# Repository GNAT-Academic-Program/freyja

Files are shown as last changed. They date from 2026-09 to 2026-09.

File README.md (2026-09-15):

# Odin

An FPGA dev board built on one idea: **remove the accidental complexity, so
what's left is the actual project.**

## Why dumb projects look complicated

Watch a student build a handheld game on a normal FPGA board. Where does the
effort go?

- Writing a memory controller, because the framebuffer doesn't fit in BRAM.
- Fighting the programming workflow, because loading a bitstream is a ritual
  involving a vendor GUI.
- Designing a power supply, because the LCD backlight needs 12V and the board
  offers 3.3V and 5V.
- Level-shifting, because half the parts are 5V.
- Reading a 400-page manual to find which pins share a bank.
- Guessing, when it doesn't work, because the board cannot tell them anything.

Roughly 80% of the effort, and **none of it is the game.** The project isn't
complicated. The scaffolding is. And because the scaffolding is where the time
goes, the finished thing looks far more impressive than the idea deserves —
which is its own kind of failure, because the student learned plumbing instead
of architecture.

## What's actually missing, and what Odin does

| Missing on normal boards | What it causes | Odin |
|---|---|---|
| **A middle rung of memory.** BRAM (KB) → cliff → DDR3 (nightmare) | Every project that outgrows BRAM becomes a memory-controller project | 4× PSRAM, 8 MB, four independent ports, predictable latency |
| **Scriptable programming.** JTAG blaster + vendor GUI | Can't run 40 variants overnight, so nobody experiments | RP-class supervisor owns config; one USB-C, no helper bitstream |
| **Self-observation.** No rail telemetry, no software power control | Superstition-driven debugging | Supervisor drives every enable, reads back every rail |
| **A real expansion standard.** Pmod is 8 pins/3.3V; FMC is a $200 connector and a 400-page spec | Every extension is bespoke, nothing composes | Keyed 16-pin modules, 16/32/64, documented in one page |
| **Rails on the connector.** 3.3V and 5V, take it or leave it | Half of every extension BOM is regulators | Four rails per module: VCCIO, +5V, fixed +3V3, selectable AUX |
| **A level-shifting story.** All-shifted (slow) or none (no 5V parts) | You find out which by burning a part | One buffered slot, eight direct. One table says which and why |
| **Docs a human reads.** 400-page reference manual | Nobody reads it; everyone guesses | One page per subsystem. Over two pages is a bug |

Each row of that table is a decision in this repo, and each one exists to
delete a category of work that was never the point.

## The legibility principle

50 MB/s per link, 2 MB per chip. That's modest. It is also **knowable** — you
can work out on paper, before writing a line of HDL, whether your design fits.

DDR3 offers "up to 12.8 GB/s," qualified by access pattern, bank conflicts,
refresh, and calibration. You cannot reason about it in advance. You build it,
measure it, and find out.

**A legible constraint teaches. An opaque abundance does not.** A student who
computes "640×480 at 60 Hz is 37 MB/s, one PSRAM link is 50, it fits" has
learned something transferable. A student who gets 12.8 GB/s from an IP core
has learned to instantiate an IP core.

This is why the numbers on this board are small and published rather than
large and asterisked.

## The honest ceiling

Odin is not fast. Some things do not fit, and pretending otherwise would
undermine the point:

- **1080p60** RGB565 needs ~249 MB/s. Four chips ganged give ~200. Doesn't fit.
- **720p60** is ~110 MB/s. Fits ganged, with headroom.
- **VGA 60 Hz** is 37 MB/s. Fits on a single link, leaving three ports free.
- Anything wanting sustained gigabytes per second wants DDR3 and a different
  board.

If you need the ceiling raised, this is the wrong board. If you need the floor
raised so you can get to the interesting part, this is the right one.

## The test for any future decision

> Does this remove work that was never the point, or does it add work that
> looks like the point?

Series resistors on shared config lines: removes work (a firmware bug can't
brick the board). Four independent PSRAM buses instead of one shared: removes
work (no arbiter to design). A 400-page pinout PDF: adds work.

Apply it to anything proposed for this board.

## Reference

- [`ref/user-manual.md`](ref/user-manual.md) — start here: powering, extensions, examples and recovery.
- [`ref/extension-ux.md`](ref/extension-ux.md) — the extension connector spec. One page. Read this first.
- [`ref/psram.md`](ref/psram.md) — memory: four independent ports, and why four.
- [`ref/supervisor-flash.md`](ref/supervisor-flash.md) — the supervisor's boot flash, and why you cannot brick it.
- [`ref/power-input.md`](ref/power-input.md) — one USB-C, PD at 9V, and why there is no battery on the board.
- [`ref/power-budget.md`](ref/power-budget.md) — generated: every rail's load, limit and spare, with the basis for each number.
- [`ref/qualified-parts.md`](ref/qualified-parts.md) — generated: the exact part in every non-generic position, and its ratings.
- [`ref/highspeed.md`](ref/highspeed.md) — the two fast serial ports and their reference clock.
- [`ref/gameboy-extension.md`](ref/gameboy-extension.md) — worked example: LCD, speaker, gamepad.
- [`ref/salvage-from-odin0.md`](ref/salvage-from-odin0.md) — what survives from last year's board.
- [`ref/ide-agent-prompt.md`](ref/ide-agent-prompt.md) — the review brief for the implementation agent.
- [`findings.md`](findings.md) — open issues against the current schematic.

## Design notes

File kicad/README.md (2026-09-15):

# Odin KiCad project

**Everything here is generated.** Do not hand-edit the `.kicad_sch` files,
`odin.kicad_sym` or `odin.pretty/` — edit the generators and re-run.

Six pages, one per functional block, from `odin.kicad_sch` (the root):

| Page | Contents |
|---|---|
| `fpga.kicad_sch` | FPGA, decoupling, configuration straps |
| `power.kicad_sch` | input, regulators, monitoring and five protected extension buses |
| `memory.kicad_sch` | PSRAM x4 and configuration flash |
| `supervisor.kicad_sch` | RP2350B, USB-C, flash, links to the FPGA |
| `slots.kicad_sch` | Nine extension slots, rail selection, fusing, shifting |
| `highspeed.kicad_sch` | SFP cages, reference clock, power gate |

Parts are grouped: each regulator sits in a dashed box with its own inductor,
feedback divider and capacitors; each slot with its jumper and its fuses.
Rails and grounds use real power symbols, so only actual signals carry a
label. Rearranging by hand means giving up regeneration — a fair trade once
the design settles, just know that is the moment you make it.

## Regenerate

```bash
python3 tools/gen_kicad.py      # normalize imported XC7A100T symbol + validate FGG676 footprint + custom parts
python3 tools/ballmap.py --write
python3 tools/budget.py --write # rail qualification -> ref/power-budget.md
python3 tools/qualified.py --write   # part table -> ref/qualified-parts.md
python3 tools/audit_easyeda.py # imported symbol/pad/LCSC consistency
python3 tools/gen_project.py    # schematic from tools/design.py
python3 tools/gen_pcb.py        # 6-layer board: outline, stackup, design rules
kicad-cli sch export netlist --format kicadsexpr -o kicad/odin.net kicad/odin.kicad_sch
python3 tools/load_pcb.py       # load every footprint and net into that board
```

`load_pcb.py` reads `kicad/odin.net`, so export the netlist before running it
or you will load the previous revision's parts.

`tools/budget.py --write` currently passes and regenerates the power budget.
The input-voltage issue in findings item 20 is fixed. The command exits
non-zero if a load, input-window or inductor qualification check fails.

**`gen_pcb.py` destroys any routing.** Run it only before you start laying out.
`load_pcb.py` re-imports footprints and nets and is safe to re-run, but it
replaces the footprints, so it also discards placement.

`tools/alloc.py` is the single source for ball allocation; `ref/ballmap.md` and
the schematic both come from it and cannot drift.

## Verify

```bash
kicad-cli sch erc --severity-all -o erc.rpt odin.kicad_sch
kicad-cli pcb drc --severity-all -o drc.rpt odin.kicad_pcb
kicad-cli sch export netlist --format kicadsexpr -o odin.net odin.kicad_sch
```

```bash
kicad-cli pcb drc --schematic-parity --severity-all -o drc.rpt odin.kicad_pcb
```

## Expected ERC

Run from the repository root after regenerating the library and schematic:

```bash
python3 tools/check_erc.py
```

Expected result: **zero errors and exactly two intentional warnings**:

| Rule | Item | Reason |
|---|---|---|
| `global_label_dangling` | `FPGA_DXP` | External temperature-diode terminal is intentionally exposed only as a label. |
| `global_label_dangling` | `FPGA_DXN` | External temperature-diode terminal is intentionally exposed only as a label. |

The U20 JTAG tri-state paths currently produce **no ERC warning**: the
existing series link on TDO separates the FPGA output and bus-switch pin.
There is no U20 blanket exclusion. Any new U20 warning, or any other finding
outside the exact list above, is a regression and makes `check_erc.py` fail.
A change to the expected labels also requires updating this table and the
checker together.

`tools/gen_kicad.py` normalizes imported connector/LED pin types to passive,
models J51 SWCLK/SWDIO (pins 1/3) as bidirectional debugger connections, and
assigns the PCF8574's actual supply, input, bidirectional and open-drain pin
types. J51 ground and mechanical pins remain passive. No project-level
ERC rule is disabled and no ERC exclusion is added.

Latest KiCad 9.0.8 validation: **498 footprints**, with all design values,
footprint IDs and connections synchronized to the PCB. DRC remains separate:
693 violations, 499 unrouted connections and two parity warnings for the
standard SFP symbol's `CAGE` pin missing from its 20-pad electrical connector.
The separate cages are SH1/SH2. See [the validation report](../ref/kicad-validation.md).
Passing the ERC allowlist does not establish fabrication readiness.

## Your workflow from here

1. Open `odin.kicad_pcb`. Its **498 footprints** are synchronized with the
   schematic. The SFP assemblies follow the mechanical placement contract;
   much of the remaining circuitry is still staged outside the board.
2. Complete placement using `tools/placement.py` / `tools/place.py` and verify
   the result in KiCad. The latest placement and validation status is in
   [ref/kicad-validation.md](../ref/kicad-validation.md). Resolve DRC findings
   as well as placement overlaps; the current reports include electrical errors.
3. Route.
4. Fabrication outputs:
   ```bash
   jlcpcb-export -p "$PWD/odin.kicad_pcb" --autoTranslate --autoFill --excludeDNP --noBackup
   ```

## Two checks that ERC and parity cannot do

`ki_fp_filters` catches a footprint that contradicts its symbol. It does not
catch a part that is the wrong part, or one that cannot survive the voltage on
its net. Two generators close that gap and both are enforced from
`tools/design.py`, so the netlist will not build if either fails:

- **`tools/qualified.py`** — MPN, manufacturer package code, footprint,
  ratings that matter here, and how the pin map was confirmed, for every
  non-generic part. A new IC cannot enter the design without an entry.
- **`tools/budget.py`** — per-rail worst-case load, regulator input window,
  inductor ripple, peak current and saturation margin. It fails if any
  inductor saturates below what its rail needs, or if a regulator's source can
  fall below its minimum input.

## LCSC part numbers — read this

Exact LCSC IDs are carried in the generated schematic/netlist for qualified
ICs, connectors and selected passives. Other passive values still need BOM
matching against the required package, tolerance and voltage rating. Use
[the import checklist](../ref/jlcpcb-import-checklist.md) and the generated
[qualified-parts table](../ref/qualified-parts.md); do not substitute a nearby
suffix without checking its package and ratings.

## Board

100 x 100 mm, 6 layer, ENIG, nominal 1.6 mm. Stackup is F.Cu (signal) /
In1.Cu (GND plane) / In2.Cu (signal) / In3.Cu (power planes) /
In4.Cu (GND plane) / B.Cu (signal). The third routing layer supports the
FGG676 inner-ball escape. Keep both ground planes continuous for the GTP
pairs and PSRAM groups.

Dielectric spacings follow [JLC06161H-1080B](https://jlcpcb.com/impedance),
with 0.0764 mm outer prepregs and 0.1 mm cores next to the inner signal and
power layers. The central prepreg/core/prepreg spacer is represented as a
three-sublayer, 1.1208 mm dielectric. Material Dk values and the 100 Ω
geometry come from JLC's calculator tables; see [PCB impedance](../ref/pcb-impedance.md)
for the inputs and saved solver responses. MGT outer tracks use 0.099 mm width /
0.200 mm gap with 0.1 mm maximum intra-pair skew. PSRAM has a 0.1 mm minimum
width; default clearance is 0.15 mm.

Regenerate stackup and rules without replacing placement or routing:
`python3 tools/gen_pcb.py --rules-only`. Net classes live in `odin.kicad_pro`;
DRC constraints live in the generated `odin.kicad_dru`.

A–H are eight logical zones carried by four
continuous 2x16 signal bodies and four parallel 1x16 power bodies; L is one
separate 2x8 connector.
Placement and routing are intentionally not started.

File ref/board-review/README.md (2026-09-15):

# Board review snapshot

Exported 2026-09-15 with KiCad 9.0.8 from the current working-tree board.
This commit records review artifacts; the source hashes in
[board-state.json](board-state.json) identify the exact uncommitted source
state used for export.

- **498 footprints.** Placement is incomplete: 494 footprint origins are
  outside the outline's 100 × 100 mm bounding box (X/Y 30–130 mm).
- **6 copper layers**, in both `odin.kicad_pcb` setup/stackup and
  `tools/gen_pcb.py`: F.Cu / In1.Cu / In2.Cu / In3.Cu / In4.Cu / B.Cu.
  KiCad's loaded copper-layer count also equals 6.
- DRC with **all severities, including exclusions**, plus schematic parity:
  **693 violations, 499 unconnected items, 2 parity issues**. Command exit
  status is 0; this does not mean the board passes fabrication DRC.

## Exports

- [Full DRC report](odin-drc.rpt)
- [DRC command and complete console output](drc-console.txt)
- [Current board SVG: F.Cu + Edge.Cuts + F.CrtYd](odin-placed.svg)
- [SVG command and console output](svg-console.txt)
- [Counts, layer comparison and source SHA-256 hashes](board-state.json)

The SVG includes all staged components outside the outline, rather than
cropping them from the review. No component was moved for this export.

SVG export trailing whitespace was removed; geometry is unchanged.

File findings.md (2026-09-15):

# Odin — findings

Two eras are recorded here. **Items 1–4 are historical** — they describe the
EasyEDA/Altium input set and are closed: the design now lives in `kicad/`,
generated from `tools/`, and those inputs are reference material only. **Items
5 onward are live**, against the current KiCad design.

Regenerate everything with the commands in `kicad/README.md`.

---

# Part I — historical (EasyEDA era, closed)

*Kept for the reasoning, not as open work. The netlist/BOM/pcbdoc revision
mismatch that these describe is moot now that the design is generated.*

## 1. BLOCKER — the netlist, BOM and pcbdoc are the *previous* revision

**Entities:** `Netlist_Odin_0_2026-09-02.net`,
`BOM_Odin_V1.0.0_Odin_0_2026-09-02.xlsx`, `Odin_V1.0.0/Odin_0.pcbdoc`
versus `Odin_V1.0.0/Odin/*.schdoc`.

**What is wrong.** The netlist and BOM agree with each other exactly (0
designators netlist-only, 0 BOM-only) and both agree with the pcbdoc. All
three describe a **single-FPGA ECP5 board programmed over an FT232H**. The
schdoc export describes a **different, later board**: Artix-7 + ECP5 + RP2040
with a new power tree. Only 9 of 40 schdoc part types appear in the netlist
(`odin.srcdiff`).

Present in the schdocs, absent from netlist/BOM/pcbdoc:

| Part | Schdoc symbols | Role |
|---|---|---|
| `XC7A50T-2CSG325I` | 8 | the Artix-7 that Goals 1–2 are about |
| `RP2040_C2040` | 1 | the supervisor that Goal 1 is about |
| `W25Q32JVZPIQ` | 1 | RP2040 boot flash |
| `TPS563257DRLR` | 6 | new buck rails |
| `TPS55340RTER` | 1 | boost |
| `TPS25940ARVCR` | 1 | eFuse |
| `APS1604M-3SQR-SN` | 4 | PSRAM |
| `SN74LXCH8T245PWR` | 4 | level shifters |
| `ADS7950SBRGET` | 1 | ADC |
| `2.54-2*8P_`, `PM2.54-1X8PM-H85`, `ZX-PZ2.54-2-4PZZ`, `PH2.54-01-03PZD` | 6/4/4/4 | new extension headers |

Present in netlist/BOM/pcbdoc, absent from the schdocs: `FT232HQ-REEL`,
`IS61WV25616BLL-10BLI`, `FM25V02A-GTR`, `TLV62569DRLR` ×3, `TPS54202DDCR` ×4,
`TYPE-C-31-E-07`, `TYPE-C-31-M-12`, `PS-1049SVD-4PN`.

**Consequence for the prompt's ground rules.** The prompt makes the Protel
netlist the identity source and forbids citing schdoc refdes. That rule cannot
be satisfied: the netlist contains no Artix-7 and no RP2040, so there is no
real designator to cite for any part in Goal 1. Symbol matching bears this
out — 25 of 230 schdoc symbols map to a netlist part (`odin.desigmap`), and
the matches are confined to the 9 shared part types.

**Proposed change (EasyEDA).** Re-export both the Protel netlist and the BOM
from the schematic that contains the Artix-7 and RP2040 — the one exported to
`Odin_V1.0.0/Odin/`. In EasyEDA Pro the netlist is exported per board, and
`Odin_0` is the old board; the new schematic appears to have no board/PCB yet,
which is why its netlist was never produced. If the new schematic needs a PCB
created before a netlist can be exported, that is the prerequisite step.

---

## 2. BLOCKER — the ECP5 is still instantiated in the new schematic

**Entities:** `LFE5U-25F-6BG256C`, 9 symbol parts on `fpga.schdoc`.

**What is wrong.** You have confirmed the ECP5 is a mistake and the board is
meant to be dual Artix-7. It is not a stray symbol: in the *old* netlist the
same part is `U1` with **170 connected balls**, driven through an
`SN74CB3T3245PWR` level shifter on a `TOL_*` bus. Whatever of that carried
into the new schematic is real wiring, not a placement error, so removing it
is a schematic-scale edit rather than a symbol delete.

**Proposed change (EasyEDA).** Delete the `LFE5U-25F-6BG256C` symbol parts
from `fpga.schdoc` and replace with a second `XC7A50T-2CSG325I`. The second
Artix-7 needs its own config chain — flash, `PROG_B`/`INIT_B`/`DONE`, `M[2:0]`
strap, JTAG — which feeds directly into item 3.

**Blocked on item 1**: I cannot enumerate which nets the ECP5 currently holds
in the *new* schematic, only in the old one.

---

## 3. BLOCKER — RP2040 GPIO count cannot carry Goal 1; assume RP2350B

Per your decision, the review will be run against an **RP2350B (48 GPIO)** and
the swap reported as a blocker. The sizing that forces it, for a dual Artix-7
board with the supervisor scope in Goal 1:

| Function | GPIO |
|---|---|
| Config flash SPI (CS, CLK, MOSI, MISO), shared across both FPGAs | 4 |
| Second flash CS (one CS per FPGA, bus shared) | 1 |
| FPGA A config: `PROG_B`, `INIT_B`, `DONE`, `CCLK`, `DIN` | 5 |
| FPGA B config: same | 5 |
| `M[2:0]` ×2 — driven, not hard-strapped, to switch master-SPI vs slave-serial | 6 |
| FPGA JTAG (TCK/TMS/TDI/TDO), both parts daisy-chained on one port | 4 |
| Fabric sideband JTAG for NEORV32 debug | 4 |
| Sideband UART TX/RX | 2 |
| Spare GPIO bus | 4–8 |
| Regulator enables (8 rails: 6× buck, boost, eFuse) | 8 |
| Power-good readback | 8 |
| Extension board-ID | 2–4 |
| **Total** | **53–59** |

Against 30 on an RP2040 this overflows by roughly 2×; against 48 on an
RP2350B it still overflows unless something gives. The cheapest reductions
that keep the "direct wiring" philosophy:

- **Hard-strap `M[2:0]`** to master-SPI and reach slave-serial by holding
  `PROG_B` and driving `CCLK`/`DIN` only — saves 6, and `M[2:0]` is a
  build-time choice, not a runtime one.
- **Share one JTAG port** across both Artix-7s via the standard daisy chain —
  already assumed above, saves 4.
- **Power-good as a single wired-OR fault line** plus per-rail readback over
  the ADC already on the board (`ADS7950SBRGET`, 12-bit 16-ch) — saves 7,
  and rail voltage readback is strictly better information than a PG bit.

With those three, the count lands near **40**, which fits a RP2350B with
headroom for the spare bus. This is a proposal, not a verified finding —
confirming it needs item 1.

---

## 4. Extension connector keying — the 16-pin unit reads as 14 + 2

You asked me to work out the pattern. From the old netlist, where the
connectors are fully wired, one group is:

- `J4` `2.54-2*7P母` — 2×7 female, **14 pins**
- `H5` `3-644456-2` — 2×1, **2 pins**
- `P3` `2.54-1*1P针` — 1×1 male post, **1 pin**

14 + 2 = **16 pins = 8 columns × 2 rows**, with the 1×1 post as the
polarizing key. There are 8 of each (`J4–J11`, `H5–H12`, `P3–P10`), so the old
board carries **8 × 16 = 128 positions**, i.e. two 64-pin extension sites of
four 16-pin patterns each — which is the 16/32/64 prefix rule you described,
and the split into a 7-column block plus a 1-column block is what makes the
mating polarity unambiguous.

Two cautions. First, this is the **old** board; the new schdocs carry a
different connector mix (`2.54-2*8P_` ×6, `PM2.54-1X8PM-H85` ×4,
`ZX-PZ2.54-2-4PZZ` ×4, `PH2.54-01-03PZD` ×4 alongside the 8× `2.54-2*7P_` and
8× `3-644456-2`), so the new pattern is not yet 14+2. Second, your arithmetic
"8+7+1" counts *columns* and reaches 16 columns (a 2×8 block + a 2×7 block + a
key), which matches the new schdoc's part mix rather than the old board's. If
16 **columns** (32 pins) is the intended unit, then a 64-**column** extension
is 128 pins, and the new mix is the right one. Which of the two — 16 pins or
16 columns — is the unit needs to be your call; item 1 has to land first
either way, since `ref/extension-pinout.md` needs real designators and FPGA
bank data.

---

## Steps not yet run

| Step | Status |
|---|---|
| 0 setup | done — baseline commits, `ref/adabmp` cloned, `extract.py` read |
| 1 netlist-first IR | tooling done; output is of the wrong revision (item 1) |
| 2 FPGA datasheet facts | not started — blocked on the Artix-7 count (item 2) |
| 3 power review | not started — the new power tree is in no netlist |
| 4 config/boot review | not started — no RP2040 in any netlist |
| 5 extension connector | not started — see item 4 |
| 6 Gameboy gap analysis | not started — depends on step 5 |
| 7 BOM check | partial — the BOM is self-consistent with the old netlist; every placed part has an LCSC number; see below |

**Step 7, valid only for the old revision.** Zero JLCPCB stock:
`TC211A106M016Y` (C128289, 10 parts) and `CA45-A6R3K226T` (C122912, 4 parts).
Near-zero: `RT1206FRE07120KL` (C136861, stock 9), `2NM27000C33YC` (C668764,
stock 3), `1SMA5918A` (C19077487, stock 71), `FT232HQ-REEL` (C82158, stock 28)
— the FT232H is being removed anyway. 51 of 56 BOM lines are Extended Part;
only `0603WAF8202T5E`, `0603WAF5101T5E`, `0603WAF200JT5E` are Basic. Most of
the Extended lines are ordinary 0402/0603 passives with Basic equivalents;
that consolidation pass is worth doing once the BOM is re-exported, not now.

---

---

# Part II — live, against the current KiCad design

## 5. FIXED — differential oscillator pinout confirmed

**Entities:** `X2`, `DSC1123CI2-125.0000` (`C617173`), footprint
`EasyEDA:OSC-SMD_6P-L3.2-W2.5-BL`.

The Microchip datasheet and imported part agree: 1 EN, 2 NC, 3 GND, 4 OUT+,
5 OUT-, 6 VDD. This differs from the old assumed mapping; the schematic now
uses the imported exact symbol and footprint.

## 6. FIXED — MGTRREF was connected to the wrong rail

**Entities:** `R35` (formerly `R30`), 100R 1% 0603, from `U1.A15`
(`MGTRREF_216`, FGG676) to `+1V2_MGT` (MGTAVTT).

The old circuit used 100R to GND with no explicit tolerance. The ground
connection was wrong. [UG482 v1.9, Figure 5-1 and pp. 217–219](https://0x04.net/~mwk/xidocs/ug/ug482_7Series_GTP_Transceivers.pdf#page=218)
specifies 100 ohm, 1% to MGTAVTT for Artix-7 GTP calibration, not 499/500 ohm
to GND. The design source, schematic, netlist and PCB now specify `100 1%`
and connect the resistor to the 1.2 V MGT supply. This closes the schematic
error; high-speed link performance still requires hardware validation.

## 7. FIXED — board outline now matches the mechanical contract

`kicad/odin.kicad_pcb` is now 100 x 100 mm, matching the required board size.
A–H use four continuous 2x16 signal bodies plus four parallel 1x16 power
bodies (two logical zones per body), plus two complete 5V-bus signal and power
connector pairs. Placement
and routing remain deliberately absent. The exact stack-through connector MPN
is still a mechanical purchasing choice; the schematic fixes 2.54 mm pitch.

## 8. FIXED — nonexistent extension board-ID promise removed

**Entities:** `ref/extension-ux.md`, the nine slot connectors, `PD_CFG1..3`.

An earlier `ref/extension-ux.md` stated that each module had board-ID pins so
the supervisor could tell what was plugged in. **It had none.** The four
`BOARDID_*` nets that existed went to the supervisor and a pull-down each and
reached no connector; they have since been repurposed for the USB-PD sink,
which genuinely needed them.

The options considered were:

1. **Give up one I/O per module** for a strapped ID pin.
2. **Drop the claim.** Extensions are identified by the human. Honest, and
   costs nothing but the feature.
3. **Widen the module** solely to add identification.

Option 2 was chosen. The claim and dead nets are gone. The newer third power
row is used for clear, well-grounded power distribution, not to silently
reintroduce an identification protocol. The supervisor still power-gates the
extension rails and reports SFP module identity.

## 9. FIXED — the supervisor could not enable its own power rail

`EN_3V3` was driven by supervisor GPIO21 and gated `U12`, which produced the
+3V3 that powers the supervisor. A deadlock: the board could never start.
`EN_5V` compounded it, since +3V3 was derived from +5V.

Fixed: +3V3 is now always on, from a wide-input `AP63300` (`U12`) straight off
`VSYS`. Its datasheet permits automatic startup with EN floating, so no GPIO
is involved. GPIO21 was freed and reused for the VBUS pass switch below.

## 10. FIXED — a Schottky from VBUS to the 5V rail was an overvoltage hazard

`D2` fed USB `VBUS` into the +5V rail so the board could run from a plain 5 V
source. The moment the PD sink negotiated 9 V, that diode would have put
~8.6 V onto a rail feeding four `TLV62569` regulators rated 5.5 V maximum —
destroying them on the first PD handshake.

Fixed: replaced with a supervisor-commanded high-side switch (`Q2` P-MOS,
`Q3` gate driver), **default open**. Firmware measures `VSYS` and only closes
it when the input really is 5 V.

## 11. CLOSED — level translator pinout confirmed

**Entities:** `U9`, `U10`, symbol `odin:SN74LXC8T245PW`.

The original `SN74AVC8T245PW` was wrong: the AVC family is specified for
1.2–3.6 V supplies and 5 V on `VCCB` exceeded its absolute maximum. It has been
replaced with `SN74LXC8T245PW` (1.1–5.5 V both rails).

KiCad ships no symbol for it, so the generated one is AVC8T245's symbol
renamed. That mapping has since been checked against TI's TSSOP-24 pinout for
`SN74LXC8T245PW` — 1 `VCCA`, 2 `DIR`, 3–10 `A1..A8`, 11–13 `GND`, 14–21
`B8..B1`, 22 `OE`, 23–24 `VCCB` — and matches. **Closed.**

## 12. FIXED — two complete 5V buses replace the 8+2 orphan

`SN74LXC8T245` is direction-controlled: one `DIR` pin steers eight signals
together. An earlier Slot L was an eight-bit bus plus an awkward two-bit tail,
costing 12 FPGA I/O for ten connector signals. A two-bit Nexperia converter
was briefly qualified for that tail, but optimizing the orphan did not fix the
interface. Odin now provides two identical complete eight-bit 5V buses, each
with one direction control. The second bus uses fixed bank 13.

`ref/extension-ux.md` now says this plainly. If per-pin bidirectional 5 V is
actually wanted, the part is a `TXB0108`-class auto-direction translator,
which trades away drive strength and forbids external pull-ups. There is no
option that gives strong drive, per-pin direction and 5 V at once.

## 13. partly fixed — qualify the placeholder components before layout

Inductor saturation current and capacitor voltage rating are not purchasing
details — a 22 µF 6.3 V part on the 12 V AUX rail fails immediately, and an
undersized inductor saturates under load. These need real part numbers
**before layout**, not before ordering, because package size affects
placement.

**Done since:**

- **A qualified-parts table exists and is enforced.** `tools/qualified.py`
  records MPN, manufacturer package code, footprint, the ratings that matter
  on this board, and how the pin map was confirmed, for every non-generic
  part. `tools/design.py` refuses to build if a part is missing from it or is
  fitted with a different footprint, so a new IC cannot enter the netlist
  anonymously. Rendered to `ref/qualified-parts.md`.
- **Every inductor is selected and checked.** `tools/budget.py` computes the
  ripple, peak current and required saturation current per rail and names the
  part: `SRN6045TA-100M` (10 µH, Isat 4.6 A) on `U11` and the boost,
  `SRN6045TA-4R7M` (4.7 µH, Isat 6.8 A) on `U12`, `SRN4018-2R2M`
  (2.2 µH, Isat 3.0 A) on the four `TLV62569`s,
  `SRN4018-1R0Y` on the MGT filter, and the mandated Abracon part on the
  supervisor. The tool fails if any of them saturates below its rail's
  requirement.
- **MOSFETs are real parts.** `Q1` and `Q2` are `DMG2305UX`; `Q3` is a
  `BSS138`. Reading the DMG2305UX datasheet is what turned up item 21.
- **Capacitors on rails above 3.3 V carry their rating in the value field**,
  set automatically from the net rather than typed: `25V` on `VSYS`, `VBUS`
  and `+12V`. Everything unmarked is 16 V minimum, X5R or better.

**Still open:**

- The SFP electrical connectors are selected; their separate metal cages are
  still not encoded because the `C5164658` mechanical import failed.
- The nine 300 mA +3.3 V polyfuses still need an exact MPN. The 200 mA and
  500 mA positions are selected.
- **Capacitor DC-bias derating is not accounted for.** A 22 µF 25 V X5R 0805
  at 12 V retains well under half its nominal value. The bulk capacitance is
  ample enough that this is unlikely to bite, but "22 µF" on the `VSYS` rail
  means perhaps 8 µF in circuit and nothing in the design says so yet.
- The ~340 ordinary passives can take LCSC numbers later via the JLCPCB
  plugin.

## 14. open — the 16/32/64 mechanical claim is unproven

Adjacent 16/32/64 module compatibility is a *mechanical* property: it depends
on slot pitch, board-edge geometry and the position of the keying posts, none
of which exist until placement. The electrical numbering supports it. Verify
it on the board, and until then treat the claim in `ref/extension-ux.md` as an
intent rather than a fact.

## 15. FIXED — the JTAG owner is now selected in hardware

`J2` sits directly in parallel with the FPGA's JTAG nets. The supervisor is
separated only by its 33 R series resistors, so an external programmer and a
misbehaving supervisor GPIO can both drive the same line. The comment claiming
a jumper isolates the supervisor was wrong and has been corrected.

Two ways to make it true:

1. **Firmware contract** (currently assumed): the supervisor tri-states
   GPIO0–3 whenever an external programmer may be attached, and does so as its
   *reset default*, not only when asked. Free, but it depends on firmware
   being correct — which is a poor guard for a debug path you reach for
   precisely when things are broken.
2. **A bus switch** (`SN74CB3T3245`, the part Odin_0 used) between the
   supervisor and the JTAG net, with its enable strapped or jumpered. Real
   isolation. Costs one part and one control line, and there is no spare
   supervisor GPIO — it would have to be a physical jumper.

Recommendation: option 2 with a jumper, because "hold the board in a known
state so I can debug it" should not itself depend on working firmware.

**Fixed with option 2.** `U20` is an `SN74CB3Q3384APW` 10-bit FET bus switch;
the supervisor's four JTAG lines pass through bank 1 (`1A1..1A4` to
`1B1..1B4`) on their way to the FPGA and to `J2`. `~{1OE}` is held low by a
10 k pull-down, so the switch is closed and the supervisor owns JTAG in the
shipped state — that is the primary programming path and it has to work out of
the box. Fitting **`EXT JTAG` (`J52`)** pulls `~{1OE}` to +3V3
and takes the supervisor electrically out of the chain, whatever its firmware
is doing. The controlling net is named `EXTERNAL_JTAG_SELECTED`, so its high
state says exactly what happened.
Bank 2 is unused with `~{2OE}` tied high.

This adds one intentional ERC warning: the FPGA's `TDO` output meets a
tri-state switch pin, which is what a FET bus switch pin always looks like to
ERC.

## 16. FIXED — RP2350 support parts now match the reference design

`U7`'s internal switcher uses a generic `3.3uH SRN4018` inductor and generic
15 pF crystal loading capacitors. Raspberry Pi's hardware-design guide is
explicit that RP2350's on-chip regulator depends on the prescribed inductor
selection, orientation and placement, and on specific capacitor choices.

This is a **netlist-level** task, not a layout note: copy the exact component
values and manufacturer part numbers from the RP2350B minimal-board reference
into `tools/design.py`, then follow the placement guidance during layout.
Getting this wrong produces a supervisor that mostly works, which is the worst
failure mode available.

**Fixed, from RP-008280 sections 2.1, 2.2.1, 3 and 4:**

| Reference | What it is | Now in the netlist |
|---|---|---|
| `L1` | `AOTA-B201610S3R3-101-T`, the 3.3 µH part Abracon made for Raspberry Pi with a polarity dot | `L1`, on a generated `odin:L_Abracon_AOTA-B201610S_2.0x1.6mm` land taken from the datasheet's Recommended Land Pattern (1.00 × 1.60 mm pads, 1.00 mm gap) |
| `C6`, `C7`, `C9` | 4.7 µF 0402 at `VREG_VIN`, at the output, and on `VREG_AVDD` | three 4.7 µF 0402 |
| `R3` | 33 Ω, RC-filtering the analogue supply | 33 Ω 0402 into net `SUP_VREG_AVDD` |
| `Y1` | `ABM8-272-T3`, 12 MHz, CL 10 pF, ESR 50 Ω max | named in the value field |
| `R2` | **1 kΩ in series with `XOUT`**, so the crystal is not over-driven | added; it was missing entirely |
| `C3`, `C4` | 15 pF at the crystal terminals | were already right, and now sit on the crystal side of `R2` |
| `R1` | 10 kΩ pull-up on `QSPI_SS`, shipped Do-Not-Fit | added, DNP |
| decoupling | one 100 nF per supply pin | 11 on +3V3 (8 IOVDD, QSPI_IOVDD, USB_OTP_VDD, ADC_AVDD) and 3 on +1V1 (3 DVDD) |

The 1 kΩ `XOUT` resistor is the important one: without it the crystal is
over-driven, which is a slow reliability failure rather than an obvious one.

**Still a layout obligation.** Raspberry Pi are explicit that the regulator's
performance depends on the inductor's *orientation* as well as its part
number, and on their exact placement. The footprint carries a polarity dot on
silk and a solid pin-1 marker on `F.Fab` so the requirement survives into the
assembly drawing, but honouring it is placement work, guided by RP-008280
Figure 4.

## 17. FIXED — eleven components had footprints for the wrong package

Symbol and footprint disagreed on the physical package for `U2`–`U6`, `U8`,
`U13`–`U16`, `U17`, `U18`, `U19` and `D6`. Neither ERC nor schematic parity can
see this class of error; it surfaces at assembly.

Corrected: PSRAM to SOP-8 150 mil, `W25Q256JVEIQ` to WSON-8 8x6, `W25Q32JVZP`
to WSON-8 6x5, `TLV62569DRL` to SOT-563, `CH224K` to SSOP-10-1EP, `PCF8574T`
to SOIC-16W, `TPS61085PW` to TSSOP-8 4.4x3, `ESDA6V1BC6` to SOT-23-6.

**Prevented from recurring:** `Design.add()` now checks every footprint against
the symbol's `ki_fp_filters` and refuses to build on a mismatch. The one
deliberate exception is the polyfuse, where KiCad ships no `*polyfuse*`
footprint and a 1206 chip PTC is the physically correct package; that override
is explicit in the source and carries its reason.

## 18. FIXED — per-slot fuse ratings implied nine times the available current

Nine slots x 500 mA suggested 4.5 A per rail. The real sources are far
smaller. Fuse ratings have been rebalanced (AUX 200 mA, +3V3 300 mA, +5V
500 mA) and `ref/extension-ux.md` states the shared budget per rail
explicitly, with the note that fuses are fault protection and not an
allowance.

The `~700 mA` first quoted for AUX was `5 V x 2 A x η / 12 V` — an ideal
upper bound from a nominal switch rating, not an available current. It has
been replaced by TI's own design procedure (SLVS859B equations 1–4) at the
worst-case input, run by `tools/budget.py`:

- the boost, with a 10 µH inductor at 650 kHz and the **2.0 A minimum**
  switch limit, can deliver **622 mA**;
- but AUX at full output draws 1766 mA from a +5 V rail with 1615 mA spare,
  so the binding limit is **570 mA**, and the constraint is the 5 V rail, not
  the boost;
- and that is still arithmetic at an assumed 90% efficiency with no thermal
  derating, so it is published as a **provisional design target**.

The inductor changed as part of this: 4.7 µH at 650 kHz sat outside TI's
recommended 6–13 µH range and gave 69% ripple. 10 µH gives 26% ripple *and*
more output current.

Every other shared-rail figure was equally unsubstantiated. `+3V3` was
described as having "~1.5 A spare"; the worst-case load table puts it at
**500 mA**, because `U12` also carries the supervisor, four PSRAMs, the config
flash, FPGA bank 14, the oscillator, two SFP modules (610 mA on their own) and
both VCCIO domains when they are jumpered to 3.3 V. See
`ref/power-budget.md`.

## 19. constraint — firmware must never request more than 9 V over USB-PD

`D7` is an `SMBJ13A`, a 13 V standoff TVS on `VBUS`. The `CH224K`
configuration pins are supervisor-driven, so this limit lives in firmware and
must be an assertion there, not a comment. Raising the ceiling means
re-selecting `D7` first.

Two corrections to how this was first written. The mechanism is **avalanche,
not forward conduction**: the part is unidirectional with its cathode on
`VBUS`, so a 20 V contract drives it into sustained reverse breakdown, which a
600 W *transient* device does not survive as a DC condition. Forward
conduction is what happens if it is fitted backwards, which is a different
failure — and the reason the schematic no longer uses KiCad's bidirectional
`Device:D_TVS` symbol. And the margin is narrower than "13 V" suggests but not
zero: `VBR` is 14.4 V minimum, so a 15 V contract sits in the region above the
rated standoff where leakage climbs steeply rather than in hard avalanche.

## 20. FIXED — the always-on +3V3 rail now starts on a weak 5 V port

**Entities:** `U12` (`AP63300WU-7`), `D3`, `U26`, net `VSYS`.

The original `TPS54202` needed 4.5 V at its input, while the weak-host path
could provide only about 4.24 V after protection and OR-ing. It was therefore
wrong for the one rail that must always start.

`U12` is now an `AP63300WU-7`, rated from 3.8–32 V and 3 A. The worst-case
path is now:

| | |
|---|---|
| `VBUS` on a weak host port, guaranteed minimum | 4.75 V |
| less `D3` forward drop | −0.45 V |
| less conservative `U26` on-resistance drop | −0.03 V |
| **`VSYS`** | **4.27 V** |
| `AP63300` minimum input voltage | **3.8 V** |

That leaves 0.47 V of startup margin. Its 3.3 V feedback network, 4.7 µH
inductor, input capacitor, three output capacitors, bootstrap capacitor and
feed-forward capacitor copy the manufacturer's reference circuit.
`tools/budget.py` checks its full load and inductor peak current and passes.

## 21. FIXED — Q2 gate overvoltage under a 9 V firmware fault

**Entities:** Q2 (DMG2305UX), Q3, R49, EN_VBUS5.

R49, between VBUS5_PULL and VBUS5_GATE, is now **47k**, replacing 10k.
Together with the existing 100k gate-source pull-up, it sets
`VGS = -VBUS * 100/(100+47)`: -3.40 V at 5 V and -6.12 V at 9 V.
Even 9.45 V with 1% resistor tolerances gives only 6.47 V magnitude,
below the [DMG2305UX's ±8 V gate limit](https://www.diodes.com/datasheet/download/DMG2305UX.pdf).

The weaker gate drive at 5 V increases on-resistance compared with -4.5 V
characterization. With the existing 100nF gate-source capacitor, the gate
RC time constant becomes approximately **3.20ms**; it is not a specified
linear output ramp or current limiter. Firmware must still forbid turning
Q2 on at 9 V, because doing so overvolts the +5V rail and its loads.

## 22. FIXED — screw-terminal input lacked a transient clamp

**Entities:** J50, new D8, VIN_EXT, D4, VSYS.

Added **SMBJ15A-13-F / C135046** on VIN_EXT, before D4, with cathode on
VIN_EXT and anode on GND. The standard SMB footprint uses pad 1 cathode,
pad 2 anode. Put it at J50 with a short, wide surge-current return to J50 GND.

[Diodes rates this unidirectional TVS](https://www.diodes.com/part/view/SMBJ15A)
at 15 V standoff, 16.7–19.2 V breakdown, 24.4 V maximum clamp at its rated
pulse current, and 600 W pulse power. It suppresses transients; it is not a
15 V regulator or a sustained-overvoltage disconnect. A bench supply left
at 24 V can still overload the TVS. The permitted input remains **9–14 V**;
continuous fault protection would require current limiting/fusing or cutoff.
PCB parasitic overshoot and surge energy still require validation.

## 23. FIXED — the `VSYS` monitor divider overdrove the supervisor's ADC

**Entities:** `MON_VSYS`, `MON_5V`, `GPIO40/ADC0`, `GPIO41/ADC1`.

The divider was 100 k / 33 k, which is 33/133 of the input. At 9 V that reads
2.23 V and is fine. At the 20 V `ref/power-input.md` then permitted on `J50`
it reads **4.96 V** — onto an RP2350 GPIO whose maximum is `ADC_AVDD`, 3.3 V.
A rail monitor that destroys the microcontroller in the fault it exists to
report is the wrong way round.

Fixed by sizing every monitor divider from an **absolute maximum**, not a
nominal:

| Monitor | Divider | Nominal reading | At absolute maximum |
|---|---|---|---|
| `MON_VSYS` | 100 k / 16 k | 1.24 V at 9 V | 2.76 V at 20 V |
| `MON_5V` | 100 k / 47 k | 1.60 V at 5 V | 2.88 V at 9 V |

`MON_5V` was 100 k / 100 k, safe at 5 V and 4.5 V in the same firmware fault
item 21 describes; it is now sized for that fault too.

`tools/design.py` computes both from `adc_divider()`, which rounds the bottom
resistor **down** through E24 — rounding to nearest can put the result back
over the ceiling — and raises if the absolute maximum would exceed 3.0 V.
E24 rather than E96 because firmware calibrates a monitor ratio, so precision
buys nothing and stock availability buys something.

Each of the six monitor nodes also gained a 100 nF capacitor. Two reasons: the
ADC's sample-and-hold needs charge that a 14 kΩ Thevenin divider cannot
supply, and firmware compares these readings against thresholds, so switching
ripple should not be in them.

## 24. FIXED — USB attach inrush exceeded the specification by 5x

**Entities:** `U26`, `D3`, `VBUS`, `VSYS`.

USB limits a device's `VBUS` bypass capacitance to 10 µF, or 50 µC of inrush
charge; USB-PD raises that to `cSnkBulkPd` = 100 µF only *after* a contract
exists, and at cable insertion there is no contract. The board presented
10 µF on `VBUS` plus 44 µF of `VSYS` bulk through a forward-biased `D3` —
about 54 µF and 270 µC, five times the allowance. Symptoms would have been
source droop, connector arcing, and starting reliably on some chargers and not
others.

Fixed with `U26`, a `TPS259470A` eFuse. Its 2.2 nF `dVdt` capacitor sets an
approximately 0.91 V/ms output rise, so 44 µF charges at about 40 mA. It is
autonomous rather than firmware-controlled: this path produces +3V3, which
firmware needs in order to exist. UVLO is about 3.75 V, OVLO about 9.98 V and
the typical current limit about 2.03 A. The 10 µF left directly on `VBUS` is
the attach allowance, spent deliberately.

`Q2` has a series gate resistor and 100 nF gate-source capacitor because
closing it connects `VBUS` to 66 µF of +5V bulk. R49 is now 47k (item 21),
giving a 3.20ms gate RC time constant with the 100k pull-up. This provides
slew control, not a specified inrush-current limit.

Unlike the passive RC, the eFuse also controls PD voltage-transition current
and disconnects on an overvoltage request. `D7` remains the independent TVS;
firmware must still enforce the 9 V PD ceiling in item 19.

## 25. FIXED — extension power faults could reach the base-board rails

**Entities:** `U21`–`U25`, `EXT_EN`, `EXT_FAULT`, all slot power PTCs.

Every connector rail previously branched directly from an internal rail. A
short, back-powered shield or large startup capacitor could therefore pull
down or energize the FPGA, supervisor and memories through the shared source.

There are now five protected connector buses. Four `TPS22950CDDCR` switches
protect +5 V, +3V3 and the two selectable VCCIO domains. A
`TPS259470LRPWR` protects +12 V with true reverse blocking, 13.2 V nominal
OVLO, a 500 mA typical limit, controlled rise and latch-off. All switches have
a hardware-default-off `EXT_EN`; their fault outputs wire-OR to `EXT_FAULT`.
The old per-slot PTCs remain downstream.

`TPS22950C` has an off-state output-discharge path. With an extension applying
5 V, its nominal 160 Ω path draws about 31 mA and dissipates about 0.16 W;
reverse current into the internal source remains blocked. Its output absolute
maximum is 6 V, so this closes the stated 5 V-on-low-rail mistake, not an
arbitrary 12 V miswire. That boundary is now explicit in the user documents.

## 26. FIXED — larger FPGA has a 4 A 1.0 V supply

**Entities:** `U1`, `U15`, the +1V0 inductor, the future FPGA image.

`U1` is now `XC7A100T-2FGG676I` (`C1521803`) in the imported 676-ball,
27 x 27 mm package. Its 676 symbol pin numbers match all 676 footprint pads,
every supply ball is connected. Both GTP supply groups remain powered:
G10 serves quad 213 and G11 serves quad 216 (UG482 Table 5-2).

The unused-quad wiring is now corrected in `tools/gen_sch.py:net_for()`.
Quad 213 has all eight RX pins grounded and its own 100R 1% resistor (`R89`)
from `MGTRREF_213` to MGTAVTT; its TX and reference clocks float. Quad 216's
unused lanes 2/3 also have their RX pins grounded and TX pins floating.
These follow [UG482 Tables 5-5 and 5-6](https://0x04.net/~mwk/xidocs/ug/ug482_7Series_GTP_Transceivers.pdf#page=223).

U15 is now a 4 A `SY8047QDC` (`C3018651`) with its datasheet reference circuit
and a 1 uH `FTC201610S1R0MBCA` (`C5832342`). At the conservative 1.5x FPGA
transient target, calculated peak inductor current is 2.80 A and the project's
required saturation rating is 3.64 A; the fitted inductor is rated 4.60 A.
The power audit passes. AMD XPE remains useful before fabrication, but it is
no longer needed to justify an undersized regulator.

## 27. FIXED — press-fit SFP cages replaced with solder-tail cages

**Entities:** SH1/SH2, J60/J61, `tools/placement.py`.

TE 2007198-1 was a press-fit part unsuitable for the requested JLC solder
assembly. SH1/SH2 now use **Amphenol U77A11133001 / C5355132**, which JLC lists
as Extended with wave soldering for Economic and Standard PCBA. The
standalone cage's host-board pattern matches the TE connector datum, so
**1888247-1 is retained** and no integrated connector/cage replacement is
needed. A new drawing-based `odin` footprint replaces the old cage import.

The connector depth is **35.40 mm from PCB edge** (34.50 to cage datum F,
then 0.90 to the locating-peg centreline), or 42.40 mm from the cage mouth.
The mouth overhang is 7.00 mm. Placement now uses an explicit edge-datum
origin and correct relative cage/connector rotations. TE's two connector
locating holes are also corrected from the import's 1.70 mm plated holes
to the specified 1.55 mm NPTH.

Amphenol lists this cage at **2.5 Gb/s**; the old TE cage's 16 Gb/s rating
is not retained. Higher-rate operation remains unqualified. See
[the source drawings, comparison and assembly notes](ref/sfp-cage.md).

## 28. FIXED — DONE LED loaded the open-drain configuration signal

**Entities:** CFG_DONE, R7, D1, new R98 and Q4, SUP_DONE.

D1 previously drew current directly from DONE through 330 ohms. Its brightness
and the DONE high level therefore depended on the weak pull-up or an actively
driven DONE output. The circuit no longer uses DONE as an LED supply.

R98 adds 4.7k from CFG_DONE to +3V3 (bank 0 VCCO). Q4, BSS138LT1G / C82045,
has gate on CFG_DONE, source on GND and drain on D1's cathode. The LED current
path is +3V3 → R7 (330 ohms) → D1 → Q4 → GND. With the specified green LED's
2.0–2.6 V forward drop, expected current is approximately 2–4 mA. DONE sees
the MOSFET gate and the existing supervisor input path, not that LED current.
The added pull-up draws about 0.70 mA when DONE is held low.

No `DriveDone=Yes` requirement is imposed on reference bitstreams. The LED
illuminates when DONE is released high and extinguishes when DONE is low;
SUP_DONE retains its existing connection. This follows the default open-drain
behavior described in [AMD UG470](https://docs.amd.com/v/u/en-US/ug470_7Series_Config).
Q4's low-voltage switching rating is checked against the
[onsemi BSS138LT1/D datasheet](https://www.onsemi.com/pdf/datasheet/bss138lt1-d.pdf).
The LED reports the DONE level, not application health, and is not a reliable
indicator during supply ramp-up.

## 29. FIXED — PUDC_B low strap was too weak

R6 is now **1k** (0402, C11702), from PUDC_B to GND, replacing 4.7k.
This follows the ≤1k strap recommendation in
[AMD UG470, Configuration Pins](https://docs.amd.com/v/u/en-US/ug470_7Series_Config)
and retains the intended internal I/O pull-ups during configuration.
Generator, schematic, netlist and PCB are synchronized; R6's connections
and physical placement are unchanged.

## 30. FIXED — two SFP EEPROMs collided on the shared I2C bus

**Entities:** J60/J61, U27, C231, R99–R103, SFP_SCL/SFP_SDA.

Both modules formerly connected their fixed-address 0x50 EEPROMs directly
to the same bus. Added **PCA9543APW,118 / C2652904** at 0x70, with one
channel per cage and separate downstream pull-ups. Both modules can remain
powered while firmware enumerates them separately. This chooses the mux
option; Q1 and U17 P7 retain shared power control. Documentation now states
that power removal affects both ports.

Select 0x01 or 0x02, finish selection with STOP, then read 0x50; never
select 0x03. Deselect with 0x00 before shared power-off. RESET is tied to
SUP_RUN, providing a hardware recovery path if a module holds I2C low;
a software controller reset alone may leave the mux selected. These rules,
startup handling and stuck-bus limits are in [sfp-i2c.md](ref/sfp-i2c.md),
with the NXP datasheet and procurement links. Firmware remains to be written.

## 31. FIXED — PSRAM series termination was documented but absent

Added **R104–R127**, 24 populated 33 ohm 0402 resistors (C25105), one on
each port's SCK, CE_B and IO0–IO3. FPGA-side nets and ball allocation remain
unchanged. Each resistor connects its original FPGA net to a distinct `_MEM`
net at the PSRAM; connectivity checks verify there is no direct bypass.

The generator, schematic, netlist and PCB are synchronized. `tools/place.py`
places the resistor bank at U1's right-hand escape edge instead of beside
the memory chips. Exact positions still require escape routing. 33 ohms is
a bring-up value; FPGA-end damping does not establish source termination
for PSRAM-driven reads or guarantee 100 MHz timing. The tuning and placement
requirements are in [ref/psram.md](ref/psram.md).

## 32. FIXED — +12V_EXT lacked local output capacitance

Added **C232, 10uF 25V**, 0805 X5R, Samsung CL21A106KAYNNNE / C15850,
from U25 OUT (+12V_EXT) to GND, before the selectors and branch PTCs.
The generator now explicitly rates capacitors on +12V_EXT at 25V.
Existing designators and connections are preserved. C232 belongs to U25's
placement group and must sit close to its OUT pin and ground return.

At the existing approximately 20ms output ramp, the nominal added charging
current is about 6mA; extension capacitance remains additional. The capacitor
provides local output charge storage, not a substitute for extension-side
decoupling. The selected part's voltage and package are confirmed by
[LCSC C15850](https://www.lcsc.com/product-detail/C15850.html).

## 33. FIXED — no supervisor/user indicators and unused core power-good

U17 P0/P1/P2 now sink three green LEDs (D9/D10/D11), labeled CTRL HB,
USER 1 and USER 2, with individual 1k resistors R128–R130 from +3V3.
They default off, need no extra supervisor GPIOs, and use the same qualified
LED as DONE. P3 now reads CORE_1V0_GOOD with its existing 100k pull-up.
P7 retains shared SFP power control; P4–P6 remain unused.

The [firmware contract](ref/status-leds.md) requires a shadow output byte,
P3–P6 always written high, and masked updates so heartbeat/user LEDs cannot
change SFP power or drive PG low. PG polling and LED control share the SFP
upstream bus, so a stuck bus also stops heartbeat updates. This implements
the hardware; supervisor firmware and physical placement/routing remain.

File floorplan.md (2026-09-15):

# Odin floorplan and placement contract

**Generated intent doc for `tools/placement.py` / `tools/place.py`. The code
is authoritative; this page says why.**

## Zones

```text
        SFP0  SFP1        J50   USB-C          top:    cages nose out,
  E  +--------------------------------+  A            input corner right
  F  |  cages intrude to y=41.98       |  B     left:   slots E-H (bank 34,
     |        [ XC7A100T ]            |               package columns 1-8)
  G  |        centre (50,62)          |  C     right:  slots A-D (bank 15,
  H  |  supervisor row      5V buses  |  D            columns 14-26)
     +--------------------------------+        bottom: service row, U7,
       JTAG SWD BOOT   J7/L    J8/M                   5V buses L and M
```

## The lattice (the actual contract)

Signal rows, power row and key post of every extension edge sit on ONE
2.54 mm grid, because a shield PCB bridges all three:

- signal 2x16 centreline 4.70 mm from its edge, rows at 3.43 / 5.97
- power 1x16 centreline 13.59 mm (inner signal row + 3 pitches)
- key post 18.67 mm (inner signal row + 5 pitches)
- body centres at 26.50 and 73.50 along each edge; zone centres +/-10.16
  within each body

`tools/place.py --check` verifies from real pad coordinates that the left
and right sockets expose identical y-lattices (bottom pair: x-lattices) and
that the three rows stay on the grid. It refuses to write a board that
breaks this. It also prints the column-facing convention; copy that line
into `ref/extension-ux.md` once and it is a fact, closing findings item 14
for the electrical part. Stack height remains a mechanical purchase choice.

## SFP mechanical datums

SH1/SH2 use the solder-tail Amphenol U77A11133001 with TE 1888247-1
connectors. The cage footprint origin is the PCB-edge datum at y=0;
its mouth is at y=-7.00 and shell rear at y=41.98. J60/J61 locating-peg
centrelines are at **y=35.40**, derived from cage datum F at 34.50 plus
TE's 0.90 connector offset. Cage rotation is 270°, connector rotation 180°.
See [the drawing comparison](ref/sfp-cage.md).

The shell extends above the SVG's original view; the renderer includes the
full mouth overhang. Anchor positions remain starting values for eye-tuning.
The cage's front region excludes top-side components and signal traces;
several existing group anchors under the cages still need relocation before
applying the full floorplan. This change updates the four SFP placements only.

## Reasoning already burned in

- Bank 34 balls (E-H) are on package columns 1-8, banks 15/13/14 on 14-26,
  so E-H own the left edge and A-D the right; the 5V buses (banks 14/13) and
  the supervisor sideband exit the bottom. No slot escape crosses the die.
- GTP balls are on rows A-F (top of the die); the cages face them across a
  approximately 6.2 mm channel. Refclk oscillator sits at the channel's right end.
- The BGA sits below centre because the cages intrude 41.98 mm from the top.
- USB-C and J50 keep the top-right corner: VBUS parts, PD sink and the
  regulator row anchor there, one entry point for all power.

## PSRAM termination placement

`tools/place.py` places R104–R127 in a column just outside the FPGA's right
edge (15.4 mm from U1 centre, 1 mm pitch), ordered by their associated ball
row/column. Their pad 1 faces the FPGA. This rule keeps them out of the
PSRAM-chip group packing; refine their positions as escape routing develops.
See [the PSRAM layout note](ref/psram.md) for net names and tuning limits.

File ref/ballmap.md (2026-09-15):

# XC7A100T-FGG676 ball map

Generated by `tools/ballmap.py` from `tools/alloc.py`, which is the one
place ball allocation is decided. The schematic is generated from the same
function, so this file and the circuit cannot disagree. Package facts come
from the imported `XC7A100T-2FGG676I` symbol, LCSC `C1521803`.

```
python3 tools/ballmap.py > ref/ballmap.md
```

## I/O-bank architecture

This package has **six HR I/O banks** — 13, 14, 15, 16, 34 and 35 — 300 user I/O total.
`VCCO` is shared by every pin in a bank. Odin uses bank 14 at fixed 3.3V,
bank 13 for 5V BUS 1, banks 15 and 34 as selectable extension domains, and reserves
banks 16 and 35 for later base-board peripherals.

| Bank | HR I/O | Diff pairs | MRCC | SRCC |
|---|---|---|---|---|
| 13 | 50 | 24 | 4 | 4 |
| 14 | 50 | 24 | 4 | 4 |
| 15 | 50 | 24 | 4 | 4 |
| 16 | 50 | 24 | 4 | 4 |
| 34 | 50 | 24 | 4 | 4 |
| 35 | 50 | 24 | 4 | 4 |

**Bank 14 is not free.** It carries the master-SPI config flash pins and the
`PUDC_B` strap, so its `VCCO` is pinned at 3.3V by the flash. That makes it
the home for everything else fixed at 3.3V — PSRAM, the supervisor sideband,
and 5V BUS 0. Bank 13 carries 5V BUS 1. Banks 15 and 34 are the two settable extension
domains, four slots each. The other two HR banks are powered at 3.3V but
carry no signals in this revision.

## Allocation

| Bank | VCCO | Contents |
|---|---|---|
| 14 | **fixed 3.3V** | config flash, PSRAM x4, supervisor sideband, 5V BUS 0 |
| 13 | fixed 3.3V | 5V BUS 1 |
| 15 | **settable** 3.3 / 2.5 / 1.8 | slots A B C D |
| 34 | **settable** 3.3 / 2.5 / 1.8 | slots E F G H |
| 16, 35 | fixed 3.3V | reserved for future base-board peripherals |

## Config flash and strap

| Ball | Net | Package name |
|---|---|---|
| R14 | `FLASH_D0_MOSI` | IO_L1P_T0_D00_MOSI_14 |
| R15 | `FLASH_D1_MISO` | IO_L1N_T0_D01_DIN_14 |
| P14 | `FLASH_D2_WP` | IO_L2P_T0_D02_14 |
| N14 | `FLASH_D3_HOLD` | IO_L2N_T0_D03_14 |
| P18 | `FLASH_CS_B` | IO_L6P_T0_FCS_B_14 |
| P15 | `PUDC_B` | IO_L3P_T0_DQS_PUDC_B_14 |

`CCLK`, `PROGRAM_B`, `INIT_B`, `DONE`, `M[2:0]` and JTAG are bank 0
dedicated pins — see the bank 0 table below.

## PSRAM — four independent QSPI buses

| Chip | SCK | CE# | IO0 | IO1 | IO2 | IO3 |
|---|---|---|---|---|---|---|
| PSRAM0 | N16 | N17 | R16 | R17 | K25 | K26 |
| PSRAM1 | M20 | L20 | L24 | L25 | M24 | M25 |
| PSRAM2 | L22 | L23 | M21 | M22 | N21 | N22 |
| PSRAM3 | P20 | P21 | N23 | N24 | P19 | N19 |

Each chip's six lines come from three adjacent differential pairs, so the
group stays physically tight and length matching stays local.

## Supervisor sideband

| Ball | Net |
|---|---|
| P23 | `DBG_TCK` |
| P24 | `DBG_TMS` |
| R20 | `DBG_TDI` |
| R21 | `DBG_TDO` |
| R25 | `SB_UART_RX` |
| P25 | `SB_UART_TX` |

## Extension slots

Direct slots A-H expose twelve ordinary numbered I/O as six adjacent
differential-capable pairs. Pairing remains
an optional capability rather than part of the basic connector UX.
5V BUS 0 and 5V BUS 1 each expose one complete translated 8-bit bus.

| Slot | Bank | FPGA balls in connector order |
|---|---|---|
| **L** | 14 | N26, M26, T24, T25, R26, P26, T22, R22 |
| **M** | 13 | U25, U26, V26, W26, AB26, AC26, W25, Y26 |
| **A** | 15 | K15, J16, J14, J15, K16, K17, M14, L14, M15, L15, M16, M17 |
| **B** | 15 | J19, H19, L17, L18, K20, J20, J18, H18, G20, G21, K21, J21 |
| **C** | 15 | H21, H22, J23, H23, G22, F22, J24, H24, F23, E23, K22, K23 |
| **D** | 15 | G24, F24, E25, D25, E26, D26, H26, G26, G25, F25, J25, J26 |
| **E** | 34 | K3, J3, M7, L7, M4, L4, L5, K5, N7, N6, M6, M5 |
| **F** | 34 | K1, J1, L3, K2, N1, M1, H2, H1, M2, L2, N3, N2 |
| **G** | 34 | R3, P3, P4, N4, R1, P1, T4, T3, T2, R2, U2, U1 |
| **H** | 34 | P6, P5, T5, R5, U6, U5, R8, P8, R7, R6, T8, T7 |

The two 5V buses are buffered; A-H are direct. M19, U24 are their direction controls. Together the buses cost **20** FPGA I/O for 16 connector signals.

| Bus control | FPGA ball | Bank | Default |
|---|---|---|---|
| `BUS5V0_OE_N` | P16 | 14 | 10k to +3V3; high disables the bus |
| `BUS5V1_OE_N` | Y25 | 13 | 10k to +3V3; high disables the bus |

Hold OE_N high while setting DIR and data; drive OE_N low only when ready.
Raise OE_N again before changing direction.

## Bank 0 — dedicated configuration pins

| Ball | Name |
|---|---|
| AB15 | `CFGBVS_0` |
| AB7 | `M0_0` |
| AE16 | `PROGRAM_B_0` |
| G14 | `VCCBATT_0` |
| H10 | `TDI_0` |
| H11 | `TMS_0` |
| H12 | `TCK_0` |
| H13 | `CCLK_0` |
| J10 | `TDO_0` |
| M11 | `GNDADC_0` |
| M12 | `VCCADC_0` |
| N11 | `VREFN_0` |
| N12 | `VP_0` |
| P11 | `VN_0` |
| P12 | `VREFP_0` |
| R11 | `DXN_0` |
| R12 | `DXP_0` |
| V11 | `INIT_B_0` |
| W10 | `DONE_0` |
| W11 | `VCCO_0` |
| W9 | `M2_0` |
| Y14 | `VCCO_0` |
| Y9 | `M1_0` |

## Bank 216 — two connected GTP transceivers

Lanes 0 and 1 go to the two SFP ports. Lanes 2 and 3 have RX grounded
and TX floating; unused reference-clock inputs float (UG482 Table 5-6).
See `ref/highspeed.md`.

| Ball | Name |
|---|---|
| A11 | `MGTPRXN0_216` |
| A13 | `MGTPRXN2_216` |
| A15 | `MGTRREF_216` |
| A7 | `MGTPTXN0_216` |
| A9 | `MGTPTXN2_216` |
| B11 | `MGTPRXP0_216` |
| B13 | `MGTPRXP2_216` |
| B7 | `MGTPTXP0_216` |
| B9 | `MGTPTXP2_216` |
| C10 | `MGTPTXN3_216` |
| C12 | `MGTPRXN3_216` |
| C14 | `MGTPRXN1_216` |
| C8 | `MGTPTXN1_216` |
| D10 | `MGTPTXP3_216` |
| D12 | `MGTPRXP3_216` |
| D14 | `MGTPRXP1_216` |
| D8 | `MGTPTXP1_216` |
| E11 | `MGTREFCLK0N_216` |
| E13 | `MGTREFCLK1N_216` |
| F11 | `MGTREFCLK0P_216` |
| F13 | `MGTREFCLK1P_216` |

## Bank 213 — unused GTP transceivers

The G10 supplies remain powered. All eight RX pins connect to GND;
MGTRREF_213 connects through its own 100 ohm, 1% resistor to +1V2_MGT.
TX and reference-clock pins float, per UG482 Table 5-5.

## Budget

- slots: **96**
- PSRAM: **24**
- supervisor sideband: **6**
- config flash + strap: **6**
- 5V bus data: **16**
- 5V bus direction: **2**
- 5V bus enable: **2**
- **assigned HR I/O: 152 of 300**
- **free: 148** for base-board peripherals

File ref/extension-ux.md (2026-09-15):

# Odin extension connector — the whole spec

If you are building an extension, this page is all you need.

## The module

One **module** = one 16-position signal connector (2×8, 0.1") plus its
separate 8-pin power row on **each of two opposite edges**. An extension is a
shield that bridges the 100 x 100 mm base board:

```text
16:       [ A ]================[ E ]
32:   [ A ][ B ]============[ E ][ F ]
64: [ A ][ B ][ C ][ D ]==[ E ][ F ][ G ][ H ]
```

The name is the connector width on each side:

- a **16** bridges one signal block on each edge: **24 I/O**;
- a **32** bridges two signal blocks on each edge: **48 I/O**;
- a **64** bridges four signal blocks on each edge: **96 I/O**.

The schematic divides each edge into four 16-pin electrical sections: A-D on
one edge and E-H on the other. That does **not** require four separate plastic
headers. The generated schematic and board use the original arrangement of **two
continuous 32-pin stack-through signal headers on each edge**, with a parallel
continuous 32-pin single-row power header. The 16-position boundaries are
labels that let a small shield occupy part of those headers.

That gives the extension support at both ends and most of the board area above
Odin. Each shield carries female sockets underneath and matching male pins on
top, so another shield can stack over it.

Matching pairs are A/E, B/F, C/G and D/H. Placement must put every pair
directly opposite, at identical pitch and orientation. This mechanical fit is
not proven until the base board, a reference shield and the stacking height
are laid out together.

```text
             1     2     3     4     5     6     7     8
signal row 1 IO0   IO2   IO4   IO6   IO8   IO10  GND   GND
signal row 2 IO1   IO3   IO5   IO7   IO9   IO11  GND   GND
power row    GND   PIN V GND   3V3   GND   5V    GND   SLOT PWR
```

The two signal rows contain 12 ordinary numbered I/O and four grounds. The
third row contains all power and four more grounds. Power is never hidden
between signal pins.

**The guide is a separate post,** not the header itself: a 1x1 pin beside each
slot with a matching hole in the extension. A bare 2x8 header cannot stop reversed
insertion on its own, and pretending otherwise would be the expensive kind of
wrong. This is the same trick Odin_0 used.

Treat the pins as ordinary `IO0..IO11`. The FPGA allocation preserves six
adjacent differential-capable pairs per slot. Pairing is an optional electrical
capability, not the connector's identity. The exact pair map is in
`ref/ballmap.md` for extensions that genuinely need it.

## The four rails, and why you are never blocked

| Pin | Rail | Fixed or set | What it is for |
|---|---|---|---|
| Power 2 | **PIN V** | **set per group: 3.3 / 2.5 / 1.8V** | Powers your voltage-matching logic and sets the FPGA pin voltage. |
| Power 6 | **+5V** | fixed | Crappy 5V parts, LCD backlights, servos. |
| Power 4 | **+3V3** | fixed | Always there even when PIN V is 1.8V. Power your sensor here. |
| Power 8 | **SLOT PWR** | set beside this slot: **+12V / +5V / +3V3** | Motors, relays, op-amps or backlights. |

**+3V3 is fixed on purpose.** If PIN VOLTAGE is set to 1.8V you still have a
normal 3.3V supply for the part you are powering. Signalling level and supply
rail are separate problems and this is the pin that keeps them separate.

## PIN VOLTAGE changes the pins — this is the important bit

An FPGA pin has no fixed voltage. Pins live in **banks**, and a bank's `VCCO`
supply *is* the logic level of every pin in it. Odin calls the connector pin
`PIN V`; the schematic's technical net name is `VCCIO`. One jumper changes
both the FPGA pins and the power delivered on `PIN V`.

So: jumper the module to 2.5V and you get a 2.5V rail on B7… and IO0–IO9
become 2.5V pins, LVDS-capable. Jumper it to 3.3V and they are 3.3V pins.
**The rail on the connector and the logic level of the pins can never
disagree.** You do not have to know this to use the board. That is the point.

## The slots, and the two voltage domains

Ten extension ports: eight direct sections and two complete 5V buses. The
`XC7A100T-FGG676` has six HR I/O banks. This board deliberately
uses two as the extension voltage domains: bank 15 for A-D and bank 34 for E-H.
Bank 14 stays fixed at 3.3V for flash, memory, control signals and 5V BUS 0.
5V BUS 1 uses fixed-3.3 V bank 13. Banks 16 and 35 remain reserved. Therefore this
revision has **two settable extension domains**:

| Slots | FPGA group | PIN VOLTAGE | Path |
|---|---|---|---|
| **5V BUS 0** | 14 | fixed 3.3V | **buffered**, 5V compatible |
| **5V BUS 1** | 13 | fixed 3.3V | **buffered**, 5V compatible |
| **A B C D** | 15 | **settable** 3.3 / 2.5 / 1.8V | direct |
| **E F G H** | 34 | **settable** 3.3 / 2.5 / 1.8V | direct |

| You plug in a | You get | PIN VOLTAGE |
|---|---|---|
| **16** (1 module) | 12 IO per edge, 24 total | shares each domain with 3 neighbours |
| **32** (2 modules) | 24 IO per edge, 48 total | shares each domain with 2 neighbours |
| **64** (4 modules) | 48 IO per edge, 96 total | **owns both domains outright** |

**Only a 64 gets a private voltage.** If your extension needs 2.5V or 1.8V
signalling, build it as a 64 and take a whole bank, or agree the voltage with
whatever else is sharing your domain. Two extensions at different voltages
means one in the A–D domain and one in E–H.

## The two 5V buses

5V BUS 0 and 5V BUS 1 are identical complete eight-bit buses. Each uses one
`SN74LXC8T245`, accepts 3.3 V on the FPGA side and 5 V on the connector side,
and has one direction control for all eight signals. Each also has a separate
FPGA-controlled `OE_N`, pulled up to +3V3 by 10k so the bus is disabled during
configuration. Set direction and data with OE_N high, then drive OE_N low to
enable; disable again before changing direction.

They are not eight unrelated bidirectional GPIOs: all eight bits on one bus
turn around together. Use them for parallel displays, legacy byte-wide parts
and other 5 V buses. Use A-H when pins need independent direction.

| | 5V BUS 0/1 | Slots A–H |
|---|---|---|
| 5V tolerant | **yes** | no (3.3V max) |
| Speed | moderate | full FPGA speed |
| LVDS | no | **yes, 5 pairs** |
| Direction | shared per complete 8-bit bus | per pin, it is a raw FPGA ball |
| VCCIO | fixed 3.3V | settable per domain |

**Junk 5V parts?** Use either 5V BUS. BUS 0 shares fixed bank 14; BUS 1 uses
fixed bank 13. Neither consumes a selectable extension voltage domain.
**Anything fast, or needing per-pin direction?** Any of A–H.

## Differential-capable pins

The connector is an ordinary numbered-I/O interface. Underneath that simple
view, six selected adjacent pin pairs per slot are routed to FPGA pair-capable
balls. Use the pairing only when it helps; consult the ball map instead of
assuming every column is a pair. A 0.1" header is not a precision
high-speed connector, so keep aggressive links short and set PIN V to 2.5V
for true LVDS output from an Artix-7 HR bank.

## How much current you actually get

**The per-slot fuses are fault protection, not an allowance.** Nine slots x
500 mA does not mean the board can source 4.5 A. Each rail has one source, and
all ten extension ports share it:

| Rail | Source | **Shared total, all slots** | Per-slot fuse |
|---|---|---|---|
| VCCIO | protected separately for A-D and E-H | **500 mA typical per domain**, subject to source headroom | 500 mA |
| +5V | `TPS54202`, or USB directly, then protected switch | **1.0 A typical** | 500 mA |
| +3V3 | `AP63300`, then protected switch | **limited to 500 mA typical at the connector bus** | 300 mA |
| **AUX 12V** | `TPS61085`, then latch-off eFuse | **500 mA typical** | 200 mA |

Those numbers are computed, not estimated round figures: every one of them
comes out of [`ref/power-budget.md`](power-budget.md), which
`tools/budget.py` generates from a worst-case load table and the regulators'
datasheet limits. Three things about them are worth knowing before you design
against them.

**+3V3 is the tight one, not AUX.** It carries the supervisor, the PSRAMs, the
config flash, FPGA bank 14, the oscillator, both SFP modules, and both VCCIO
domains if you jumper them to 3.3 V. That leaves 500 mA for all extension ports. Two
SFP modules alone are 610 mA of it — power them down and you get that back.

**AUX and +5V share a pot.** The 12 V rail is boosted *from* +5 V, and at 12 V
out each milliamp of AUX costs 2.8 mA of +5 V. The boost itself could manage
620 mA; the +5 V rail can only feed 570 mA of it, and every milliamp a slot
takes from its +5 V pin comes off that. One backlight is fine. Nine motors are
not.

## What a bad extension can do

Connector power does not come directly from Odin's internal rails. Five
shared protection channels sit before the existing slot fuses: +5V, +3V3,
VCCIO for A-D, VCCIO for E-H, and AUX 12V. They start off, limit startup and
short-circuit current, block power flowing backward into Odin, and report one
shared `EXT_FAULT` signal. A fault can turn off every slot using that shared
bus. It does not turn off the FPGA, memories, supervisor or internal rails.

This protects Odin's **power pins**. It does not make A-H signal pins tolerate
5 V. Only 5V BUS 0 and 5V BUS 1 have translated 5 V-compatible signals.

**On a plain 5 V source the +5V ceiling is the USB port, not the regulator.**
1.6 A assumes `U11` is running, which needs 9 V. Plugged into a weak laptop
port you have 0.9 A total for the whole board. If your extension needs real
current, feed it from `J50` and do not take it from the connector.

**AUX is marked provisional deliberately.** 570 mA is arithmetic on datasheet
limits at 90% assumed efficiency; it ignores thermals and board droop. Treat
it as a design target until a board has been measured.

And remember the whole board is limited by what the USB source gives you —
see `ref/power-input.md`.

## Rules

- **The 1.0V FPGA core never reaches a connector.** Do not look for it.
- Every rail is individually fused. Shorting your extension does not take the
  board down.
- **Not implemented yet:** board-ID pins. All 16 positions are spoken for, so
  there is nowhere to put them without giving up an I/O. See `findings.md`
  item 8. The supervisor still fuses and power-gates every rail; it just
  cannot yet tell *what* you plugged in.
- IO are numbered globally `IO_1..IO_112`: eight on each 5V bus, then twelve
  on each direct slot A-H, so every port's identity is readable from the net name.
- Exact FPGA ball for every pin: `ref/ballmap.md`.
- Where every current figure above comes from: `ref/power-budget.md`.

## Confirmed against the package file

Bank count, pair count and every ball assignment come from the imported
`XC7A100T-2FGG676I` symbol and are processed by `tools/ballmap.py`. Six HR
banks provide 300 user I/O. The generated `ref/ballmap.md` is authoritative.

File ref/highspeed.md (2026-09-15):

# The two fast ports

The `XC7A100T-FGG676` has two four-lane GTP quads. This revision wires two
lanes in quad 216. The FPGA supports up to ~6.6 Gb/s per lane, but the
selected Amphenol cage is listed at 2.5 Gb/s; higher-rate operation is
unqualified. Unused RX lanes are grounded and unused TX lanes float. Ordinary pins
are roughly a hundred times slower. These are the only thing on Odin an
extension board can never add later, because a signal that fast dies in a
0.1" pin header — it needs a real connector and controlled-impedance copper on
the base board.

## Don't spend them on video

Tempting, but wrong. The Artix-7 drives HDMI at 1080p60 from **ordinary I/O**
using TMDS — no fast lane required. Video belongs on an extension board or on
spare base-board I/O. Spend the fast lanes on what ordinary pins genuinely
cannot do: multi-gigabit serial.

## Built: SFP cages

An SFP cage is a socket you plug a **module** into — which is the same idea as
Odin's extension slots, one level up. One socket, many personalities:

| Module | What you get | Rough cost |
|---|---|---|
| Copper 1000BASE-T | An RJ45 ethernet port | ~$15 |
| Fibre (many kinds) | 550 m to 80 km, pick the module | $8–40 |
| Direct-attach copper | A fixed cable, board to board or to a switch | ~$10 |
| Loopback plug | Test your link with no other hardware | ~$5 |

You wanted two ethernet ports. This gives you two ethernet ports **and** fibre
**and** board-to-board, and the base board never has to choose which.

**There are two ports, full stop.** Lanes 0 and 1 reach them. Lanes 2 and 3 do
not create empty connectors, fake choices or assembly noise.

## What makes it UX-smart

Every SFP module carries an identification chip you read over a two-wire bus.
U27 selects one module’s two-wire bus at a time, so firmware can identify
both modules despite their shared EEPROM address, 0x50. This enables the
planned self-describing interface —
exactly like the board-ID pins on the extension slots:

- **Planned identity reporting.** Supervisor firmware can report: `SFP0: FS
  1000BASE-T copper, s/n …` / `SFP1: empty`. No guessing, no label squinting.
- **It knows when something is inserted or removed.** Each cage has presence,
  transmit-fault and rate-select pins. All go to the supervisor.
- **The supervisor controls power to both ports together.** A module fault
  requiring power removal shuts down both links. U27 isolates management
  traffic; it does not provide independent power shutdown.
- **Three board status LEDs** on U17: supervisor heartbeat and two user
  indicators, with [software control](status-leds.md). They are not dedicated
  per-cage FPGA LEDs.

Management uses the shared upstream I²C bus plus per-port control/status
pins. See [the selection and recovery contract](sfp-i2c.md).

## The honest limits

- **The selected cage is listed at 2.5 Gb/s.** The FPGA lane ceiling is
  ~6.6 Gb/s, but it does not qualify the complete port at that speed. Match
  the module line rate and FPGA design; higher-rate operation needs separate
  qualification. See [cage qualification](sfp-cage.md).
- **The socket is not the hard part.** You still need a gigabit ethernet core
  in the fabric. Open ones exist, and Xilinx ships one, but standing up a
  working link is a project measured in weeks, not an afternoon. The board's
  job is to make sure that project is *possible* — which it is not at all if
  these lanes go nowhere.
- **Board area.** A cage is roughly 14 mm wide and 47 mm deep. The two ports
  take about 28 mm of one edge.

## What is actually in the schematic

| Ref | Part | Note |
|---|---|---|
| `J60`, `J61` | TE 1888247-1 electrical connector | lanes 0 and 1 |
| `SH1`, `SH2` | Amphenol U77A11133001 solder-tail cage | C5355132, JLC wave solder |
| `X2` | 125 MHz differential oscillator | the reference clock the lanes need |
| `Q1` | P-channel high-side switch | gate pulled high, so cages are **off until the supervisor turns them on** |
| `U17` | SFP power controller | shared default-off power control, address 0x24 |
| `U27` | PCA9543APW,118 I²C switch | address 0x70; separate EEPROM channels |
| `R35` | `MGTRREF` precision resistor | 100R 1%, 0603, to `+1V2_MGT` (MGTAVTT); findings item 6 fixed |

Coupling capacitors sit in series on all eight high-speed lines. Status lines run to the supervisor. Each two-wire identification bus has
its own pull-ups and reaches the supervisor through a separate U27 channel.
Both G10 (quad 213) and G11 (quad 216) remain powered. `R89` provides quad
213 with its own 100R 1% 0603 resistor from `MGTRREF_213` to `+1V2_MGT`.
All eight RX pins in quad 213 and the four RX pins of unused lanes 2/3 in
quad 216 connect to GND. Unused TX and reference-clock pins float, per
[UG482 Tables 5-5 and 5-6](https://0x04.net/~mwk/xidocs/ug/ug482_7Series_GTP_Transceivers.pdf#page=223).

The oscillator is selected and pin-checked. `MGTRREF` uses 100 ohm, 1% to
MGTAVTT per [UG482 v1.9, Figure 5-1](https://0x04.net/~mwk/xidocs/ug/ug482_7Series_GTP_Transceivers.pdf#page=218).

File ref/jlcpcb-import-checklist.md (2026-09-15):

# JLCPCB / EasyEDA import checklist

The imported library is in `easyeda/` beside `kicad/`. The checked parts below
are now linked from the textual design by exact footprint and LCSC number.
`python3 tools/audit_easyeda.py` verifies those links, symbol pin numbers and
footprint pad numbers every time the design changes.

An imported symbol and footprint are evidence, not proof. Before use, Odin
must compare pin numbers, exposed pads, package dimensions and orientation
against the manufacturer datasheet.

## Imported parts

| Qty | Manufacturer part number | Used for | Known LCSC number |
|---:|---|---|---|
| 1 | `XC7A100T-2FGG676I` | programmable logic | `C1521803` — imported |
| 4 | `APS1604M-3SQR-SN` | work memory | `C18214056` |
| 1 | `W25Q256JVEIQ` | FPGA startup memory | `C97522` |
| 1 | `RP2350B` | board controller | C42415655 |
| 1 | `ABM8-272-T3` | controller 12 MHz crystal | C20625731 |
| 1 | `W25Q32JVZPIQ` | controller memory | `C571260` — imported and linked |
| 1 | `HC-TYPE-C-16P-01A` | USB-C connector | C2894897 |
| 1 | `ESDA6V1BC6` | USB data/CC protection | C495220 |
| 1 | `SMBJ13A` from a named manufacturer | USB power surge protection | C133675 |
| 1 | `CH224K` | USB power request | C970725 |
| 1 | `B3U-1000P` | controller boot button | C231329 |
| 1 | `SN74CB3Q3384APWR` | JTAG owner switch | C469874 |
| 2 | `SN74LXC8T245PWR` | Two complete 8-bit 5 V buses | C4363995 |
| 2 | `DMG2305UX` | switched power | C5261054 |
| 2 | `BSS138LT1G` (onsemi) | Q3 power-switch drive; Q4 DONE LED buffer | C82045 |
| 1 | `TPS259470ARPWR` | USB input protection | C3662799 |
| 3 | `SS34` from a named manufacturer | power diodes | C8678 |
| 1 | `TPS54202DDCR` | 5 V supply | `C191884` |
| 1 | `AP63300WU-7` | always-on 3.3 V supply | C2158012 |
| 3 | `TLV62569DRLR` | 2.5/1.8/1.2 V supplies | `C163217` |
| 1 | `SY8047QDC` | 4 A FPGA 1.0 V supply | `C3018651` — imported and linked |
| 1 | `TPS61085PWR` | 12 V slot-power supply | C13505 |
| 4 | `TPS22950CDDCR` | low-voltage slot-power protection | C7587833 |
| 1 | `TPS259470LRPWR` | 12 V slot-power protection | C3662793 |
| 1 | `AOTA-B201610S3R3-101-T` | controller 1.1 V inductor | C42411119 |
| 1 | `VLS252010HBX-1R0M-1` | FPGA transceiver filter | `C88211` — imported and linked |
| 3 | `SRN4018-2R2M` | 2.5/1.8/1.2 V supply inductors | `C913207` — imported and linked |
| 1 | `FTC201610S1R0MBCA` | FPGA 1.0 V supply inductor | `C5832342` — imported and linked |
| 10 | `SMD1206B020TF/24` | 12 V slot PTC, 200 mA | `C269111` — imported and linked |
| 20 | `SMD1206B050TF` | 5 V and pin-voltage PTC, 500 mA | `C269115` — imported and linked |
| 10 | `BSMD1206-030-16V` | 3.3 V slot PTC, 300 mA | `C22378340` — imported and linked |
| 1 | `DSC1123CI2-125.0000` | 125 MHz LVDS clock | `C617173` — imported, pin map confirmed and linked |
| 2 | `1888247-1` | SFP/SFP+ 20-contact connector | `C305914` — imported and linked |
| 2 | `U77A11133001` | SFP cage, 3.2 mm solder tails | `C5355132` — JLC Extended, wave solder; drawing-based `odin` footprint |
| 2 | `SRN6045TA-100M` | 5 V and 12 V supply inductors | C2046332 |
| 1 | `SRN6045TA-4R7M` | 3.3 V supply inductor | C2044594 |
| 1 | `2.54-2*5P` | keyed FPGA JTAG header | `C5665` — imported and linked |
| 1 | `BM03B-SRSS-TB(LF)(SN)` | keyed controller SWD header | `C160389` — imported and linked |
| 1 | `KF301-5.0-2P` | 9–14 V external power terminal | `C474881` — imported and linked |
| 4 | `F.0603.00025/P2-0603G1TS2-06T-002` | green DONE, heartbeat and two user LEDs | `C7496818` — imported and linked |
| 13 | `F254D-02-PT-B` | removable 2.54 mm selector shunts | `C501335` — imported; loose accessory |
| 1 | `PCA9543APW,118` | two-channel SFP I²C switch | `C2652904` — generated symbol, standard TSSOP-14 footprint; JLC Economic/Standard PCBA |
| 1 | `PCF8574T_3,518` | SFP control I/O expander | `C7605` — imported and linked |

Import the exact orderable suffix shown. A nearby family member in the same
search result is not interchangeable.

## Import audit result

The fitted design currently uses **129 instances** backed by the EasyEDA
library. Their connected schematic pin numbers exist in both the imported
symbol and imported footprint, and their LCSC identities agree.

The imported TPS259470 footprint was rejected: its pad geometry violates the
board's 0.20 mm copper clearance in 18 places. `U25` and `U26` keep KiCad's
official TI `RPU0010A` footprint; their exact LCSC numbers remain in the
schematic and BOM. An imported file is not automatically better than the
manufacturer-package footprint.

The slot fuses, SFP cages and complete extension connector system are selected,
linked and audited. Only ordinary passive BOM matching remains below.

## SFP cage assembly

SH1/SH2 use [Amphenol U77A11133001, C5355132](https://jlcpcb.com/partdetail/AmphenolICC-U77A11133001/C5355132).
JLC lists Extended, Wave Soldering, and Economic and Standard PCBA support
(checked 2026-09-15). Assemble the SMT TE 1888247-1 connector before the cage;
select the through-hole wave-solder operation in the assembly order. Stock and
assembly pricing must be refreshed when ordering.

The cage symbol and footprint are generated from Amphenol's drawing, **not an
EasyEDA import**. Twenty plated shield holes connect to GND. The retained
connector import has its two locating holes corrected to 1.55 mm NPTH per TE
1888247 sheet 3. Mechanical datums, assembly clearance and the manufacturer's
**2.5 Gb/s listing** are documented in [sfp-cage.md](sfp-cage.md). The old
16 Gb/s cage qualification does not transfer to this part.

## Extension hardware — imported and linked

| Item | Selected part |
|---|---|
| four 2x16 signal sockets | `C3975161` — imported and linked |
| four 1x16 power sockets | `C7499334` — imported and linked |
| two 5V-bus 2x8 signal sockets | `C3975153` — imported and linked |
| two 1x8 power sockets | `C27438` — imported and linked |
| ten guide/key posts | `C42431799` — imported and linked |
| twelve 2x3 selectors | `C65114` — imported and linked; `C501335` shunts are loose accessories |
| one 1x2 external-JTAG selector | `C492401` — imported and linked; uses a `C501335` shunt |

## PSRAM series resistors

R104–R127 are 24 populated 33 ohm 0402 resistors, **C25105**, one per
SCK/CE_B/IO0–IO3 signal across the four PSRAM ports. They use standard KiCad
resistor footprints. Keep them in the assembly BOM; these are tuning parts,
not optional unpopulated links.

## +12V_EXT output capacitor

C232 is **10uF 25V**, Samsung CL21A106KAYNNNE / **C15850**, X5R, 0805.
It connects U25 OUT (+12V_EXT) to GND before the selectors and PTC branches.
Place it beside U25; the 25V rating is explicit in the generated BOM value.

## Input protection additions

- D8: **SMBJ15A-13-F**, Diodes Incorporated, **C135046**, unidirectional
  TVS in standard KiCad `Diode_SMD:D_SMB`; cathode pad 1 to VIN_EXT.
- R49: **47k**, 0603, Q2 gate pulldown path; retain the 100k source pull-up.
  Use 1% resistors for the documented divider tolerance calculation.

## Ordinary resistors and capacitors

These do not need imported custom symbols or footprints. They do need exact
LCSC stock numbers in the BOM.

Prefer Basic or Promotional Extended parts, but only after matching:

- package: 0402, 0603 or 0805 exactly as designed;
- resistance/capacitance and tolerance;
- capacitor dielectric: X5R or X7R;
- voltage rating: 16 V minimum unless the schematic explicitly says 25 V;
- effective capacitance after DC-bias derating, especially 10 uF and 22 uF;
- power rating for resistors in dividers and current-setting networks.

The ordinary parts are **not release-ready yet**. The values and package sizes
exist, but LCSC numbers and capacitor DC-bias checks are still missing. Do not
bulk-assign the cheapest search result.

## What to send back after importing

For every imported part, retain:

1. manufacturer part number;
2. LCSC number;
3. EasyEDA symbol;
4. EasyEDA footprint;
5. datasheet link;
6. whether JLCPCB currently marks it Basic, Promotional Extended or Extended.

Then Odin can replace library references systematically and run symbol-pin,
footprint, ERC, power-budget and schematic-parity checks again.

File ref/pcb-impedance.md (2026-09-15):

# PCB routing rules and impedance

`python3 tools/gen_pcb.py --rules-only` regenerates the stackup, project net
classes and `kicad/odin.kicad_dru` while preserving placement and routing.
Without that flag the generator creates an empty board.

## Selected fabrication stackup

**JLC06161H-1080B**, 6 layers, nominal 1.6 mm, 1 oz outer / 0.5 oz inner,
ENIG: Sig / GND / Sig / PWR / GND / Sig.
Sources: [JLC stackup table](https://jlcpcb.com/impedance) and
[JLC impedance calculator](https://jlcpcb.com/pcb-impedance-calculator),
retrieved 2026-09-15. The calculator template ID is
`44d74b19da284af7ae31a739dbf6b16b`.

| Dielectric between copper layers | Thickness, mm | Material | Dk |
| --- | ---: | --- | ---: |
| F.Cu / In1.Cu | 0.0764 | NP-155F 1080 RC67% | 3.91 |
| In1.Cu / In2.Cu | 0.1000 | NP-155F core | 4.36 |
| In2.Cu / In3.Cu, first sublayer | 0.2104 | NP-155F 7628 RC49% | 4.40 |
| In2.Cu / In3.Cu, middle sublayer | 0.7000 | NP-155F core | 4.53 |
| In2.Cu / In3.Cu, last sublayer | 0.2104 | NP-155F 7628 RC49% | 4.40 |
| In3.Cu / In4.Cu | 0.1000 | NP-155F core | 4.36 |
| In4.Cu / B.Cu | 0.0764 | NP-155F 1080 RC67% | 3.91 |

The material-specific calculator table supplies the core Dk values above;
the general stackup page's generic core Dk is 4.6. The central spacer has
three explicit dielectric sublayers in KiCad. Nominal copper thicknesses are
0.035 mm outer and 0.0152 mm inner.

## 100 Ω differential calculation

Use coated edge-coupled microstrip on **F.Cu referenced to In1.Cu**, or
**B.Cu referenced to In4.Cu**. Keep those reference planes continuous.
The calculator model is `DiffEdgeCoupledCoatedMicrostrip1B`.
Its current copper and solder-mask parameter tables were used, including
the 0.5 oz base-copper row for finished 1 oz outer copper:

| Solver input | Value |
| --- | ---: |
| H1 | 0.0764 mm |
| Er1 | 3.91 |
| Finished trace thickness T1 | 1.6 mil (0.04064 mm) |
| Etch taper W1 − W2 | 0.5 mil (0.0127 mm) |
| Mask C1 / C2 / C3 | 1.0 / 0.6 / 1.0 mil |
| Mask CEr | 3.8 |
| Pair gap S1 | 0.200 mm |
| Target | 100 Ω |

Inverse calculation returns W1 = 3.8828125 mil = **0.0986234375 mm**,
W2 = 3.3828125 mil, with calculated impedance 100.0068 Ω. Set KiCad's
trace width to **0.099 mm**, gap **0.200 mm**. A forward calculation with
the rounded width returns **99.8515 Ω**. The width exceeds JLC's 3.5 mil
(0.0889 mm) minimum. The nominal stackup copper thickness and solver's
finished trace thickness are distinct manufacturer inputs.

These are solver predictions, not measured board impedance. Order controlled
100 Ω impedance with this stackup and have JLC confirm the production geometry.
The public page's generic mask table differs from the current calculator's
mask table; this calculation uses the latter. The table rows, exact solver
requests and responses are saved in
[jlc06161h-1080b-impedance.json](jlc06161h-1080b-impedance.json).

## Generated classes and DRC constraints

| Class | Nets | Rules |
| --- | --- | --- |
| Default | Other nets | 0.15 mm clearance |
| MGT_100R | `MGTP*`, `MGTREFCLK*`, `SFP?_TD_*`, `SFP?_RD_*`, `REFCLK_OSC_*` | Outer-only tracks; 0.099 mm width; 0.200 mm coupled gap; max 0.1 mm intra-pair skew |
| PSRAM | `PSRAM*`, including chip-side `_MEM` nets | 0.1 mm minimum and preferred width; 0.15 mm clearance |

The MGT class covers both sides of AC-coupling capacitors. Skew is checked
within each continuous P/N net pair, not between unrelated lanes or across
capacitors. KiCad 9 recognizes the existing `MGTPTXP0` / `MGTPTXN0` naming
(the suffix matcher skips trailing digits). All ten actual pairs were checked
with KiCad's `BOARD.DpCoupledNet()`.

Other copper stays at least 0.31 mm from MGT copper (approximately four
outer dielectric heights) to limit coplanar loading of the non-coplanar
model. Reference planes on adjacent layers are unaffected. Inner MGT tracks
are prohibited because this geometry is not calculated for those layers.
Plane transitions still require nearby ground stitching vias. Default vias
are 0.45 mm pad / 0.20 mm drill; board minimum track width is 0.0889 mm.

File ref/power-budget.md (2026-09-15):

# Odin power budget

**Generated by `tools/budget.py`. Do not hand-edit.** Every number below is
either a datasheet figure, or arithmetic on datasheet figures, or an estimate
that says so. Nothing here is a round number chosen because it looked right.

The load table is worst case *simultaneous*: both VCCIO domains jumpered to
3.3 V, two SFP modules fitted and powered, all four PSRAMs active, the FPGA
core busy. That is a case you can build, so it is the case the rails have to
survive.

## Regulators, loads and what is left over

| Ref | Part | Rail | Source | Vin seen | Capability | Board load | Spare |
|---|---|---|---|---|---|---|---|
| `U11` | `TPS54202DDC` | +5V | VSYS | 8.52–14.00 V | 2000 mA | 529 mA | 1471 mA |
| `U12` | `AP63300WU-7` | +3V3 | VSYS | 4.27–14.00 V | 3000 mA | 1367 mA | 1633 mA |
| `U13` | `TLV62569DRL` | +2V5 | +5V | 4.70–5.50 V | 2000 mA | 0 mA | 2000 mA |
| `U14` | `TLV62569DRL` | +1V8 | +5V | 4.70–5.50 V | 2000 mA | 180 mA | 1820 mA |
| `U15` | `SY8047QDC` | +1V0 | +5V | 4.70–5.50 V | 4000 mA | 1650 mA | 2350 mA |
| `U16` | `TLV62569DRL` | +1V2_MGT | +5V | 4.70–5.50 V | 2000 mA | 150 mA | 1850 mA |
| `U19` | `TPS61085PW` | +12V | +5V | 4.70–5.50 V | 622 mA | 0 mA | 622 mA |
| `U7` | `RP2350B VREG` | +1V1 | +3V3 | 3.30–3.30 V | 200 mA | 60 mA | 140 mA |

`Vin seen` is the range that rail's *source* covers across every documented
input, including the 0.48 V OR-ing drop from `VBUS` to `VSYS`
(SS34 forward drop plus the input eFuse). `Capability` is the
datasheet output rating, except for `+12V`, where it is computed below.
`Spare` is what remains for the extension slots after the board's own worst
case.

Two caveats on the +5 V row. It is `U11`'s 2 A rating, which only applies once
a 9 V contract or `J50` is present; **on a plain 5 V source the rail is `VBUS`
through `Q2`, so its ceiling is whatever the USB source gives** — 0.9 A on a
weak host port, against a board that already wants more than that. And the AUX
boost draws from this same rail, as the next section works out.

## The AUX 12 V rail, computed rather than asserted

`U19` is a `TPS61085` boost from +5 V. Its capability is not "5 V x 2 A / 12 V";
it is TI's design procedure (SLVS859B equations 1-4) at the worst-case input:

| | |
|---|---|
| Input, worst case | 4.70 V |
| Duty cycle | 64.8% |
| Inductor | 10 µH at 650 kHz |
| Inductor ripple | 468 mA p-p |
| Switch current limit | 2.0 A **minimum** |
| **Iout(max)** | **622 mA** |
| Peak switch current | 2.00 A |
| Draw on +5 V at full load | 1766 mA |

Two things follow. First, the honest boost figure is around
622 mA, not 700 mA — and even that assumes 90% efficiency
and ignores thermals, so treat it as a **provisional design target** until a
board is measured. Second, AUX at full output would pull
1766 mA out of the +5 V rail, which only has
1471 mA spare, so the boost is not the binding constraint
— the 5 V rail is. **AUX is therefore 518 mA**, and
every milliamp of it costs 2.84 mA of +5 V, so AUX and the
slots' own +5 V pins are drawing from the same pot.

## Active extension-bus limits

These switches sit before the per-slot PTCs. The resistor calculations use
the equations in TI SLVSFJ2B and SLVSFC9C.

| Protected bus | Part | Programming | Typical trip/limit | Datasheet range |
|---|---|---|---:|---:|
| `+5V_EXT` | TPS22950CDDCR | `RILIM=1.15 kohm`; `1.18 x 1.15^-1.072` | 1.000 A | 0.75-1.25 A; below 1.615 A source headroom |
| `+3V3_EXT` | TPS22950CDDCR | `RILIM=2.21 kohm`; `1.18 x 2.21^-1.072` | 0.500 A | 0.38-0.62 A |
| `VCCIO_1_EXT` | TPS22950CDDCR | same 2.21 kohm | 0.500 A | 0.38-0.62 A |
| `VCCIO_2_EXT` | TPS22950CDDCR | same 2.21 kohm | 0.500 A | 0.38-0.62 A |
| `+12V_EXT` | TPS259470LRPWR | `RILM=6.65 kohm`; `3334/6650` | 0.501 A | 0.425-0.575 A |

The +12 V switch, not the provisional 569 mA rail calculation, is now the
connector-facing ceiling. Its OVLO divider is 121 kohm / 12.1 kohm:
`1.2 x (121+12.1)/12.1 = 13.2 V` nominal. A 3.3 nF `dVdt` capacitor gives
about 20 ms rise time at 12 V. C232 adds 10 uF / 25 V directly on
+12V_EXT after U25, ahead of the selectors and PTCs. At this nominal
slew rate its added charging current is about 6 mA (`10uF * 12V / 20ms`),
excluding extension capacitance. Place it close to OUT and its ground return.

Worst-case selectable-rail checks use **620 mA**, the maximum limit of each
VCCIO switch, for both domains at once:

| Source selected by both domains | Base + two FPGA banks + two switch maxima | Regulator rating |
|---|---:|---:|
| +3V3 | 2.607 A | 3.000 A |
| +2V5 | 1.440 A | 2.000 A |
| +1V8 | 1.620 A | 2.000 A |

Note that TI's equation 2 is written with `ILIM(min)` but the accompanying
symbol list says "minimum switch current limit = 3.2 A", which is the
datasheet's *maximum*. The 2.0 A minimum from the electrical table is used
here, because that is the value guaranteed for every part.

## Inductors: what each rail requires

| Ref | Rail | L | Ripple | Peak | Isat required | Part fitted |
|---|---|---|---|---|---|---|
| `U11` | +5V | 10 µH | 643 mA p-p | 2.32 A | **3.02 A** | `SRN6045TA-100M`, Isat 4.60 A, 6.0 x 6.0 x 4.5 mm |
| `U12` | +3V3 | 4.7 µH | 1073 mA p-p | 3.54 A | **4.60 A** | `SRN6045TA-4R7M`, Isat 6.80 A, 6.0 x 6.0 x 4.5 mm |
| `U13` | +2V5 | 2.2 µH | 413 mA p-p | 2.21 A | **2.87 A** | `SRN4018-2R2M`, Isat 3.00 A, 4.0 x 4.0 x 1.8 mm |
| `U14` | +1V8 | 2.2 µH | 367 mA p-p | 2.18 A | **2.84 A** | `SRN4018-2R2M`, Isat 3.00 A, 4.0 x 4.0 x 1.8 mm |
| `U15` | +1V0 | 1 µH | 655 mA p-p | 2.80 A | **3.64 A** | `FTC201610S1R0MBCA`, Isat 4.60 A, 2.0 x 1.6 mm |
| `U16` | +1V2_MGT | 2.2 µH | 284 mA p-p | 0.37 A | **0.48 A** | `SRN4018-2R2M`, Isat 3.00 A, 4.0 x 4.0 x 1.8 mm |
| `U19` | +12V | 10 µH | 468 mA p-p | 2.00 A | **2.60 A** | `SRN6045TA-100M`, Isat 4.60 A, 6.0 x 6.0 x 4.5 mm |
| `U7` | +1V1 | 3.3 µH | 0 mA p-p | 0.06 A | **0.08 A** | `AOTA-B201610S3R3-101-T`, Isat 2.40 A, 2.0 x 1.6 x 1.0 mm |

`Isat required` is the peak inductor current with 30% margin, which is what
the TLV62569 datasheet asks for; `Peak` is taken at the rail's *rating* for
rails that reach a connector, and at 1.5x the actual load for +1V0, +1V2_MGT
and +1V1, which do not. Two part numbers cover seven positions, and
`tools/budget.py` fails if any of them saturates below what its rail needs.

## Load table, with the basis for every line

| Rail | Consumer | Current | Basis | Where it comes from |
|---|---|---|---|---|
| +1V0 | XC7A100T VCCINT, busy design | 1500 mA | estimate | pre-bitstream planning allowance; replace with an AMD XPE result |
| +1V0 | VCCBRAM | 50 mA | estimate | share of the 0.25 W AUX/BRAM line |
| +1V0 | +1V0_MGT (MGTAVCC, filtered off +1V0) | 100 mA | estimate | 2 lanes, share of the 0.4 W transceiver line |
| +1V8 | XC7A100T VCCAUX | 180 mA | estimate | pre-bitstream planning allowance; replace with an AMD XPE result |
| +1V2_MGT | MGTAVTT, 2 lanes | 150 mA | estimate | share of the 0.4 W transceiver line |
| +3V3 | RP2350B supervisor + boot flash | 70 mA | estimate | ref/power-input.md: 0.2 W |
| +3V3 | FPGA bank 14 VCCO and its I/O | 100 mA | estimate | one third of the 1.0 W VCCO/IO line |
| +3V3 | PSRAM x4, all active | 200 mA | estimate | ref/power-input.md: 0.66 W across four chips |
| +3V3 | config flash W25Q256, program | 30 mA | datasheet | W25Q256JV: 25 mA page-program peak |
| +3V3 | SFP modules x2 (SFP_VCC, gated by Q1) | 610 mA | estimate | ref/power-input.md: 2.0 W for two modules |
| +3V3 | Heartbeat and user LEDs x3, all on | 5 mA | estimate | D9-D11 via 1k each; 5 mA budget allowance |
| +3V3 | 125MHz LVDS oscillator | 40 mA | estimate | typical 6-pin LVDS oscillator |
| +3V3 | U9/U10 VCCA, U20, pull-ups, LED | 30 mA | estimate | quiescent logic |
| +3V3 | FPGA bank 15 VCCO, worst case jumpered to 3.3V | 100 mA | estimate | bank load only; connector export is checked from switch maximum below |
| +3V3 | FPGA bank 34 VCCO, worst case jumpered to 3.3V | 100 mA | estimate | bank load only; connector export is checked from switch maximum below |
| +3V3 | FPGA unused banks 13/16/35 VCCO | 60 mA | estimate | powered at 3.3V so every VCCO ball has a defined supply |
| +1V1 | RP2350B core (DVDD) | 60 mA | estimate | RP2350 at 150 MHz; the on-chip regulator is rated 200 mA |
| +5V | U9/U10 VCCB | 20 mA | estimate | quiescent translator supply |

Rails also load their parents: each buck's input current is added to the rail
it runs from, at 90% efficiency. That is why the +5 V and +3V3 figures in the
first table exceed the sum of their own lines.

## What a slot actually gets

| Rail | Shared total, all ten extension ports | Per-port fuse |
|---|---|---|
| +5V | **1000 mA typical (750-1250 mA)** | 500 mA |
| +3V3 | **500 mA typical (380-620 mA)** | 300 mA |
| +12V (AUX) | **500 mA typical (425-575 mA)** | 200 mA |

The fuses are fault protection. Nine of them do not add up to an allowance,
and the protected totals above are the connector-facing limits.

VCCIO is not in that table because it has no source of its own: the jumper
points a whole domain at +3V3, +2V5 or +1V8, and the domain's slots then share
whatever that rail has spare after the FPGA bank takes its share.

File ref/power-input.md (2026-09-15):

# Powering Odin

**One USB-C connector. That is the whole story.** Plug it into a computer, a
charger, or a USB-C power bank. There is no barrel jack you must find and no
battery to charge.

## The budget, so the numbers are not a guess

| | Peak |
|---|---|
| FPGA core (`VCCINT`, pre-bitstream allowance) | 1.5 W |
| `VCCAUX` + `VCCBRAM` | 0.37 W |
| `VCCO` and I/O | 1.2 W |
| PSRAM x4, active | 0.66 W |
| Supervisor + flash | 0.2 W |
| Transceiver rails, 2 lanes | 0.4 W |
| Two SFP modules | 2.0 W |
| **Base board** | **≈ 6.3 W** |
| LCD logic (Gameboy extension) | 0.5 W |
| Class-D audio amp, peak | 2.5 W |
| LCD backlight | 1.35 W |
| **With one extension** | **≈ 10.7 W** |

Add two-stage regulator losses and it is **about 13–14 W at the connector**.

That matters, because it rules something out. **Plain 5 V USB is not enough.**
A laptop port often gives 5 V at 0.9 A — 4.5 W. Even a good 5 V/3 A source is
15 W, which is the budget with nothing to spare.

## How reliable is 9 V, really?

Reliable **from a charger**, and often absent **from a computer** — which is
the awkward part, because a dev board spends its life plugged into a computer.

The USB-PD Power Rules make this precise. A source's fixed voltages are
determined by its rating:

| Source rating | Must offer |
|---|---|
| up to 15 W | 5 V |
| 15–27 W | 5 V, **9 V** |
| 27–45 W | 5 V, 9 V, 15 V |
| 45–60 W | 5 V, 9 V, 15 V, 20 V |

So **9 V is mandatory on any PD source above 15 W** — every phone charger,
laptop brick and decent power bank has it. Note what is *not* in that table:
**12 V is not a PD Power Rules voltage at all.** It is an optional extra some
sources add, which is why this board does not depend on it.

The catch is the other end. Plenty of laptop and desktop USB-C ports do no PD
negotiation whatsoever and simply offer 5 V at 0.9 A or 3 A. That is the port
you are plugged into while you write HDL.

## Therefore: 5 V is the design assumption, PD is headroom

The board is built so that **everything works at 5 V**. Power Delivery changes
how much current you can draw, not what functions. Specifically, the 12 V AUX
rail is **boosted from the 5 V rail** rather than taken from the input, so an
extension's backlight or motor works whether you are on a laptop port or a
45 W charger.

What PD actually buys you: at 9 V a 3 A source delivers 27 W against a 13 W
budget, and the current through the connector drops from ~2.6 A to ~1.4 A.
Headroom and less loss — not features.

## The negotiation, in the schematic

A `CH224K` sink chip owns the connector's CC lines and asks for 9 V. If the
source cannot supply it, the board stays on 5 V and keeps working.

**Firmware must never request more than 9 V.** `D7` is an `SMBJ13A`: a
**unidirectional** 600 W TVS on `VBUS`, cathode to `VBUS`, anode to ground.
Its reverse standoff is 13 V and its breakdown is 14.4 V minimum. A 15 V
contract sits above the standoff, where leakage climbs steeply; a 20 V
contract puts it into sustained avalanche, which a 600 W transient part will
not survive as a DC condition. (It does not *forward*-conduct — that only
happens if the part is fitted backwards, which is why the schematic uses a
polarised symbol rather than the bidirectional `SMBJ13CA` one.)

9 V is the design limit, the protection is chosen for it, and the limit
belongs in the firmware as an assertion, not a comment.

The supervisor drives the sink's three configuration pins, so **the requested
voltage is firmware, not a soldered strap** (within that 9 V ceiling). It can ask for something else if
your extension needs it, and it reads the sink's power-good pin to find out
whether the request actually succeeded.

## Inrush: why there is an eFuse between the connector and everything else

USB caps how much capacitance a device may hang on `VBUS` at the moment the
cable goes in: 10 µF, or 50 µC of inrush charge. USB-PD raises that to 100 µF
only *after* a contract exists — and at plug-in there is no contract. Behind
the OR-ing diode this board has 44 µF of `VSYS` bulk, which is five times the
allowance and would show up as a drooping source, a sparking connector, and a
board that starts on one charger and not another.

So `VBUS` reaches that bulk through **`U26`, a `TPS259470A` eFuse**, not a
bare diode. Its `dVdt` capacitor sets a controlled rise of about 0.91 V/ms,
so charging the 44 µF `VSYS` bulk draws about 40 mA. It works without
firmware — this path produces +3V3, so it cannot wait for firmware that +3V3
has to boot first. It also rejects inputs below about 3.75 V or above about
9.98 V, limits current to about 2.03 A, blocks reverse current when off, and
reports a fault on `EXT_FAULT`. The 10 µF directly on `VBUS` is the USB
attach allowance, spent on purpose.

`Q2`, the 5 V pass switch, has a 100nF gate-source capacitor because closing
it connects VBUS to 66µF of +5V bulk. R49 is 47k against a 100k gate-source
pull-up: its gate RC time constant is approximately 3.20ms. The divider
limits VGS to -6.12V at a 9V firmware fault, within the ±8V gate rating.
Firmware must still keep Q2 off at 9V to protect the +5V loads.
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

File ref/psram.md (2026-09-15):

# PSRAM — 4 chips, 4 independent ports

`APS1604M-3SQR-SN` ×4 (LCSC C18214056), QSPI, 3.3V. The point of this part is
what BRAM and DDR3 both fail at: **enough capacity to be useful, with
single-cycle-predictable random access down to one byte.** No burst-shaped
thinking, no calibration, no memory controller IP you cannot read.

## The one wiring decision

Four QSPI chips can be wired three ways. Only one of them is right.
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

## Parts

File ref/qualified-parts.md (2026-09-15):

# Qualified parts

**Generated by `tools/qualified.py`. Do not hand-edit.**

A footprint that matches its symbol's `ki_fp_filters` is not a qualified part.
The filter can be missing, or broad enough to admit the wrong package, and it
knows nothing about whether the part survives the voltage on the net it is
soldered to. This page is the stronger claim, and `tools/design.py` will not
build if a part here is fitted with a different footprint, or if a non-generic
part is missing from it altogether.

`NOT SELECTED` and `ASSUMED` mean exactly that. Those rows are the open work.

Ordinary passives are not listed individually. Resistors and capacitors are
0402 or 0603; what matters about them is voltage rating and dielectric, which
is [`ref/power-budget.md`](power-budget.md) and `findings.md` item 13.
Inductors *are* qualified, per rail, in
[`ref/power-budget.md`](power-budget.md) -- the requirement is computed there,
so the part is named there.

| Designator(s) | MPN | Package | Footprint | Ratings that matter here | Pin map | Source |
|---|---|---|---|---|---|---|
| `U1` | **XC7A100T-2FGG676I** | FGG676, 27x27 mm BGA, 1.0 mm pitch | `EasyEDA:FBGA-676_L27.0-W27.0-R26-C26-P1.00-BL` | VCCINT 1.0 V, VCCAUX 1.8 V, VCCO 1.8/2.5/3.3 V per HR bank | all 676 balls from imported EasyEDA/LCSC C1521803 symbol; functional allocation generated by tools/alloc.py | LCSC C1521803 and AMD Artix-7 documentation |
| `D1`, `D9`, `D10`, `D11` | **F.0603.00025/P2-0603G1TS2-06T-002** | 0603 (1608 metric) | `EasyEDA:LED0603-RD_GREEN` | green, 2.6-2.9 V, 230 mcd, 30 mA max | imported C7496818: pad 1 cathode, pad 2 anode | LCSC C7496818 |
| `U2`, `U3`, `U4`, `U5` | **APS1604M-3SQR-SN** | SOP-8 150 mil (3.9x4.9 mm) | `EasyEDA:SOIC-8_L4.9-W3.9-P1.27-LS6.0-BL` | 2.7-3.6 V, 16 Mbit QSPI PSRAM, tCEM 8 us | KiCad Memory_RAM symbol | APMemory datasheet; LCSC C18214056 |
| `U6` | **W25Q256JVEIQ** | WSON-8, 8x6 mm, 1.27 mm pitch | `EasyEDA:WSON-8_L8.0-W6.10-P1.27-BL-EP` | 2.7-3.6 V, 256 Mbit, 25 mA program peak | generated from the standard 8-pin QSPI NOR pinout, tools/gen_kicad.py FLASH_PINS | Winbond W25Q256JV datasheet; LCSC C97522 |
| `U7` | **RP2350B** | QFN-80, 10x10 mm, 0.4 mm pitch, 3.4x3.4 mm pad | `EasyEDA:QFN-80_L10.0-W10.0-P0.40-TL-EP3.4` | IOVDD 3.3 V, DVDD 1.1 V from the on-chip switcher (200 mA), ADC input 0..ADC_AVDD | KiCad MCU_RaspberryPi symbol, pins resolved by name | RP2350 datasheet; RP-008280 hardware design guide |
| `Y1` | **ABM8-272-T3** | 3.2x2.5 mm, 4 pad | `EasyEDA:CRYSTAL-SMD_4P-L3.2-W2.5-BL` | 12 MHz, +/-30 ppm, CL 10 pF, ESR 50 ohm max | 2-pad crystal with grounded shield; G ties both shield pads | RP-008280 s4.1 names this exact part and the 1k damping resistor |
| `U8` | **W25Q32JVZPIQ** | WSON-8, 6x5 mm, 1.27 mm pitch | `EasyEDA:WSON-8_L6.0-W5.0-P1.27-BL-EP` | 2.7-3.6 V, 32 Mbit | KiCad symbol checked against imported C571260 pads; standard QSPI NOR | Winbond W25Q32JV datasheet; LCSC C571260 |
| `J1` | **HC-TYPE-C-16P-01A** | USB-C receptacle, 16 position, mid-mount | `Connector_USB:USB_C_Receptacle_HCTL_HC-TYPE-C-16P-01A` | 5 A contacts, 20 V. Board never negotiates above 9 V | KiCad Connector symbol for this exact part number | HCTL datasheet as shipped with the KiCad footprint |
| `D6` | **ESDA6V1BC6** | SOT-23-6 | `EasyEDA:SOT-23-6_L2.9-W1.6-P0.95-LS2.8-BR` | 4-line bidirectional ESD array, 6.1 V standoff. On D+, D-, CC1, CC2 -- data and CC only, never VBUS | KiCad Power_Protection symbol | ST ESDA6V1BC6 datasheet |
| `D7` | **SMBJ13A-TR** | SMB / DO-214AA | `EasyEDA:SMB_L4.6-W3.6-LS5.3-RD` | UNIDIRECTIONAL. 13 V standoff, VBR 14.4 V min at 1 mA, VC 21.5 V at 28 A IPP, 600 W. Cathode to VBUS, anode to GND | 2-pin polarised; KiCad ships no unidirectional TVS symbol, so the polarised avalanche symbol stands in | Littelfuse/Diodes SMBJ series datasheet |
| `U18` | **CH224K** | SSOP-10 with exposed pad (3.9x4.9 mm) | `EasyEDA:ESSOP-10_L4.9-W3.9-P1.0-LS6.0-TL-EP` | PD/QC sink controller, 3.3-22 V VBUS. CFG1..3 driven by the supervisor; firmware must never request above 9 V (D7) | KiCad Interface_USB symbol | WCH CH224 datasheet |
| `SW1` | **B3U-1000P** | SMD tactile, 3.5x2.9 mm | `EasyEDA:KEY-SMD_B3U-1000PM` | 32 V, 50 mA | 2-pin SPST | Omron B3U datasheet |
| `J51` | **BM03B-SRSS-TB(LF)(SN)** | JST-SH 3-pin vertical SMT, 1.0 mm | `EasyEDA:CONN-SMD-3P-P1.00_BM03B-SRSS-TB-LF-SN` | 1 A, 50 V; keyed controller SWD connection | 1 SWCLK, 2 GND, 3 SWDIO; pads 4/5 mechanical | LCSC C160389 |
| `U20` | **SN74CB3Q3384APWR** | TSSOP-24 (PW) | `EasyEDA:TSSOP-24_L7.8-W4.4-P0.65-LS6.4-BL` | 2.3-3.6 V VCC, 5 ohm typical channel on-resistance, 10 bits in two banks of 5. Only bank 1 is used; bank 2 OE is tied high | KiCad 74xx symbol, pins resolved by name | TI SCDS131 |
| `J52` | **PZ254V-11-02P** | 1x2 male selector header, 2.54 mm, THT | `EasyEDA:HDR-TH_2P-P2.54-V-M` | selector only | 1 3V3, 2 external-JTAG select | XFCN drawing; LCSC C492401 |
| `J2` | **2.54-2*5P** | keyed 2x5 IDC box header, 2.54 mm, through-hole | `EasyEDA:IDC-TH_10P-P2.54_C5665` | 1 A, keyed JTAG connection | imported C5665, pins 1-10 | LCSC C5665 |
| `U9`, `U10` | **SN74LXC8T245PWR** | TSSOP-24 (PW) | `EasyEDA:TSSOP-24_L7.8-W4.4-P0.65-LS6.4-BL_1` | 1.1-5.5 V on both VCCA and VCCB; VCCA=3V3, VCCB=5V here | CONFIRMED against TI TSSOP-24 pinout: 1 VCCA, 2 DIR, 3-10 A1..A8, 11-13 GND, 14-21 B8..B1, 22 OE, 23-24 VCCB. findings item 11 | TI SCES864; symbol is AVC8T245 renamed, tools/gen_kicad.py |
| `J3`, `J4`, `J5`, `J6` | **PM254-2-16-S-8.5** | 2x16 female socket, 2.54 mm, SMT, 8.5 mm | `EasyEDA:HDR-SMD_32P-P2.54-V-F-R2-C16-LS7.1` | 3 A per contact | physical row 1..16, return row 32..17 | HCTL drawing; LCSC C3975161 |
| `J53`, `J54`, `J55`, `J56` | **ZX-PM2.54-1-16PY** | 1x16 female socket, 2.54 mm, THT, 8.5 mm | `EasyEDA:HDR-TH_16P-P2.54-V-F-1` | 3 A per contact | pins 1..16 in physical order | Megastar drawing; LCSC C7499334 |
| `J7`, `J8` | **PM254-2-08-S-8.5** | 2x8 female socket, 2.54 mm, SMT, 8.5 mm | `EasyEDA:HDR-SMD_16P-P2.54-V-F-R2-C8-LS7.1` | 3 A per contact | odd/even pin pairs by physical column | HCTL drawing; LCSC C3975153 |
| `J57`, `J58` | **2.54-1*8P** | 1x8 female socket, 2.54 mm, THT | `EasyEDA:HDR-TH_8P-P2.54-V-F` | 3 A per contact | pins 1..8 in physical order | BOOMELE drawing; LCSC C27438 |
| `MK76`, `MK77`, `MK65`, `MK66`, `MK67`, `MK68`, `MK69`, `MK70`, `MK71`, `MK72` | **PH2.54-1X1P-H25** | 1x1 male guide post, 2.54 mm, THT | `EasyEDA:HDR-TH_1P-P2.54-V-M` | 3 A; 6 mm mating post | single grounded guide pin | JXTCONN drawing; LCSC C42431799 |
| `J10`, `J21`, `J11`, `J12`, `J13`, `J14`, `J15`, `J16`, `J17`, `J18`, `J19`, `J20` | **2.54-2*3P** | 2x3 male selector header, 2.54 mm, THT | `EasyEDA:HDR-TH_6P-P2.54-V-M-R2-C3-S2.54-1` | selector only | odd/even pin pairs by physical column | BOOMELE drawing; LCSC C65114 |
| `X2` | **DSC1123CI2-125.0000** | 6-pad VDFN, 3.2x2.5 mm | `EasyEDA:OSC-SMD_6P-L3.2-W2.5-BL` | 125 MHz LVDS, 2.25-3.63 V, +/-25 ppm, 32 mA maximum | Microchip DSC1103/23 table 2-2: 1 EN, 2 NC, 3 GND, 4 OUT+, 5 OUT-, 6 VDD; imported C617173 agrees | Microchip DSC1103/23 datasheet; LCSC C617173 |
| `Q1` | **DMG2305UX-7** | SOT-23 | `EasyEDA:SOT-23-3_L2.9-W1.3-P1.90-LS2.4-BR` | -20 V VDSS, +/-8 V VGSS, -4.2 A, RDS(on) 52 mohm max at VGS -4.5 V. Source at +3V3, so VGS never exceeds -3.3 V | G-S-D SOT-23, pins 1-2-3 | Diodes Inc DMG2305UX datasheet |
| `J60`, `J61` | **1888247-1** | SFP/SFP+ SMT connector, 20 position | `EasyEDA:CONN-SMD_20P-P0.80-S8.20_1888247-1` | 3.3 V, 1 W per module assumed | KiCad Interface_Optical symbol | TE 1888247 drawing; LCSC C305914 |
| `SH1`, `SH2` | **U77A11133001** | SFP 1x1 cage, 3.2 mm solder tails | `odin:Amphenol_U77A11133001` | Manufacturer lists 2.5 Gb/s; all shield tails GND; JLC wave solder | Drawing-based symbol/footprint; 20 solder tails; see ref/sfp-cage.md | Amphenol P-U77-A111X-XX0X rev H; JLC/LCSC C5355132 |
| `U17` | **PCF8574T_3,518** | SOIC-16W (7.5x10.3 mm) | `EasyEDA:SOIC-16_L10.3-W7.5-P1.27-LS10.3-BL` | 2.5-6 V, quasi-bidirectional I/O; P0-P2 sink LEDs at about 1 mA each; P3 reads core PG; P7 controls SFP power | Imported EasyEDA symbol/footprint; LCSC C7605 | NXP PCF8574 datasheet; LCSC C7605 |
| `Q2` | **DMG2305UX-7** | SOT-23 | `EasyEDA:SOT-23-3_L2.9-W1.3-P1.90-LS2.4-BR` | -20 V VDSS, +/-8 V VGSS, -4.2 A, PD 1.4 W. 100k/47k gate divider: VGS -3.40 V at 5 V, -6.12 V at 9 V. Firmware must still forbid passing 9 V onto +5V. See findings 21 | G-S-D SOT-23, pins 1-2-3 | Diodes Inc DMG2305UX datasheet |
| `Q3`, `Q4` | **BSS138LT1G** | SOT-23 | `EasyEDA:SOT-23-3_L2.9-W1.6-P1.90-LS2.8-BR` | 50 V, 200 mA; RDS(on) max 10 ohm at VGS 2.75 V (-40..85 C). Q3 pulls a gate through 47k; Q4 sinks approximately 2-4 mA for DONE LED | G-S-D SOT-23, pins 1-2-3 | onsemi BSS138LT1/D, https://www.onsemi.com/pdf/datasheet/bss138lt1-d.pdf |
| `J50` | **KF301-5.0-2P** | 2-position 5.0 mm screw terminal, through-hole | `EasyEDA:CONN-TH_P5.00_KF301-5.0-2P` | 17 A, 250 V component rating; Odin input limited to 9-14 V | 1 VIN_EXT (+), 2 GND (-) | LCSC C474881 |
| `U26` | **TPS259470ARPWR** | VQFN-HR-10, 2x2 mm, 0.5 mm pitch (TI RPW) | `Package_DFN_QFN:Texas_RPU0010A_VQFN-HR-10_2x2mm_P0.5mm` | 2.7-23 V input, true reverse blocking, auto-retry. Input path: 100k/47k UVLO = 3.75 V, 73.2k/10k OVLO = 9.98 V, 1.65k ILM = 2.03 A typical, 2.2 nF dVdt = 0.91 V/ms and about 40 mA into 44 uF | TI RPW top view: 1 EN/UVLO, 2 OVLO, 3 AUXOFF, 4 FLT, 5 IN, 6 OUT, 7 dVdt, 8 GND, 9 ILM, 10 ITIMER | TI TPS25947 datasheet SLVSFC9C |
| `D3`, `D4`, `D5` | **SS34** | SMA / DO-214AC | `EasyEDA:SMA_L4.3-W2.6-LS5.2-RD` | 40 V, 3 A, Vf about 0.45 V at 0.5 A. D3/D4 OR the inputs, D5 rectifies the boost at 650 kHz and 2 A peak | 2-pin polarised | generic SS34, multiple vendors |
| `U11` | **TPS54202DDCR** | SOT-23 (6) | `EasyEDA:SOT-23-6_L2.9-W1.6-P0.95-LS2.8-BL` | 4.5-28 V in, 2 A out, 500 kHz, 5 ms internal soft start. The 4.5 V minimum is the binding constraint -- see findings 20 | KiCad Regulator_Switching symbol | TI SLVSD26C; LCSC C191884 |
| `U12` | **AP63300WU-7** | TSOT26 (WU) | `EasyEDA:TSOT-23-6_L2.9-W1.6-P0.95-LS2.8-BR` | 3.8-32 V input, 3 A output, 500 kHz, 0.8 V reference. 3.3 V reference circuit: 93.1k/30.1k feedback, 56 pF feed-forward, 4.7 uH, 10 uF input, 3x22 uF output | Diodes TSOT26 top view: 1 FB, 2 EN, 3 VIN, 4 GND, 5 SW, 6 BST | Diodes Incorporated DS42002 Rev. 3-2, Table 1 |
| `U13`, `U14`, `U16` | **TLV62569DRLR** | SOT-563 | `EasyEDA:SOT-563_L1.6-W1.2-P0.50-LS1.6-BL` | 2.5-5.5 V in, 2 A out, 1.5 MHz; output cap 10-47 uF | KiCad Regulator_Switching symbol | TI SLVSDG1C; LCSC C163217 |
| `U15` | **SY8047QDC** | QFN-16-EP, 3x3 mm, 0.5 mm pitch | `EasyEDA:TQFN-16_L3.0-W3.0-P0.50-TL-EP1.6` | 2.5-5.5 V in, 4 A out, 1.25 MHz, 0.6 V feedback, 5 A minimum peak-current limit | Imported C3018651 symbol and footprint checked against the Silergy SY8047 Rev 0.9 top-view pinout | Silergy SY8047 Rev 0.9; LCSC C3018651 |
| `U19` | **TPS61085PWR** | TSSOP-8 (PW), 3.0x4.4 mm body, 6.4 mm lead span | `EasyEDA:TSSOP-8_L4.4-W3.0-P0.65-LS6.4-BL` | 2.3-6 V in, 18.5 V max out, switch limit 2.0 A min / 3.2 A max, 650 kHz with FREQ grounded | KiCad Regulator_Switching symbol | TI SLVS859B |
| `U21`, `U22`, `U23`, `U24` | **TPS22950CDDCR** | SOT-23-THIN-6 (TI DDC) | `EasyEDA:SOT-23-6_L2.9-W1.6-P0.95-LS2.8-BL_3` | 1.8-5.5 V in, 6 V absolute max on VIN/VOUT, 3.2 A switch; adjustable current limit, thermal shutdown, fixed controlled turn-on, reverse blocking enabled and disabled. U21: 1.15k = 1.000 A typical (0.75-1.25 A). U22-U24: 2.21k = 0.500 A typical (0.38-0.62 A) | TI DDC top view: 1 ON, 2 VIN, 3 GND, 4 ILIM, 5 VOUT, 6 FLT | TI TPS22950x datasheet SLVSFJ2B |
| `U25` | **TPS259470LRPWR** | VQFN-HR-10, 2x2 mm, 0.5 mm pitch (TI RPW) | `Package_DFN_QFN:Texas_RPU0010A_VQFN-HR-10_2x2mm_P0.5mm` | 2.7-23 V operating, 28 V absolute max, back-to-back FETs and true reverse blocking. 6.65k ILM = 500 mA typical (425..575 mA); 121k/12.1k OVLO = 13.2 V nominal; 3.3nF dVdt = about 20 ms rise; active current limiting and latch-off fault response | TI RPW top view: 1 EN/UVLO, 2 OVLO, 3 AUXOFF, 4 FLT, 5 IN, 6 OUT, 7 dVdt, 8 GND, 9 ILM, 10 ITIMER | TI TPS25947 datasheet SLVSFC9C |
| `U27` | **PCA9543APW,118** | TSSOP-14, SOT402-1 | `Package_SO:TSSOP-14_4.4x5mm_P0.65mm` | 2.3-5.5 V, 400 kHz; fitted at 3.3 V; address 0x70; POR disconnects both channels | NXP Table 3: 1 A0, 2 A1, 3 RESET, 4 INT0, 5 SD0, 6 SC0, 7 VSS, 8 INT1, 9 SD1, 10 SC1, 11 INT, 12 SCL, 13 SDA, 14 VDD | NXP PCA9543A_43B rev 8; LCSC C2652904 |
| `D8` | **SMBJ15A-13-F** | SMB / DO-214AA | `Diode_SMD:D_SMB` | Unidirectional, 15 V standoff, 16.7-19.2 V breakdown, 24.4 V maximum rated pulse clamp, 600 W. Transient suppression on VIN_EXT | 1 cathode to VIN_EXT; 2 anode to GND | Diodes SMBJ15A https://www.diodes.com/part/view/SMBJ15A; LCSC C135046 |

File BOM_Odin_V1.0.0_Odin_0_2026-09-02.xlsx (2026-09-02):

No. | Quantity | Comment | Designator | Footprint | Value | Manufacturer Part | Manufacturer | Supplier Part | Supplier | Category | Primary Category | Secondary Category | Pin Count | LCSC Price | LCSC Stock | JLCPCB Stock | JLCPCB Price | Layer | Mounting Style | Add into BOM | Convert to PCB | 3D Model Title | Device | Name | Unique ID | 3D Model Transform | Applications Function | Block Erase Time (tBE) | Circluar Pins/Square Pins | Clock Frequency (fc) | Color | Contact Material | Current Rating (Max) | Contact Plating | Data Retention - TDR (Year) | Datasheet | Description | Holes Structure | Input Low Voltage | Insulation Height | Interface | Interface Type | Intput High Voltage | JLCPCB Part Class | LCSC Part Name | Length of Mating Pin | link | Memory Size | Mounting Type | Number of Holes | Number of Outputs | Number of Pins | Number of Rows | Operating Temperatue | Operating Temperature | Operating Temperature Range | Origin Footprint | Output Frequency (Max) | Output High Voltage
1 | 10 | 10uF | C1,C3,C6,C8,C9,C13,C17,C59,C60,C61 | CAP-SMD_L3.2-W1.6-RD |  | TC211A106M016Y | Sunlord(顺络) | C128289 | LCSC |  |  |  | 2 |  |  | 0 | 0.0179 | T | SMT | yes |  | CASE-A_L3.2-W1.6-H1.6 | 10uF | 10uF | gge5cccce6593b3d43b,gge6d64befe918dde85,gge8ec28b75d59d422b,gge9eae123af1f9a171,gge38c6738ede282cb9,gge86ca39e8be6af7d7,gge601ba33b989a714e,ggeb9984f18d83ff8b5,gged811ad05cb8e4a23,ggee017db015057c9ed | 125.984,62.992,0,0,0,0,0,0,0 |  |  |  |  |  |  |  |  |  |  |  |  |  |  |  |  |  | Extended Part |  |  |  |  |  |  |  |  |  |  |  |  | CAP-SMD_L3.2-W1.6-RD
2 | 6 | 22uF | C4,C46,C47,C48,C49,C62 | C0805 |  | CGA0805X5R226M350MT | HRE(芯声) | C6119901 | LCSC |  |  |  | 2 |  |  | 341812 | 0.0334 | T | SMT | yes |  |  | 22uF | 22uF | gge3cd74c793075a7d2,gge3eb8da259e43a409,gge13bf5ceafe28c5ef,gge82e5fef67bdc5073,ggea3fbdc838ea8a353,ggedca7ce7e2e176c4a |  |  |  |  |  |  |  |  |  |  |  |  |  |  |  |  |  |  | Extended Part |  |  |  |  |  |  |  |  |  |  |  |  | C0805
3 | 4 | 10pF | C10,C12,C14,C58 | C0201 |  | GRM0335C1H100FA01D | muRata(村田) | C384956 | LCSC |  |  |  | 2 |  |  | 603013 | 0.001 | T | SMT | yes |  | C0201_L0.6-W0.3-H0.3 | 10pF | 10pF | gge20d4b5dd3f944e06,gge41bd3df809b0ce67,gge51e5f620340ac464,gged6a796f076fb8963 | 23.622,11.811,0,0,0,0,0,0.001,0 |  |  |  |  |  |  |  |  |  |  |  |  |  |  |  |  |  | Extended Part |  |  |  |  |  |  |  |  |  |  |  |  | C0201
4 | 1 | 10nF | C15 | C0603 |  | CL10B103KB8NNNC | SAMSUNG(三星) | C1589 | LCSC |  |  |  | 2 |  |  | 2273824 | 0.0016 | T | SMT | yes |  |  | 10nF | 10nF | gge836d933fdb2f03d8 |  |  |  |  |  |  |  |  |  |  |  |  |  |  |  |  |  |  | Extended Part |  |  |  |  |  |  |  |  |  |  |  |  | C0603
5 | 12 | 100nF | C18,C22,C32,C33,C37,C38,C39,C64,C74,C78,C79,C80 | C0603 |  | C0603X104K050T | IHHEC(禾伸堂) | C187860 | LCSC |  |  |  | 2 |  |  | 1205910 | 0.0026 | T | SMT | yes |  |  | 100nF | 100nF | gge35c0a32a0429af9b,gge700b0e05c244a096,gge6831bca90c774b50,gge8771cb6a298038de,ggeaf047adf4f1cadfb,ggee58a232291e2d3be,ggef1549c696e82380f,ggefc5e9850a8a93864,ggeff0c59d2769d659d,ggeff0c59d2769d659d_1,ggeff0c59d2769d659d_2,ggeff0c59d2769d659d_3 |  |  |  |  |  |  |  |  |  |  |  |  |  |  |  |  |  |  | Extended Part |  |  |  |  |  |  |  |  |  |  |  |  | C0603
6 | 4 | 22uF | C25,C26,C45,C63 | CASE-A_3216 |  | CA45-A6R3K226T | 湘怡中元/湘江 | C122912 | LCSC |  |  |  | 2 |  |  | 0 | 0.0123 | T | SMT | yes |  | CASE-A_L3.2-W1.6-H1.6 | 22uF | 22uF | gge9b093b79c63b9c4b,gge15b8249ab18abbbf,gge29f0fcfc16f7fa05,gge5194aa2add94dd43 | 125.984,62.992,0,0,0,0,-0.003,0,0 |  |  |  |  |  |  |  |  |  |  |  |  |  |  |  |  |  | Extended Part |  |  |  |  |  |  |  |  |  |  |  |  | CASE-A_3216
7 | 4 | 75pF | C27,C28,C34,C44 | C0805 |  | CC0805FRNPO9BN750 | YAGEO(国巨) | C541521 | LCSC |  |  |  | 2 |  |  | 5213 | 0.0067 | T | SMT | yes |  |  | 75pF | 75pF | gge3d5d64c2092e8ea4,gge25b67497cb558ebf,ggeb0f830825bd5c77a,ggefb5dcd90cf0db5b1 |  |  |  |  |  |  |  |  |  |  |  |  |  |  |  |  |  |  | Extended Part |  |  |  |  |  |  |  |  |  |  |  |  | C0805
8 | 4 | 10uF | C40,C41,C42,C43 | C1210 |  | CS3225X7R106K500NRL | SAMWHA(三和) | C2918502 | LCSC |  |  |  | 2 |  |  | 117499 | 0.034 | T | SMT | yes |  | C1210_L3.2-W2.5-H0.9 | 10uF | 10uF | gge4e17824d3df18d4d,ggea7ad95c7aa2d81c5,ggea574203845fb6d50,ggec85622f6ac93dfb9 | 125.984,99.2124,0,0,0,0,0,0,0 |  |  |  |  |  |  |  |  |  |  |  |  |  |  |  |  |  | Extended Part |  |  |  |  |  |  |  |  |  |  |  |  | C1210
9 | 1 | 100nF | C73 | C0603 |  | TCC0603X7R104K500CT | CCTC(三环) | C282519 | LCSC |  |  |  | 2 |  |  | 1987056 | 0.0016 | T | SMT | yes |  |  | 100nF | 100nF | gge015631cb4d90da18 |  |  |  |  |  |  |  |  |  |  |  |  |  |  |  |  |  |  | Extended Part |  |  |  |  |  |  |  |  |  |  |  |  | C0603
10 | 1 | 100nF | C75 | C0603 | 100nF | C0603X104K050T | IHHEC(禾伸堂) | C187860 | LCSC | Capacitors:Multilayer Ceramic Capacitors MLCC - SMD/SMT | Capacitors | Multilayer Ceramic Capacitors MLCC - SMD/SMT | 2 |  |  | 1205910 | 0.0026 | T | SMT | yes |  | C0603_L1.6-W0.8-H0.8 | C0603X104K050T | 100nF | gge4 | 62.992,31.496,0,0,0,0,0,0,0 |  |  |  |  |  |  |  |  |  | https://atta.szlcsc.com/upload/public/pdf/source/20180316/B1A881EE882D7AA2911761F448C7BFE2.pdf | Capacitance: Tolerance:±10% Tolerance:±10% Voltage Rated: Temperature Coefficient: |  |  |  |  |  |  | Extended Part | 100nF ±10% 50V
11 | 1 | 10uF | C76 | C1210 | 10uF | CS3225X7R106K500NRL | SAMWHA(三和) | C2918502 | LCSC | Capacitors:Multilayer Ceramic Capacitors MLCC - SMD/SMT | Capacitors | Multilayer Ceramic Capacitors MLCC - SMD/SMT | 2 |  |  | 117499 | 0.034 | T | SMT | yes |  | C1210_L3.2-W2.5-H2.5 | CS3225X7R106K500NRL | 10uF | gge5 | 125.984,98.425,0,0,0,0,0,0,0 |  |  |  |  |  |  |  |  |  | https://atta.szlcsc.com/upload/public/pdf/source/20230815/D6EC8E8D4948B4151F2C89DF2FF24A45.pdf | Capacitance: Voltage Rated: Temperature Coefficient: |  |  |  |  |  |  | Extended Part | 10uF 50V
12 | 1 | 1SMA5918A_C19077487 | D5 | SMA_L4.3-W2.6-LS5.0-RD |  | 1SMA5918A | 宏迦橙 | C19077487 | LCSC |  |  |  | 2 |  |  | 71 | 0.0171 | T | SMT | yes |  | SMA_L4.3-W2.6-LS5.0-RD | 1SMA5918A_C19077487 | 1SMA5918A_C19077487 | ggee4510b5a653adfc5 | 196.85,102.362,0,0,0,0,0,0,0 |  |  |  |  |  |  |  |  |  |  |  |  |  |  |  |  |  | Extended Part |  |  |  |  |  |  |  |  |  |  |  |  | SMA_L4.3-W2.6-LS5.0-RD
13 | 1 | 1SMA5924BT3G | D6 | SMA_L4.3-W2.6-LS5.2-RD |  | 1SMA5924BT3G | onsemi(安森美) | C50839 | LCSC |  |  |  | 2 |  |  | 894 | 0.0225 | T | SMT | yes |  | SMA_L4.3-W2.6-LS5.2-RD | 1SMA5924BT3G | 1SMA5924BT3G | gge1a3e8a6ff0858303 | 185.039,102.362,0,0,0,0,-0.001,0.001,0 |  |  |  |  |  |  |  |  |  |  |  |  |  |  |  |  |  | Extended Part |  |  |  |  |  |  |  |  |  |  |  |  | SMA_L4.3-W2.6-LS5.2-RD
14 | 1 | SS54_C22452 | D14 | SMA_L4.4-W2.8-LS5.4-R-RD |  | SS54 | MDD(辰达半导体) | C22452 | LCSC |  |  |  | 2 |  |  | 2502254 | 0.0066 | T | SMT | yes |  | SMA_L4.4-W2.8-LS5.4-R-RD | SS54_C22452 | SS54_C22452 | gge835c5ca1a06f1dca | 204.724,110.236,0,0,0,0,0.001,0,0 |  |  |  |  |  |  |  |  |  |  |  |  |  |  |  |  |  |  |  |  |  |  |  |  |  |  |  |  |  |  | SMA_L4.4-W2.8-LS5.4-R-RD
15 | 8 | 3-644456-2 | H5,H6,H7,H8,H9,H10,H11,H12 | HDR-TH_2P-P2.54-V-M-1 |  | 3-644456-2 | TE Connectivity(泰科电子) | C90288 | LCSC | Connectors:Pin Headers | Connectors | Pin Headers | 2 |  |  | 11532 | 0.0303 | T | DIP | yes |  | HDR-M-2.54_1x2 | 3-644456-2 | 3-644456-2 | gge15,gge16,gge17,gge18,gge23,gge25,gge28,gge29 | 200,100,0,0,0,0,0,0,-118.11 |  |  | Policy |  | White | Copper alloy | - | Tin |  | https://atta.szlcsc.com/upload/public/pdf/source/20180326/C90288_7C19199EB85874EC46E1694096B0EFF6.pdf | Pin Structure:1x2P Pitch:2.54mm Row Spacing:- Circluar Pins/Square Pins:Policy Mounting Type:Direct Insert Number of Rows:Single Row Number of Pins:2P Current Rating (Max):- Voltage Rating (Max):250V Length of Mating Pin:- Insulation Height:- Contact Mate |  |  | - |  |  |  | Extended Part | 间距:2.54mm 1x2P 直插 方针 | - |  |  | Direct Insert |  |  | 2P | Single Row |  |  | -55℃~+105℃
16 | 8 | 2.54-2*7P母 | J4,J5,J6,J7,J8,J9,J10,J11 | HDR-TH_14P-P2.54-V-F-R2-C7-S2.54-1 |  | 2.54-2*7P母 | BOOMELE(博穆精密) | C38844 | LCSC | Connectors:Female Headers | Connectors | Female Headers | 14 |  |  | 13314 | 0.0203 | T | DIP | yes |  | HDR-TH_14P-P2.54-V-F-R2-C7-S2.54-1 | 2.54-2*7P母 | 2.54-2*7P母 | gge19,gge20,gge21,gge22,gge24,gge26,gge27,gge30 | 699.9986,200,0,0,0,0,0,0,-118.11 |  |  |  |  |  | Brass |  | - |  |  | Holes Structure:2x7P Pitch:2.54mm Row Spacing:2.54mm Mounting Type:Straight Number of Rows:双排 Number of Holes:14P Insulation Height:- Contact Material:Brass Contact Plating:- | 2x7P |  | - |  |  |  | Extended Part | 间距:2.54mm 2x7P 直插 |  |  |  | Straight | 14P |  |  | 双排
17 | 3 | 2.2uH | L1,L3,L12 | L0806 |  | MLP2016H2R2MT0S1 | TDK | C695595 | LCSC |  |  |  | 2 |  |  | 1367 | 0.0128 | T | SMT | yes |  | L0806_L2.0-W1.6-H1.0 | 2.2uH | 2.2uH | gge5bde7e8dd4c09d89,ggebbca4cae19c2ea5a,ggec8de5a7556e1ffa9 | 78.74,62.992,0,0,0,0,0,0,0 |  |  |  |  |  |  |  |  |  |  |  |  |  |  |  |  |  | Extended Part |  |  |  |  |  |  |  |  |  |  |  |  | L0806
18 | 4 | 15uH | L5,L6,L7,L8 | IND-SMD_L7.0-W6.6_FXL0630 |  | FXL0630-150-M | cjiang(长江微电) | C177243 | LCSC |  |  |  | 2 |  |  | 188240 | 0.0149 | T | SMT | yes |  | IND-SMD_L7.0-W6.6-H2.8_FXL0630 | 15uH | 15uH | gge3bb86b3d2f15e3ba,gge4e81bca5ffa47ea8,gge39e4265f956a4096,gge79216b8939f04860 | 275.59,259.842,0,0,0,0,-0.001,0,0 |  |  |  |  |  |  |  |  |  |  |  |  |  |  |  |  |  | Extended Part |  |  |  |  |  |  |  |  |  |  |  |  | IND-SMD_L7.0-W6.6_FXL0630
19 | 4 | FC-DA1608HRK-620D | LED1,LED2,LED3,LED4 | LED0603-RD_RED |  | NCD0603R1 | 国星光电 | C84263 | LCSC |  |  |  | 2 |  |  | 946976 | 0.0016 | T | SMT | yes |  | LED0603-RD_RED | FC-DA1608HRK-620D | FC-DA1608HRK-620D | gge95c884c89ba71aa9,gge95c884c89ba71aa9_1,gge301823c31258fce0,ggea91378e7a9d3e748 | 63.7794,31.496,0,0,0,0,0,0,0 |  |  |  |  |  |  |  |  |  |  |  |  |  |  |  |  |  | Extended Part |  |  |  |  |  |  |  |  |  |  |  |  | LED0603-RD_RED
20 | 8 | 2.54-1*1P针 | P3,P4,P5,P6,P7,P8,P9,P10 | HDR-TH_1P-P2.54-V-M |  | 2.54-1*1P针 | BOOMELE(博穆精密) | C81276 | LCSC | Connectors:Pin Headers | Connectors | Pin Headers | 1 |  |  | 38554 | 0.002 | T | DIP | yes |  | HDR2.54-M-LI-1X1P | 2.54-1*1P针 | 2.54-1*1P针 | gge31,gge32,gge33,gge34,gge35,gge36,gge37,gge38 | 100,100,0,0,0,0,0,0,-118.11 |  |  | - |  | Black |  | - | - |  | https://atta.szlcsc.com/upload/public/pdf/source/20221018/3E9408392E35E6F57A28985E5F7BF5C9.pdf | Pin Structure:- Pitch:- Row Spacing:- Circluar Pins/Square Pins:- Mounting Type:Straight Number of Rows:Plugin Number of Pins:1P Current Rating (Max):- Voltage Rating (Max):- Length of Mating Pin:- Insulation Height:- Contact Material: Contact Plating:- C |  |  | - |  |  |  | Extended Part | 直插 | - |  |  | Straight |  |  | 1P | Plugin
21 | 7 | 100kΩ | R1,R14,R15,R20,R25,R46,R47 | R0402 |  | WR04X104JTL | Walsin(华新科) | C384388 | LCSC |  |  |  | 2 |  |  | 1018 | 0.0003 | T | SMT | yes |  |  | 100kΩ | 100kΩ | gge1ff557f9c35e53a5,gge88ab7b809dce9e21,gge2257e3a8fa146bd3,ggeb7906f4c03e1dbc1,ggec2a76682929c20c9,ggedc7981e221d671ca,ggede1ce6eefbc29926 |  |  |  |  |  |  |  |  |  |  |  |  |  |  |  |  |  |  | Extended Part |  |  |  |  |  |  |  |  |  |  |  |  | R0402
22 | 1 | 120kΩ | R2 | R1206 |  | RT1206FRE07120KL | YAGEO(国巨) | C136861 | LCSC |  |  |  | 2 |  |  | 9 | 0.0049 | T | SMT | yes |  |  | 120kΩ | 120kΩ | gge515dd37c8629d106 |  |  |  |  |  |  |  |  |  |  |  |  |  |  |  |  |  |  | Extended Part |  |  |  |  |  |  |  |  |  |  |  |  | R1206
23 | 1 | 1.5kΩ | R3 | R0603 |  | RC0603FR-071K5L | YAGEO(国巨) | C114668 | LCSC |  |  |  | 2 |  |  | 692788 | 0.0009 | T | SMT | yes |  |  | 1.5kΩ | 1.5kΩ | ggefb6b810537c5c9c3 |  |  |  |  |  |  |  |  |  |  |  |  |  |  |  |  |  |  | Extended Part |  |  |  |  |  |  |  |  |  |  |  |  | R0603
24 | 1 | 10kΩ | R4 | R0603 |  | RC0603FR-0710KL | YAGEO(国巨) | C98220 | LCSC |  |  |  | 2 |  |  | 15328786 | 0.0006 | T | SMT | yes |  |  | 10kΩ | 10kΩ | ggeb53b6ee1fb377c1e |  |  |  |  |  |  |  |  |  |  |  |  |  |  |  |  |  |  | Extended Part |  |  |  |  |  |  |  |  |  |  |  |  | R0603
25 | 1 | 360kΩ | R5 | R0603 |  | 0603WAF3603T5E | UNI-ROYAL(厚声) | C23146 | LCSC |  |  |  | 2 |  |  | 114634 | 0.0003 | T | SMT | yes |  |  | 360kΩ | 360kΩ | gge99c6f179c212867f |  |  |  |  |  |  |  |  |  |  |  |  |  |  |  |  |  |  |  |  |  |  |  |  |  |  |  |  |  |  |  | R0603
26 | 2 | 82kΩ | R6,R40 | R0603 |  | 0603WAF8202T5E | UNI-ROYAL(厚声) | C23254 | LCSC |  |  |  | 2 |  |  | 1021959 | 0.0008 | T | SMT | yes |  |  | 82kΩ | 82kΩ | gge6a15420c93bd3eb9,gge26777b238c21f7f0 |  |  |  |  |  |  |  |  |  |  |  |  |  |  |  |  |  |  | Basic Part |  |  |  |  |  |  |  |  |  |  |  |  | R0603
27 | 7 | 500kΩ | R7,R13,R22,R27,R42,R43,R48 | R0805 |  | AR05BTCW5003 | Viking(光颉) | C316218 | LCSC |  |  |  | 2 |  |  | 23719 | 0.0066 | T | SMT | yes |  | R0805_L2.0-W1.3-H0.6 | 500kΩ | 500kΩ | gge4a5c2cfac33b6ad2,gge6e6bec460a85be48,gge8d9dd0c13daad3f1,gge8f74e21236b64c7e,gge21289129f49d8413,ggeb4c328256ad6f98b,ggec166f8ee3885726b | 78.74,51.181,0,0,0,0,-0.001,0,0 |  |  |  |  |  |  |  |  |  |  |  |  |  |  |  |  |  | Extended Part |  |  |  |  |  |  |  |  |  |  |  |  | R0805
28 | 3 | 5.1kΩ | R8,R9,R98 | R0603 |  | 0603WAF5101T5E | UNI-ROYAL(厚声) | C23186 | LCSC |  |  |  | 2 |  |  | 16896108 | 0.0004 | T | SMT | yes |  |  | 5.1kΩ | 5.1kΩ | gge9c050defc149dc1c,gge8116a22fb7d2aff2,ggeaf777afec6fb5b36 |  |  |  |  |  |  |  |  |  |  |  |  |  |  |  |  |  |  | Basic Part |  |  |  |  |  |  |  |  |  |  |  |  | R0603
29 | 1 | 4.7kΩ | R10 | R0402 |  | RC0402FR-074K7L | YAGEO(国巨) | C105871 | LCSC |  |  |  | 2 |  |  | 7079982 | 0.0007 | T | SMT | yes |  |  | 4.7kΩ | 4.7kΩ | gge5394c7579a900b69 |  |  |  |  |  |  |  |  |  |  |  |  |  |  |  |  |  |  | Extended Part |  |  |  |  |  |  |  |  |  |  |  |  | R0402
30 | 2 | 20Ω | R11,R23 | R0603 |  | 0603WAF200JT5E | UNI-ROYAL(厚声) | C22950 | LCSC |  |  |  | 2 |  |  | 2355128 | 0.0005 | T | SMT | yes |  |  | 20Ω | 20Ω | gge2baa2dbb54f213a8,ggef29511cb4ca46f28 |  |  |  |  |  |  |  |  |  |  |  |  |  |  |  |  |  |  | Basic Part |  |  |  |  |  |  |  |  |  |  |  |  | R0603
31 | 4 | 4.7kΩ | R12,R21,R106,R107 | R0603 |  | RC0603FR-074K7L | YAGEO(国巨) | C99782 | LCSC |  |  |  | 2 |  |  | 7615240 | 0.0008 | T | SMT | yes |  |  | 4.7kΩ | 4.7kΩ | gge3b2bf336ee3b5971,gge3b2bf336ee3b5971_1,ggec88eb16c5c2bad1a,ggec88eb16c5c2bad1a_1 |  |  |  |  |  |  |  |  |  |  |  |  |  |  |  |  |  |  | Extended Part |  |  |  |  |  |  |  |  |  |  |  |  | R0603
32 | 1 | 150kΩ | R16 | R0603 |  | RT0603BRD07150KL | YAGEO(国巨) | C326734 | LCSC |  |  |  | 2 |  |  | 25286 | 0.0061 | T | SMT | yes |  |  | 150kΩ | 150kΩ | ggefba45a21568fe06b |  |  |  |  |  |  |  |  |  |  |  |  |  |  |  |  |  |  | Extended Part |  |  |  |  |  |  |  |  |  |  |  |  | R0603
33 | 1 | 300Ω | R34 | R0402 |  | ERA2AEB301X | PANASONIC(松下) | C445586 | LCSC |  |  |  | 2 |  |  | 2352 | 0.0128 | T | SMT | yes |  |  | 300Ω | 300Ω | gge13d8cc08ca8014d7 |  |  |  |  |  |  |  |  |  |  |  |  |  |  |  |  |  |  | Extended Part |  |  |  |  |  |  |  |  |  |  |  |  | R0402
34 | 1 | 100Ω | R99 | R0603 |  | RT0603BRD07100RL | YAGEO(国巨) | C122970 | LCSC |  |  |  | 2 |  |  | 489099 | 0.0049 | T | SMT | yes |  |  | 100Ω | 100Ω | gge549ce357746a2d7c_1 |  |  |  |  |  |  |  |  |  |  |  |  |  |  |  |  |  |  | Extended Part |  |  |  |  |  |  |  |  |  |  |  |  | R0603
35 | 2 | 4.7kΩ | R100,R101 | R0603 | 4.7kΩ | RC0603FR-074K7L | YAGEO(国巨) | C99782 | LCSC | Resistors:Chip Resistor - Surface Mount | Resistors | Chip Resistor - Surface Mount | 2 |  |  | 7615240 | 0.0008 | T | SMT | yes |  | R0603 | RC0603FR-074K7L | 4.7kΩ | gge2,gge3 | 31.8897,63.7794,0,90,0,0,0,0,0 |  |  |  |  |  |  |  |  |  | https://atta.szlcsc.com/upload/public/pdf/source/20180224/C181757_15194369480721363983.pdf | Type:Thick Film Resistors Resistance: Tolerance:±1% Tolerance:±1% Power(Watts): Overload Voltage (Max): Temperature Coefficient:±100ppm/℃ Temperature Coefficient:±100ppm/℃ Operating Temperature Range:-55℃~+155℃ Operating Temperature Range:-55℃~+155℃ |  |  |  |  |  |  | Extended Part | 厚膜电阻 4.7kΩ ±1% 100mW |  |  |  |  |  |  |  |  |  |  | -55℃~+155℃
36 | 1 | 12kΩ | R102 | R0402 | 12kΩ | RC0402FR-0712KL | YAGEO(国巨) | C114760 | LCSC | Resistors:Chip Resistor - Surface Mount | Resistors | Chip Resistor - Surface Mount | 2 |  |  | 1162179 | 0.0006 | T | SMT | yes |  | R0402_L1.0-W0.5-H0.4 | RC0402FR-0712KL | 12kΩ | gge7 | 39.37,19.685,0,0,0,0,0,0,0 |  |  |  |  |  |  |  |  |  | https://atta.szlcsc.com/upload/public/pdf/source/20180821/C275644_0D56F95EFF785E7D9A1FEF436B37DA78.pdf | Type:Thick Film Resistors Resistance: Tolerance:±1% Tolerance:±1% Power(Watts): Overload Voltage (Max): Temperature Coefficient:±100ppm/℃ Temperature Coefficient:±100ppm/℃ Operating Temperature Range:-55℃~+155℃ Operating Temperature Range:-55℃~+155℃ |  |  |  |  |  |  | Extended Part | 厚膜电阻 12kΩ ±1% 62.5mW |  |  |  |  |  |  |  |  |  |  | -55℃~+155℃
37 | 1 | 500Ω | R103 | R0805 | 500Ω | ARG05BTC5000 | Viking(光颉) | C2828711 | LCSC | Resistors:Chip Resistor - Surface Mount | Resistors | Chip Resistor - Surface Mount | 2 |  |  | 54023 | 0.0053 | T | SMT | yes |  | R0805_L2.0-W1.3-H0.6 | ARG05BTC5000 | 500Ω | gge8 | 78.74,51.181,0,0,0,0,0,-0.0005,0 |  |  |  |  |  |  |  |  |  | https://atta.szlcsc.com/upload/public/pdf/source/20211009/C2828883_CAE7D170B8B230FC4A048BDC7B3A81FC.pdf | Type:Thin Film Resistor Resistance: Tolerance:±0.1% Tolerance:±0.1% Power(Watts): Overload Voltage (Max): Temperature Coefficient:±25ppm/℃ Temperature Coefficient:±25ppm/℃ Operating Temperature Range:-55℃~+155℃ Operating Temperature Range:-55℃~+155℃ |  |  |  |  |  |  | Extended Part | 薄膜电阻 500Ω ±0.1% 125mW |  |  |  |  |  |  |  |  |  |  | -55℃~+155℃
38 | 2 | 13.3kΩ | R104,R105 | R0603 | 13.3kΩ | RT0603BRE0713K3L | YAGEO(国巨) | C861663 | LCSC | Resistors:Chip Resistor - Surface Mount | Resistors | Chip Resistor - Surface Mount | 2 |  |  | 12015 | 0.004 | T | SMT | yes |  | R0603 | RT0603BRE0713K3L | 13.3kΩ | gge9,gge10 | 31.8897,63.7794,0,90,0,0,0,0,0 |  |  |  |  |  |  |  |  |  | https://atta.szlcsc.com/upload/public/pdf/source/20200610/C326738_5639A9F1B6EB6E4AE2197577D3456E7F.pdf | Type:Thin Film Resistor Resistance: Tolerance:±0.1% Tolerance:±0.1% Power(Watts): Temperature Coefficient:±50ppm/℃ Temperature Coefficient:±50ppm/℃ Operating Temperature Range:-55℃~+155℃ Operating Temperature Range:-55℃~+155℃ |  |  |  |  |  |  | Extended Part | 薄膜电阻 13.3kΩ ±0.1% 100mW |  |  |  |  |  |  |  |  |  |  | -55℃~+155℃
39 | 2 | 100Ω | R108,R109 | R0603 | 100Ω | FRC0603J101 TS | FOJAN(富捷) | C2907089 | LCSC | Resistors:Chip Resistor - Surface Mount | Resistors | Chip Resistor - Surface Mount | 2 |  |  | 3965600 | 0.0004 | T | SMT | yes |  | R0603 | FRC0603J101 TS | 100Ω | gge13,gge14 | 31.8897,63.7794,0,90,0,0,0,0,0 |  |  |  |  |  |  |  |  |  | https://atta.szlcsc.com/upload/public/pdf/source/20211221/925EC7D7225764EE0046F22065062C87.pdf | Type:Thick Film Resistors Resistance: Tolerance:±5% Tolerance:±5% Power(Watts): Overload Voltage (Max): Temperature Coefficient:±100ppm/℃ Temperature Coefficient:±100ppm/℃ Operating Temperature Range:-55℃~+155℃ Operating Temperature Range:-55℃~+155℃ |  |  |  |  |  |  | Extended Part | 100Ω ±5% 100mW 厚膜电阻 |  |  |  |  |  |  |  |  |  |  | -55℃~+155℃
40 | 1 | 255kΩ | R110 | R0805 | 255kΩ | CR0805F255KP05Z | EVER OHMS(天二科技) | C245284 | LCSC | Resistors:Chip Resistor - Surface Mount | Resistors | Chip Resistor - Surface Mount | 2 |  |  | 527 | 0.0008 | T | SMT | yes |  | R0805_L2.0-W1.3-H0.6 | CR0805F255KP05Z | 255kΩ | gge12 | 78.74,51.181,0,0,0,0,0,-0.0005,0 |  |  |  |  |  |  |  |  |  | https://atta.szlcsc.com/upload/public/pdf/source/20190724/C171430_9E147A274D2811BD276FBB11C8CE6534.pdf | Type:Thick Film Resistors Resistance: Tolerance:±1% Tolerance:±1% Power(Watts): Overload Voltage (Max): Temperature Coefficient:±100ppm/℃ Temperature Coefficient:±100ppm/℃ Operating Temperature Range:-55℃~+155℃ Operating Temperature Range:-55℃~+155℃ |  |  |  |  |  |  | Extended Part | 厚膜电阻 255kΩ ±1% 125mW |  |  |  |  |  |  |  |  |  |  | -55℃~+155℃
41 | 1 | PS-1049SVD-4PN | SW1 | SW-SMD_4P-L10.0-W10.0-P6.00-LS12.2 |  | PS-1049SVD-4PN | G-Switch(品赞) | C5446862 | LCSC |  |  |  | 4 |  |  | 733 | 0.093 | T | SMT | yes |  |  | PS-1049SVD-4PN | PS-1049SVD-4PN | ggebfa176616e5aa3a6 |  |  |  |  |  |  |  |  |  |  |  |  |  |  |  |  |  |  | Extended Part |  |  |  |  |  |  |  |  |  |  |  |  | SW-SMD_4P-L10.0-W10.0-P6.00-LS12.2
42 | 1 | LFE5U-25F-6BG256C | U1 | CABGA-256_L14.0-W14.0-R16-C16-P0.80-TL |  | LFE5U-25F-6BG256C | LATTICE(莱迪思) | C1521614 | LCSC |  |  |  | 256 |  |  | 284 | 1.9317 | T | SMT | yes |  | CABGA-256_L14.0-W14.0-R16-C16-P0.80-TL | LFE5U-25F-6BG256C | LFE5U-25F-6BG256C | ggeebd2f7484a28e03c | 551.18,551.18,0,0,0,0,-0.001,0.001,0 |  |  |  |  |  |  |  |  |  |  |  |  |  |  |  |  |  |  |  |  |  |  |  |  |  |  |  |  |  |  | CABGA-256_L14.0-W14.0-R16-C16-P0.80-TL
43 | 3 | TLV62569DRLR | U2,U4,U5 | SOT-563_L1.6-W1.2-P0.50-LS1.6-BL |  | TLV62569DRLR | TI(德州仪器) | C163217 | LCSC |  |  |  | 6 |  |  | 2865 | 0.0395 | T | SMT | yes |  | SOT-563-6P_L1.6-W1.2-H0.6-LS1.6-P0.50 | TLV62569DRLR | TLV62569DRLR | gge6f0b62ab1576051b,gge8ff1a16a12ff2e98,gge30fc8736db45bab3 | 62.992,62.992,0,90,0,0,-0.004,0.006,0 |  |  |  |  |  |  |  |  |  |  |  |  |  |  |  |  |  | Extended Part |  |  |  |  |  |  |  |  |  |  |  |  | SOT-563_L1.6-W1.2-P0.50-LS1.6-BL
44 | 1 | IS61WV25616BLL-10BLI | U8 | TFBGA-48_L8.0-W6.0-R8-C6-P0.75-TL |  | IS61WV25616BLL-10BLI | ISSI(Integrated Silicon Solution) | C427369 | LCSC |  |  |  | 48 |  |  | 107 | 1.1797 | T | SMT | yes | Yes | TFBGA-48_L8.0-W6.0-H1.1-R8-C6-P0.75-TL | IS61WV25616BLL-10BLI | IS61WV25616BLL-10BLI | gge98c6345988cabc98 | 236.22,314.96,0,0,0,0,0,0.001,0 |  |  |  |  |  |  |  |  |  |  |  |  |  |  |  |  |  |  |  |  |  |  |  |  |  |  |  |  |  |  | TFBGA-48_L8.0-W6.0-R8-C6-P0.75-TL
45 | 4 | TPS54202DDCR | U13,U14,U15,U30 | SOT-23-6_L2.9-W1.6-P0.95-LS2.8-BL |  | TPS54202DDCR | TI(德州仪器) | C191884 | LCSC |  |  |  | 6 |  |  | 95421 | 0.0353 | T | SMT | yes |  | SOT-23-6_L2.9-W1.6-H1.5-LS2.8-P0.95 | TPS54202DDCR | TPS54202DDCR | gge80ddfc3d88bade87,ggeb02051a06d8e18c0,ggeb4202538ec2d6a66,ggec9b6d477dd14a3e5 | 110.236,113.364,0,90,0,0,0.001,0.001,0 |  |  |  |  |  |  |  |  |  |  |  |  |  |  |  |  |  | Extended Part |  |  |  |  |  |  |  |  |  |  |  |  | SOT-23-6_L2.9-W1.6-P0.95-LS2.8-BL
46 | 2 | 10.5kΩ | U16,U17 | R0603 |  | PTFR0603B10K5N9 | RESI(开步睿思) | C2692889 | LCSC |  |  |  | 2 |  |  | 5569 | 0.0266 | T | SMT | yes |  |  | 10.5kΩ | 10.5kΩ | gge28c2fbdf068b5dba,gge514b7f1273493386 |  |  |  |  |  |  |  |  |  |  |  |  |  |  |  |  |  |  | Extended Part |  |  |  |  |  |  |  |  |  |  |  |  | R0603
47 | 1 | 200kΩ | U18 | R0603 |  | RT0603BRD07200KL | YAGEO(国巨) | C728585 | LCSC |  |  |  | 2 |  |  | 293919 | 0.0084 | T | SMT | yes |  |  | 200kΩ | 200kΩ | ggefb5cee04e587f9f6 |  |  |  |  |  |  |  |  |  |  |  |  |  |  |  |  |  |  | Extended Part |  |  |  |  |  |  |  |  |  |  |  |  | R0603
48 | 1 | FM25V02A-GTR | U20 | SOIC-8_L5.0-W4.0-P1.27-LS6.0-BL |  | FM25V02A-GTR | CYPRESS(赛普拉斯) | C66029 | LCSC |  |  |  | 8 |  |  | 21819 | 0.4951 | T | SMT | yes |  | SOIC-8_L4.9-W3.9-H1.7-LS6.0-P1.27 | FM25V02A-GTR | FM25V02A-GTR | gge9307349f91ba8344 | 189.751,236.22,0,0,0,0,0,0,0 |  |  |  |  |  |  |  |  |  |  |  |  |  |  |  |  |  | Extended Part |  |  |  |  |  |  |  |  |  |  |  |  | SOIC-8_L5.0-W4.0-P1.27-LS6.0-BL
49 | 1 | 27MHz | U25 | CRYSTAL-SMD_4P-L2.5-W2.0-BL |  | 2NM27000C33YC | SJK(晶科鑫) | C668764 | LCSC |  |  |  | 4 |  |  | 3 | 0.1618 | T | SMT | yes |  | CRYSTAL-SMD_4P-L2.5-W2.0-BL | 27MHz | 27MHz | ggecde2f60252afb938 | 98.425,78.74,0,0,0,0,0.001,-0.001,0 |  |  |  |  |  |  |  |  |  |  |  |  |  |  |  |  |  |  |  |  |  |  |  |  |  |  |  |  |  |  | CRYSTAL-SMD_4P-L2.5-W2.0-BL
50 | 1 | SN74CB3T3245PWR | U35 | TSSOP-20_L6.5-W4.4-P0.65-LS6.4-BL |  | SN74CB3T3245PWR | TI(德州仪器) | C15298 | LCSC |  |  |  | 20 |  |  | 768 | 0.306 | T | SMT | yes |  | TSSOP-20_L6.5-W4.4-H1.0-LS6.4-P0.65 | SN74CB3T3245PWR | SN74CB3T3245PWR | gge2d7d7174f0c076fc | 251.969,255.906,0,90,0,0,0.001,0,0 |  |  |  |  |  |  |  |  |  |  |  |  |  |  |  |  |  | Extended Part |  |  |  |  |  |  |  |  |  |  |  |  | TSSOP-20_L6.5-W4.4-P0.65-LS6.4-BL
51 | 1 | MS5351M | U36 | MSOP-10_L3.0-W3.0-P0.50-LS5.0-BL |  | MS5351M | 杭州瑞盟 | C1509083 | LCSC | Clock/Timing:Clock Generators, PLLs, Frequency Synthesizers | Clock/Timing | Clock Generators, PLLs, Frequency Synthesizers | 10 |  |  | 1142 | 0.1344 | T | SMT | yes |  | MSOP-10_L3.0-W3.0-H1.1-LS5.0-P0.50 | MS5351M | MS5351M | gge1 | 118.11,196.85,0,0,0,0,0,0,0 |  |  |  |  |  |  |  |  |  | https://atta.szlcsc.com/upload/public/pdf/source/20240418/7555041AE934D685742A157FDD128132.pdf | Interface:I2C Output Frequency (Max):200MHz Supply Voltage:2.7V~3.3V Supply Voltage:2.7V~3.3V Number of Outputs:3 Input Low Voltage:- Input Low Voltage:- Intput High Voltage:- Intput High Voltage:- Output Low Voltage:600mV Output Low Voltage:600mV Output |  | - |  | I2C |  | - | Extended Part | MS5351M |  |  |  |  |  | 3 |  |  | -55℃~+150℃ |  |  |  | 200MHz | 2.7V
52 | 1 | FT232HQ-REEL | U37 | QFN-48_L8.0-W8.0-P0.50-BL-EP |  | FT232HQ-REEL | FTDI(飞特帝亚) | C82158 | LCSC | Interface:USB Converters | Interface | USB Converters | 49 |  |  | 28 | 4.0289 | T | SMT | yes |  | QFN-48_L8.0-W8.0-H0.9-P0.50 | FT232HQ-REEL | FT232HQ-REEL | gge6 | 314.961,314.961,0,90,0,0,0,0,0 | USB转UART；USB转FIFO |  |  |  |  |  |  |  |  | https://atta.szlcsc.com/upload/public/pdf/source/20180207/C82158_15179953669851359485.pdf | Applications Function:USB转UART；USB转FIFO Protocol:UART；FIFO Supply Voltage:2.97V~3.63V；1.62V~1.98V Supply Voltage:2.97V~3.63V；1.62V~1.98V Operating Temperature:-40℃~+85℃ Operating Temperature:-40℃~+85℃ |  |  |  |  |  |  | Extended Part | FT232HQ-REEL |  |  |  |  |  |  |  |  |  | -40℃~+85℃
53 | 1 | W25Q256JVEIQ | U39 | WSON-8_L8.0-W6.10-P1.27-BL-EP |  | W25Q256JVEIQ | WINBOND(华邦) | C97522 | LCSC | Memory:NOR FLASH | Memory | NOR FLASH | 9 |  |  | 966 | 0.6682 | T | SMT | yes |  | WSON-8_L8.0-W6.0-H0.78-P1.27 | W25Q256JVEIQ_C97522 | W25Q256JVEIQ | gge11 | 315.7474,236.22,0,90,0,0,0,0,0 |  | 120ms@(32KB) |  | 133MHz |  |  |  |  | 20 years | https://atta.szlcsc.com/upload/public/pdf/source/20190529/C97522_47AE152D0BB11FB4C8509E398C0AD2EA.pdf | Interface Type:SPI Memory Size:256Mbit Clock Frequency (fc):133MHz Supply Voltage:2.7V~3.6V Supply Voltage:2.7V~3.6V Page Programming Time (Tpp):700us Block Erase Time (tBE):120ms@(32KB) Data Retention - TDR (Year):20 years Operating Temperature:-40℃~+85℃ |  |  |  |  | SPI |  | Extended Part | W25Q256JVEIQ |  |  | 256Mbit |  |  |  |  |  |  | -40℃~+85℃
54 | 1 | TYPE-C-31-E-07 | USB1 | USB-C-SMD_TYPE-C-31-E-07 |  | TYPE-C-31-E-07 | 韩国韩荣 | C970566 | LCSC |  |  |  | 10 |  |  | 216 | 0.1814 | T | DIP | yes |  | USB-C-SMD_TYPE-C-31-E-07 | TYPE-C-31-E-07 | TYPE-C-31-E-07 | ggea906ddb21ccbe433 | 395.2748,309.055,0,0,0,0,0.001,-106.295,-31.496 |  |  |  |  |  |  |  |  |  |  |  |  |  |  |  |  |  | Extended Part |  |  |  |  |  |  |  |  |  |  |  |  | USB-C-SMD_TYPE-C-31-E-07
55 | 1 | TYPE-C-31-M-12 | USBC1 | USB-C_SMD-TYPE-C-31-M-12 |  | TYPE-C-31-M-12 | 韩国韩荣 | C165948 | LCSC |  |  |  | 20 |  |  | 310231 | 0.0277 | T | DIP | yes |  | USB-C_SMD-TYPE-C-31-M-12 | TYPE-C-31-M-12 | TYPE-C-31-M-12 | ggeaaac37e8ea9a4bda | 351.9678,311.023,0,180,0,0,0.001,-45.041,-39.37 |  |  |  |  |  |  |  |  |  |  |  |  |  |  |  |  |  | Extended Part |  |  |  |  |  |  |  |  |  |  |  |  | USB-C_SMD-TYPE-C-31-M-12
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

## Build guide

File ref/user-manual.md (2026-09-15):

# Odin user manual

Odin is an FPGA board for building the thing you meant to build.

One USB-C cable powers it and programs it. Four PSRAM chips give the FPGA
8 MB of working memory. Ten extension ports carry signals and useful power.
Two SFP sockets carry the links that ordinary FPGA pins cannot.

This manual is for using the board. If you are designing an extension, read
`ref/extension-ux.md` after this.

## The board in one picture

```text
                         +-----------------------+
 USB-C  ---------------->| BOARD CONTROLLER      |
 power + programming     | power, recovery,      |
                         | FPGA programming       |
                         +-----------+-----------+
                                     |
                    +----------------v----------------+
                    | XC7A100T FPGA                   |
                    |                                |
       8 MB PSRAM <---> four separate memory links   |
                    |                                |
      slots A-D  <----> 48 direct pins, one voltage  |
      slots E-H  <----> 48 direct pins, one voltage  |
      5V BUS 0/1 <----> two complete 8-bit buses     |
                    |                                |
      SFP 0 and 1 <----> fast serial lanes           |
                    +--------------------------------+
```

## Start here

1. Leave all extensions unplugged.
2. Set both **A–D PIN VOLTAGE** and **E–H PIN VOLTAGE** to **3.3 V**.
3. Set each **SLOT _ POWER** selector to **3.3 V**, or leave its jumper off.
4. Plug USB-C into Odin.
5. Wait for the board controller to start.
6. Plug in one simple extension and test it before adding the next.

Use a USB-PD charger when the board carries displays, speakers, motors or SFP
modules. A computer port is fine for programming and light work, but it may
not have enough power for everything at once.

Odin never asks USB-C for more than 9 V.

### Optional power input

`OPTIONAL POWER IN` is not required for normal use. It is a second way to
power Odin from a regulated bench supply when USB-C cannot provide enough
power. Connect **9–14 V** to the pin marked `+` and supply ground to `GND`.
USB-C may remain connected; Odin uses the higher source. Never exceed 14 V.

## The extension idea, from zero

Odin has eight shield sections arranged on opposite sides of the 100 x 100 mm
board. Each section has a 16-position signal block and a separate 8-pin power
row. Two additional ports are complete 5 V-compatible eight-bit buses.

```text
one direct slot

       8 columns
     +-----------------+
signal| o o o o o o o o |
signal| o o o o o o o o |
power | o o o o o o o o |
     +-----------------+
       24 pins total
```

Twelve pins are signals. Four grounds complete the signal block. Power gets
its own unmistakable row with four supplies and four grounds.

### Where are the I/Os?

Here. `IO` means a signal you can use as an input or an output.

```text
              1     2     3     4     5     6     7     8
signal row 1  IO0   IO2   IO4   IO6   IO8   IO10  GND   GND
signal row 2  IO1   IO3   IO5   IO7   IO9   IO11  GND   GND
power row     GND   PIN V GND   3V3   GND   5V    GND   SLOT PWR
```

Use `IO0..IO11` as ordinary independent signals. Some adjacent pins can also
carry a differential signal when an extension needs that. The ball map lists
those pairings; normal users do not need to learn them.

### What do 16, 32 and 64 mean?

They mean the width used on **each side** of the base board. An extension is a
bridge, not a board hanging from one edge.

```text
                 one edge of Odin             opposite edge

16 shield             [ A ]========================[ E ]
                    16 signal positions          16 signal positions
                       + power row                  + power row

32 shield         [ A ][ B ]==================[ E ][ F ]
                       32 pins     extension         32 pins

64 shield     [ A ][ B ][ C ][ D ]========[ E ][ F ][ G ][ H ]
                       64 pins     extension         64 pins
```

A 16 gets 12 I/O on each side: 24 total. A 32 gets 48 total. A 64 spans both
complete FPGA banks and gets 96 direct I/O.

The schematic names four 16-pin sections on each edge. Those are electrical
zones, not a demand for four separate plastic connectors. Odin uses the
physical arrangement: **two continuous 2x16 stack-through signal headers and
two parallel 1x16 stack-through power headers on each edge**. A 16 shield uses
half of one pair, a 32 uses one whole pair, and a 64 uses both. The guide pins
and outlines must make those partial positions unambiguous.

The bridge gives the extension support at both ends, almost the full board
area above Odin, and matching connectors on top so another shield can stack.
The extension PCB and its fitted headers determine its size; there is no size
switch.

### Where are the slots on Odin?

The required arrangement is:

```text
                    100 mm
       +----------------------------------+
       | [ A ][ B ][ C ][ D ]            |  bank 15
       |                                  |
       |             ODIN                 |  shield bridges
       |                                  |  across this space
       | [ E ][ F ][ G ][ H ]            |  bank 34
       +----------------------------------+

       [ L ]  separate 5 V-safe legacy connector
```

Matching pairs are A/E, B/F, C/G and D/H. Placement must put each pair directly
opposite its partner. All eight connectors need the same pitch, orientation
and distance from the board edges.

**Their exact coordinates do not exist yet because placement has not been
done.** Until those coordinates and a real extension outline are drawn and
measured together, the bridge and stacking fit remain an intention, not a
proven feature.

Slots A-D always share one signal voltage. Slots E-H share another. Changing
a PIN VOLTAGE jumper changes the voltage of the whole group, not one slot.

| Shield | Sections underneath | Physical pins per side | Usable I/O |
|---|---:|---:|---:|
| 16 | A+E, B+F, C+G or D+H | 24 | 24 |
| 32 | Two matching pairs | 48 | 48 |
| 64 | A-D and E-H | 96 | 96 |

A shield reaches both FPGA banks. The A-D side shares one PIN VOLTAGE setting;
the E-H side shares the other. A 64 owns both complete groups. A smaller shield
must share each side's voltage with anything using the unused connector pairs.

### Stacking

Every shield needs female sockets underneath and matching male pins on top.
The signals pass vertically through the board so another shield can plug in.

```text
          second shield
       ===================
          stacking pins
       o o o o o o o o o o
          first shield
       ===================
          female sockets
       | | | | | | | | | |
             Odin
       ===================
```

Stacking does not create more FPGA pins or more power. Stacked shields share
the same wires, voltage groups and current budget. They must not drive the
same signal at the same time.

The guide pins, stacking headers, component height and board-to-board spacing
must be designed as one mechanical system. A guide that works for one board
but blocks the next board is not a working guide.

## One direct slot

```text
             column  1     2     3     4     5     6     7     8
 signal row 1        IO0   IO2   IO4   IO6   IO8   IO10  GND   GND
 signal row 2        IO1   IO3   IO5   IO7   IO9   IO11  GND   GND
 power row           GND   PIN V GND   3V3   GND   5V    GND   SLOT PWR
```

The separate post beside the header is the **guide pin**. The extension has a
matching hole. If it does not drop onto the header and guide pin without
force, it is reversed or shifted.

Never shift the extension sideways by one column. Check the guide pin before power.

## What the four power pins mean

| Pin | Meaning |
|---|---|
| `PIN V` | The signal voltage for that FPGA group: 3.3, 2.5 or 1.8 V |
| `+5V` | Fixed supply for 5 V parts |
| `+3V3` | Fixed supply for ordinary 3.3 V parts |
| `SEL PWR` | Selected beside that slot: 12 V, 5 V or 3.3 V |

`PIN V` is both a power output and the voltage used by the FPGA pins. The
schematic calls it `VCCIO`; the board says PIN VOLTAGE because that says what
the selector changes.

The 1.0 V FPGA core rail never reaches a connector.

### Power is shared

The small fuse beside each slot is fault protection. It is not a promise that
every slot may draw the number printed on the fuse at the same time.

Odin also separates connector power from its own power. One protected switch
feeds each shared extension bus: 5 V, 3.3 V, the two PIN VOLTAGE groups, and
selected 12 V power. A short or power applied backward can shut down the affected shared bus
without shutting down the FPGA, memories or board controller. All extensions on
that bus lose power together. Unplug the bad extension before retrying.

This protects power pins only. It does not make the ordinary FPGA signals
5 V compatible. Use 5V BUS 0 or 5V BUS 1 for 5 V signals.

The selectable 12 V rail is the tightest. Treat **about 0.5 A across the whole board**
as the present design target, pending final component qualification. One LCD
backlight is sensible. Nine motors are not.

The final production manual must take its exact limits from the released
power-budget report. Do not copy preliminary figures from an old schematic.

## Which slot should I use?

```text
Is the signal 5 V?
  yes -> use 5V BUS 0 or 5V BUS 1
  no  -> continue

Does each pin need its own direction, or is it fast/LVDS?
  yes -> use A-H
  no  -> either works

Does it require 1.8 V or 2.5 V?
  yes -> give it a whole bank: A-D or E-H
  no  -> leave PIN VOLTAGE at 3.3 V
```

### The two 5V buses are different

5V BUS 0 and 5V BUS 1 protect the FPGA from 5 V signals. Each is one complete
eight-bit bus with one shared direction control. All eight pins on one bus
turn around together. Each bus also has an independent active-low enable,
`BUS5V0_OE_N` or `BUS5V1_OE_N`, pulled up to +3V3 through 10k. The translators
remain disabled during FPGA configuration. Use them for old 5 V buses,
parallel displays and similar parts.
Do not use it for I2C, one-wire parts, or a mixture of inputs and outputs that
must change direction independently.

Slots A-H connect directly to FPGA pins. They are flexible and fast, but they
are **not 5 V tolerant**.

## Example 1: a 3.3 V SPI sensor

Use one direct slot, for example A.

```text
Sensor VCC   -> +3V3
Sensor GND   -> GND
Sensor SCK   -> any signal pin
Sensor MOSI  -> any signal pin
Sensor MISO  -> any signal pin
Sensor CS    -> any signal pin

A-D PIN VOLTAGE -> 3.3 V
SLOT A POWER    -> no jumper needed
```

Six signal pins remain free. The sensor receives clean 3.3 V even if another
bank uses a different voltage.

## Example 2: an old 5 V parallel peripheral

Use either 5V BUS.

```text
Peripheral VCC       -> +5V
Peripheral GND       -> GND
Data D0-D7            -> 5V BUS 0 I/O 0-7
Read/write or status  -> 5V BUS 1 I/O 0 (when 5 V compatibility is required)
```

In the FPGA design, keep `BUS5V0_OE_N` high while setting direction and
initial data. `BUS5V0_DIR=1` sends FPGA data to the connector; `DIR=0` receives
connector data (release the FPGA data outputs first). Drive `OE_N` low only
when ready. Raise it before changing direction and allow the translator's
disable/enable timing when handing the bus over. Initialize both enables
high in the bitstream's reset logic. BUS 1 has independent DIR and OE_N
controls and follows the same sequence. See the
[SN74LXC8T245 datasheet](https://www.ti.com/lit/ds/symlink/sn74lxc8t245.pdf).

Do not connect a 5 V signal to A-H just because its power comes from their
5 V pin. Power voltage and signal voltage are separate things.

## Example 3: a small handheld

A 64 shield bridges A-D to E-H and gets 96 direct 3.3 V signals. This
example only needs thirty-seven:

```text
16  LCD colour bits
 4  pixel clock and display timing
 8  buttons
 2  display reset and backlight control
 3  digital audio
 4  microSD SPI
---
37  used
59  spare
```

Use:

```text
PIN V   3.3 V   FPGA signal level
+3V3            display, SD card and audio logic
+5V             audio amplifier
SEL PWR 12 V    backlight driver, if required
```

The framebuffer belongs in PSRAM. A 320 x 240 RGB565 frame is about 150 KB;
the board has 8 MB.

## Memory without ceremony

Odin has four 2 MB PSRAM chips. Each has its own connection to the FPGA.

```text
PSRAM 0  video or DMA
PSRAM 1  CPU memory
PSRAM 2  CPU memory
PSRAM 3  scratch, capture or another CPU
```

That split is only an example. HDL decides what each chip does. The hardware
does not force them to share one busy connection.

One chip can move roughly 50 MB/s at a 100 MHz quad-SPI clock. Four used
together can approach 200 MB/s. VGA RGB565 fits on one. 1080p60 RGB565 does
not fit on all four. That is the honest ceiling.

## Programming and recovery

The board controller has its own startup memory. The FPGA has another. They
are not the same thing.

| Storage | Holds |
|---|---|
| Controller memory | Software that starts and manages the board |
| FPGA startup memory | FPGA images and fabric software |

A new blank board enters its built-in USB loader. Copy the board-controller firmware
to the USB drive that appears.

If a later board-controller update goes wrong:

1. Unplug power.
2. Hold **CTRL BOOT**.
3. Plug USB-C back in.
4. Release the button when the USB drive appears.
5. Copy known-good board-controller firmware to it.

The recovery loader is inside the chip. A broken flash image cannot erase it.

### Hardware identity and compatible firmware

This design is **Odin hardware `0.1.0-proto.1`**. The hardware version and exact
programmable-device identities are printed on the PCB, so rewriting or replacing
either flash chip cannot erase the board's identity.

The assembled board prints the exact fitted programmable-device part numbers
beside the devices on the top silkscreen. For this revision they are
`XC7A100T-2FGG676I` and `RP2350B`. Do not identify a board only as “Artix-7” or
“RP-class”: package, density and controller variant determine the usable
toolchain and firmware.

Board-controller firmware must read the FPGA JTAG IDCODE before erasing or
programming FPGA storage, select an explicitly supported FPGA profile, and
refuse an unknown IDCODE with a useful diagnostic. It must also report its own
build target and supported FPGA profiles over USB.

JTAG identifies the FPGA die/device family and density, but does not reliably
encode the complete orderable suffix such as package, speed grade and
temperature grade. Therefore autodetection is a compatibility guard; the
silkscreen, schematic and manufacturing BOM remain the authority for the exact
fitted part.

Odin uses Semantic Versioning independently for hardware, board-controller
firmware and FPGA gateware:

- **MAJOR:** an existing bitstream, firmware, extension or connector contract
  becomes incompatible;
- **MINOR:** a backward-compatible hardware capability is added;
- **PATCH:** layout or BOM corrections leave behavior and interfaces unchanged;
- a pre-release suffix identifies each prototype fabrication. No two different
  fabrications may reuse the same complete hardware version.

The first proven public hardware release will be `1.0.0`. Firmware and gateware
releases must carry a manifest declaring their supported hardware-version range,
exact FPGA build target, pin-map hash and toolchain version.

### External JTAG

Normal use needs no external programmer. J2 exists for low-level FPGA debug.
**J2 is a custom 2.54mm 2×5 header, incompatible with direct Xilinx 2mm 2×7
or Digilent 1×6 cables:** use an adapter; pins 1/3/5/7/9 are +3V3 reference,
TMS, TCK, TDO and TDI, and all even pins are GND. Pin 1 is marked `1` on
silkscreen; +3V3 is the adapter voltage reference, not an external power input.
Fit **EXT JTAG** (`J52`) before attaching an external programmer.
That disconnects the board controller from the same four wires. Remove the
jumper for normal board-controlled programming.

## Fast links

Two SFP sockets are fitted by default. They can accept suitable copper,
fibre or direct-attach modules.

```text
SFP 0 -> FPGA fast lane 0
SFP 1 -> FPGA fast lane 1
```

The FPGA provides the physical serial lane. Your FPGA design still needs the
protocol logic. Plugging in a copper Ethernet module does not create an
Ethernet controller by itself.

The FPGA lanes top out around 6.6 Gb/s, while the fitted Amphenol
U77A11133001 cage is listed at 2.5 Gb/s. The complete port is unqualified
above that cage rating. Use them for 1 Gb/s or suitable 2.5 Gb/s
links, not 10 Gb/s modules.

There are exactly two SFP ports. The FPGA's other fast lanes are unused.

An I²C switch gives each module a separate identity channel, so both can
remain powered while supervisor firmware reads their EEPROMs at 0x50.
Firmware must select only one channel at a time; see the
[management-bus contract](sfp-i2c.md). Module power remains shared: a power
shutdown stops both ports. The identity console feature still requires
supervisor firmware.

## If something goes wrong

### The board resets when an extension starts

The power source is probably too small, or the extension has too much startup
current.

- Remove the extension and try again.
- Use a USB-PD charger instead of a computer port.
- Check the extension for a short.
- Start with SLOT POWER unselected or set to 3.3 V.

### An extension does nothing

- Check the guide pin and header alignment.
- Check PIN VOLTAGE for the whole group.
- Check its SLOT POWER selector.
- Remember that each 5V BUS uses one shared direction control.
- Remember that a blown or tripped branch fuse is not fixed by HDL.

### The FPGA will not program

- Remove every extension.
- Restore both PIN VOLTAGE groups to 3.3 V.
- Remove `EXT JTAG` (`J52`) for normal programming.
- Recover the controller with **CTRL BOOT**.

### A rail reads low

Disconnect extensions one at a time. A bad extension should be treated as the
fault until it works alone on a current-limited bench supply.

## Rules worth remembering

1. Check the guide pin before power.
2. Slots in one group share one PIN VOLTAGE setting.
3. Only 5V BUS 0 and 5V BUS 1 accept 5 V signals.
4. Each 5V BUS is a complete eight-bit bus with shared direction.
5. The four connector rails share the board's total power.
6. Never feed power into an Odin power-output pin.
7. Start a new extension at 3.3 V with SLOT POWER unselected.
8. Test one extension before stacking several.
9. Use a PD charger for power-heavy projects.
10. When in doubt, unplug power first.

## Before this manual becomes a release manual

The circuit is still being qualified. Replace this section with final ratings
before shipping hardware:

- Exact shared and per-slot current limits
- Extension-rail shutdown and fault behavior
- Final connector positions and orientation drawing
- Board-controller status messages and firmware-loading names
- Qualified SFP module types
- Board revision and matching schematic commit

Until those are fixed, this is the user contract for the design—not permission
to fabricate an unchecked revision.

## FPGA DONE indicator

The green **FPGA DONE** LED lights when the FPGA releases DONE high after
configuration. A BSS138 buffer supplies its current independently of the
configuration pin, and an external 4.7k pull-up defines the high level.
Reference bitstreams do **not** need `DriveDone=Yes` for this indicator.
The supervisor reads the same DONE signal through its existing input path.

A lit LED indicates DONE is high; it does not prove that the user application
is running correctly. Ignore the indicator while supplies are ramping.

## Controller heartbeat and user indicators

Three additional green indicators are fitted: **CTRL HB**, **USER 1** and
**USER 2**. They default off. Supervisor firmware can blink CTRL HB from its
main service loop and expose USER 1/2 to applications; that firmware remains
to be implemented. A frozen heartbeat indicates lost progress or an I2C-bus
fault, while a steady lit LED alone does not establish health.

The supervisor can also read the core regulator's **CORE_1V0_GOOD** through
the same expander, alongside its existing MON_1V0 voltage measurement.
See [status indicators and firmware rules](status-leds.md).

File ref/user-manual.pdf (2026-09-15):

# Odin user manual

Odin is an FPGA board for building the thing you meant to build.

One USB-C cable powers it and programs it. Four PSRAM chips give the FPGA 8 MB of working memory. Nine extension slots carry signals and useful power. Two SFP sockets carry the links that ordinary FPGA pins cannot.

This manual is for using the board. If you are designing an extension, read ref/extension-ux.md after this.

## The board in one picture

+-----------------------+
USB-C ---------------->| supervisor | |
power + programming | | power, recovery, | |
| FPGA programming | |
+-----------+-----------+
+----------------v----------------+
| XC7A50T FPGA | |
8 MB PSRAM <---> four separate memory links | |
slots A-D <----> 40 direct pins, one voltage | slots E-H <----> 40 direct pins, one voltage |
slot L | <----> 5 V-safe 8-bit + 2-bit bus |
SFP 0 and 1 <----> fast serial lanes | |
+--------------------------------+

## Start here

1. Leave all extensions unplugged.
2. Set both VCCIO selectors to 3.3 V.
3. Set each AUX selector to 3.3 V, or leave its jumper off.
4. Plug USB-C into Odin.
5. Wait for the supervisor to start.
6. Plug in one simple extension and test it before adding the next.

Use a USB-PD charger when the board carries displays, speakers, motors or SFP modules. A computer port is fine for programming and light work, but it may not have enough power for everything at once.

Odin never asks USB-C for more than 9 V.

## The extension idea, from zero

user-manual.md | 2026-09-03

Odin has eight shield connectors arranged in two matching rows on opposite sides of the 100 x 100 mm board. Each connector has 16 metal pins. A ninth connector, L, is the separate 5 V-safe legacy slot.

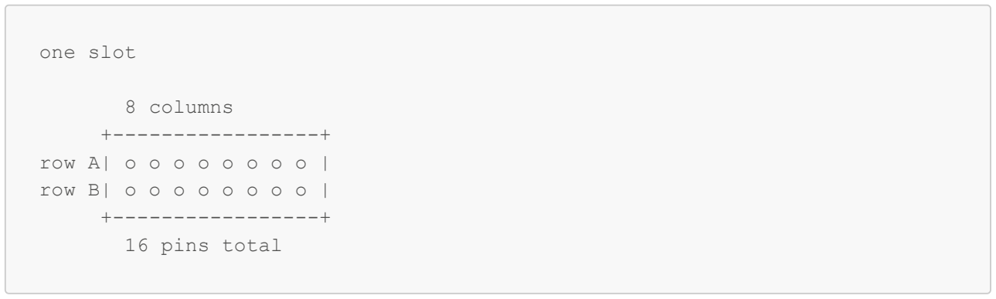
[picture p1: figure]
one slot; 8 columns +-----------------+ row A| o o o o o o o o | row B| o o o o o o o o | +-----------------+ 16 pins total

Ten of those pins are signals. The other six are ground and power.

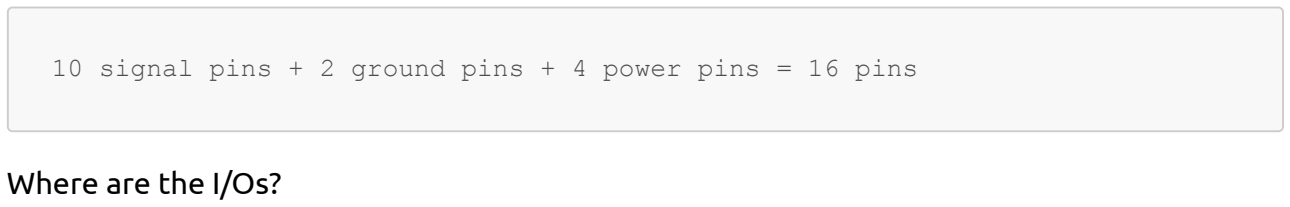
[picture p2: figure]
Where are the I/Os?

10 signal pins + 2 ground pins + 4 power pins = 16 pins

Here. IO means a signal you can use as an input or an output.

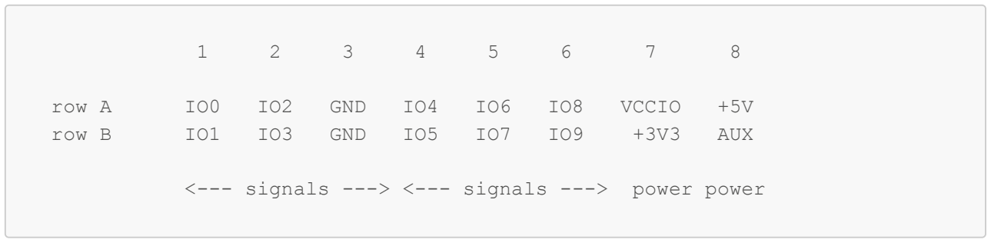
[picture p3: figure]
row A; GND; VCCIO; row B; AUX

<--- signals ---> <--- signals ---> power power

The ten I/Os are columns 1, 2, 4, 5 and 6. Each of those columns has two signal pins. Column 3 is ground. Columns 7 and 8 are power.

The schematic calls the same signals P0+, P0-, and so on. You do not have to use them as pairs:

connector name | ordinary use
P0+ and P0- | IO0 and IO1
P1+ and P1- | IO2 and IO3
P2+ and P2- | IO4 and IO5
P3+ and P3- | IO6 and IO7
P4+ and P4- | IO8 and IO9

They are called pairs because the FPGA can send one fast signal over two wires. One wire rises while the other falls. This rejects noise. If you do not need that, use them as ten ordinary, unrelated I/Os.

What do 16, 32 and 64 mean?

They mean the width used on each side of the base board. An extension is a bridge, not a board hanging from one edge.

one edge of Odin | | opposite edge
16 shield | [ A ]========================[ E ]
16 pins | extension | 16 pins
32 shield | [ A ][ B ]==================[ E ][ F ]
32 pins | extension | 32 pins
64 shield | [ A ][ B ][ C ][ D ]========[ E ][ F ][ G ][ H ]
64 pins | extension | 64 pins

A 16 therefore connects to one 16-pin header on each side: 32 physical pins and 20 I/Os in total. A 32 connects 32 pins to 32 pins. A 64 connects all 64 pins on one side to all 64 on the other: 128 physical pins and 80 I/Os.

The schematic names four 16-pin sections on each edge. Those are electrical zones, not a demand for four separate plastic connectors. Odin can use the original physical arrangement: two continuous 32-pin stack-through headers on each edge. A 16 shield uses half of one header, a 32 uses one whole header, and a 64 uses both headers. The keying and outlines must make those partial positions unambiguous.

The bridge gives the extension support at both ends, almost the full board area above Odin, and matching connectors on top so another shield can stack. The extension PCB and its fitted headers determine its size; there is no size switch.

Where are the slots on Odin?

The required arrangement is:

100 mm
+----------------------------------+
| [ A ][ B ][ C ][ D ] | | bank 15
| | ODIN | | shield bridges
| | | | across this space
| [ E ][ F ][ G ][ H ] | | bank 34
+----------------------------------+

[ L ] separate 5 V-safe legacy connector

Matching pairs are A/E, B/F, C/G and D/H. Placement must put each pair directly opposite its partner. All eight connectors need the same pitch, orientation and distance from the board edges.

Their exact coordinates do not exist yet because placement has not been done. Until those coordinates and a real extension outline are drawn and measured together, the bridge and stacking fit remain an intention, not a proven feature.

Slots A-D always share one signal voltage. Slots E-H share another. Changing a VCCIO jumper changes the voltage of the whole group, not one slot.

Shield | Connectors underneath | Pins per side | Total pins | Usable I/Os
16 | A+E, B+F, C+G or D+H | 16 | 32 | 20
32 | Two matching pairs | 32 | 64 | 40
64 | A-D and E-H | 64 | 128 | 80

A shield reaches both FPGA banks. The A-D side shares one VCCIO setting; the E-H side shares the other. A 64 owns both complete groups. A smaller shield must share each side's voltage with anything using the unused connector pairs.

Stacking

Every shield needs female sockets underneath and matching male pins on top. The signals pass vertically through the board so another shield can plug in.

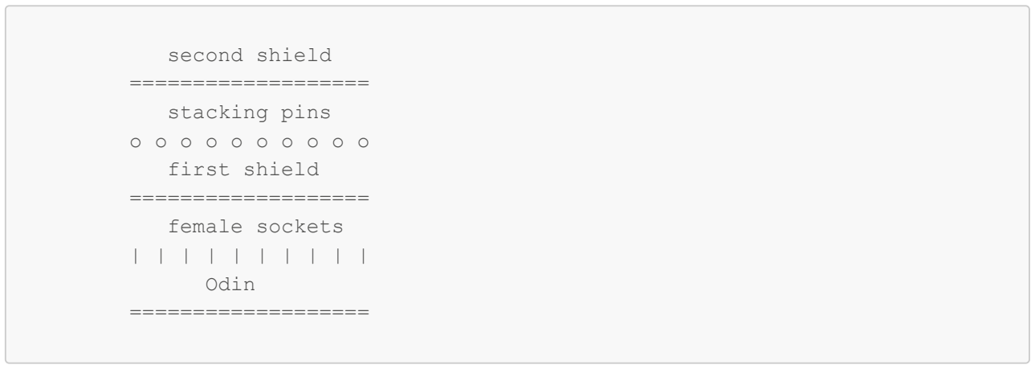
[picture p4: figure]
second shield =================== stacking pins • o o o o o o o o o first shield =================== female sockets | | | | | | | | | | Odin ===================

Stacking does not create more FPGA pins or more power. Stacked shields share the same wires, voltage groups and current budget. They must not drive the same signal at the same time.

The key posts, stacking headers, component height and board-to-board spacing must be designed as one mechanical system. A key that works for one board but blocks the next board is not a working key.

## One slot, using the schematic names

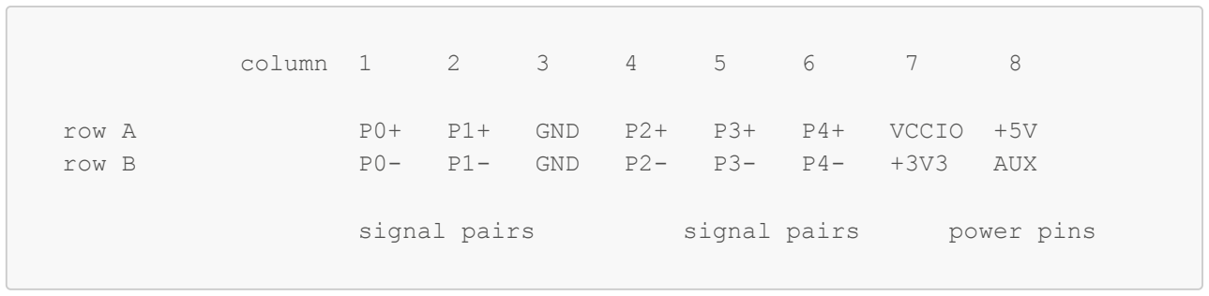
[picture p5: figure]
column 1; row A; GND; VCCIO +5V; row B; AUX; signal pairs; power pins

The separate post beside the header is the key. If the extension does not drop onto the header and key without force, it is the wrong way round.

Never shift the extension sideways by one column. Check the key before power.

## What the four power pins mean

Pin | Meaning
VCCIO | The signal voltage for that FPGA bank: 3.3, 2.5 or 1.8 V
+5V | Fixed supply for 5 V parts
+3V3 | Fixed supply for ordinary 3.3 V parts
AUX | Chosen beside the slot: 12 V, 5 V or 3.3 V

VCCIO is both a power output and the voltage used by the FPGA pins. That is why the signals and the extension cannot silently disagree.

The 1.0 V FPGA core rail never reaches a connector.

Power is shared

The small fuse beside each slot is fault protection. It is not a promise that every slot may draw the number printed on the fuse at the same time.

The 12 V AUX rail is the tightest. Treat about 0.5 A across the whole board as the present design target, pending final component qualification. One LCD backlight is sensible. Nine motors are not.

The final production manual must take its exact limits from the released power-budget report. Do not copy preliminary figures from an old schematic.

## Which slot should I use?

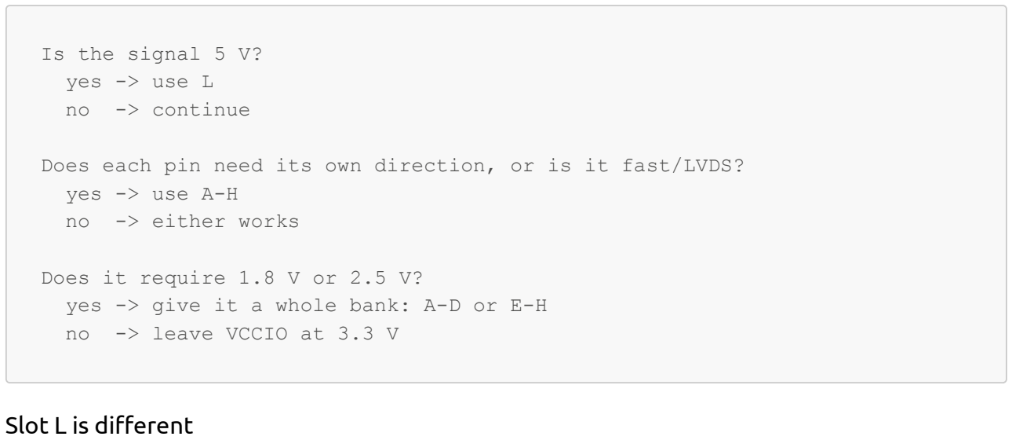
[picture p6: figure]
Is the signal 5 V? yes -> use L no -> continue; yes -> use A-H no -> either works; Does it require 1.8 V or 2.5 V? yes -> give it a whole bank: A-D or E-H no -> leave VCCIO at 3.3 V; Slot L is different

Does each pin need its own direction, or is it fast/LVDS?

Slot L protects the FPGA from 5 V signals. It is not ten unrelated GPIOs.

I/O 0-7 : one 8-bit bus, one shared direction

I/O 8-9 : one 2-bit bus, one shared direction

All eight pins in the first group turn around together. The last two turn around together. Use L for old 5 V buses, parallel displays and similar parts. Do not use it for I2C, one-wire parts, or a mixture of inputs and outputs that must change direction independently.

Slots A-H connect directly to FPGA pins. They are flexible and fast, but they are not 5 V tolerant.

## Example 1: a 3.3 V SPI sensor

Use one direct slot, for example A.

Sensor VCC | -> +3V3
Sensor GND | -> GND
Sensor SCK | -> any signal pin
Sensor MOSI -> any signal pin Sensor MISO -> any signal pin Sensor CS -> any signal pin

VCCIO group A-D -> 3.3 V
AUX jumper | -> not needed

Six signal pins remain free. The sensor receives clean 3.3 V even if another bank uses a different voltage.

## Example 2: an old 5 V parallel peripheral

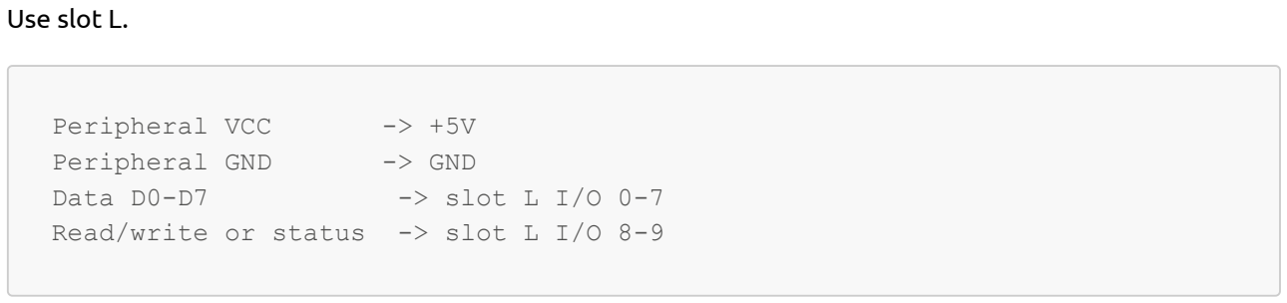
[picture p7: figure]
Use slot L.; Peripheral VCC; Peripheral GND; -> GND; Data D0-D7; -> slot L I/O 0-7; Read/write or status -> slot L I/O 8-9

In the FPGA design, drive the 8-bit direction control before driving or reading D0-D7. Do the same separately for I/O 8-9.

Do not connect a 5 V signal to A-H just because its power comes from their 5 V pin. Power voltage and signal voltage are separate things.

## Example 3: a small handheld

A 64 shield bridges A-D to E-H and gets eighty direct 3.3 V signals. This example only needs thirty-seven:

16 LCD colour bits
4 pixel clock and display timing
8 buttons

2 display reset and backlight control 3 digital audio
4 microSD SPI
37 used
43 spare

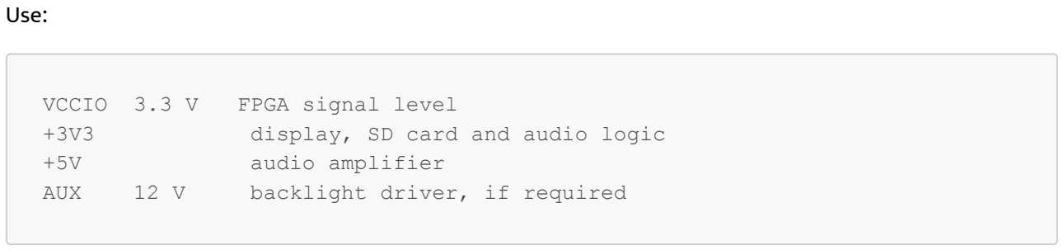
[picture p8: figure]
Use:; VCCIO 3.3 V; FPGA signal level; display, SD card and audio logic; audio amplifier; AUX; backlight driver, if required

The framebuffer belongs in PSRAM. A 320 x 240 RGB565 frame is about 150 KB; the board has 8 MB.

## Memory without ceremony

Odin has four 2 MB PSRAM chips. Each has its own connection to the FPGA.

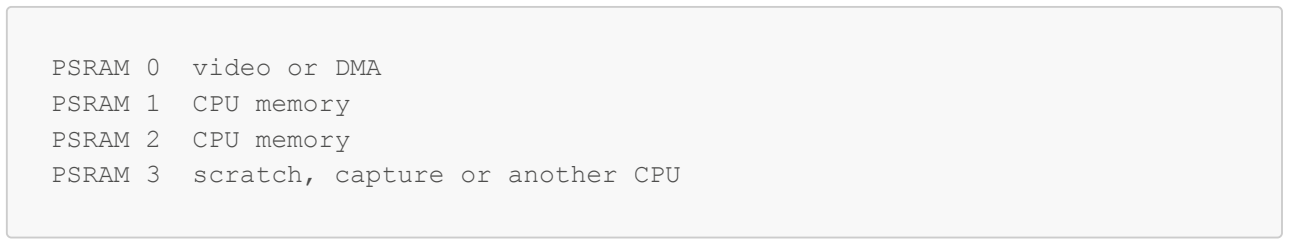
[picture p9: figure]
PSRAM 0 video or DMA PSRAM 1 CPU memory PSRAM 2 CPU memory PSRAM 3 scratch, capture or another CPU

That split is only an example. HDL decides what each chip does. The hardware does not force them to share one busy connection.

One chip can move roughly 50 MB/s at a 100 MHz quad-SPI clock. Four used together can approach 200 MB/s. VGA RGB565 fits on one. 1080p60 RGB565 does not fit on all four. That is the honest ceiling.

## Programming and recovery

The supervisor has its own flash. The FPGA has another. They are not the same thing.

Storage | Holds
Supervisor flash | The software that runs the board
FPGA flash | FPGA images and fabric software

A new blank board enters its built-in USB loader. Copy the supervisor firmware to the USB drive that appears.

If a later supervisor update goes wrong:

1. Unplug power.
2. Hold BOOTSEL.

3. Plug USB-C back in.
4. Release the button when the USB drive appears.
5. Copy known-good supervisor firmware to it.

The recovery loader is inside the chip. A broken flash image cannot erase it.

External JTAG

Normal use needs no external programmer. J2 exists for low-level FPGA debug. Fit the JTAG isolation jumper before attaching an external programmer; that disconnects the supervisor from the same four wires. Remove the jumper for normal supervisor-controlled programming.

## Fast links

Two SFP sockets are fitted by default. They can accept suitable copper, fibre or direct-attach modules.

The FPGA provides the physical serial lane. Your FPGA design still needs the protocol logic. Plugging in a copper Ethernet module does not create an Ethernet controller by itself.

The lanes top out around 6.6 Gb/s. Use them for 1 Gb/s or suitable 2.5 Gb/s links, not 10 Gb/s modules.

Two more unfilled SFP positions preserve lanes 2 and 3 for a later build.

## If something goes wrong

The board resets when an extension starts

The power source is probably too small, or the extension has too much startup current.

Remove the extension and try again.
Use a USB-PD charger instead of a computer port.
Check the extension for a short.
Start with AUX disabled or set to 3.3 V.

An extension does nothing

Check the key and header alignment.
Check the VCCIO setting for the whole bank.
Check its AUX selector.
Remember that Slot L uses shared direction controls.
Remember that a blown or tripped branch fuse is not fixed by HDL.

The FPGA will not program

Remove every extension.
Restore both VCCIO groups to 3.3 V.

Remove the external-JTAG isolation jumper for normal programming. Recover the supervisor with BOOTSEL.

A rail reads low

Disconnect extensions one at a time. A bad extension should be treated as the fault until it works alone on a current-limited bench supply.

## Rules worth remembering

1. Check the key before power.
2. Slots in one bank share one VCCIO setting.
3. Only Slot L accepts 5 V signals.
4. Slot L is an 8-bit bus plus a 2-bit bus, not ten independent GPIOs.
5. The four connector rails share the board's total power.
6. Never feed power into an Odin power-output pin.
7. Start a new extension at 3.3 V with AUX disabled.
8. Test one extension before stacking several.
9. Use a PD charger for power-heavy projects.
10. When in doubt, unplug power first.

## Before this manual becomes a release manual

The circuit is still being qualified. Replace this section with final ratings before shipping hardware:

Exact shared and per-slot current limits
Extension-rail shutdown and fault behavior
Final connector positions and orientation drawing Supervisor status messages and firmware-loading names Qualified SFP module types
Board revision and matching schematic commit

Until those are fixed, this is the user contract for the design—not permission to fabricate an unchecked revision.

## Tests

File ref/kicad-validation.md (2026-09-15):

# KiCad regeneration and validation

Validated with KiCad CLI / pcbnew 9.0.8 on 2026-09-15.

**Current ERC:** zero errors; only FPGA_DXP and FPGA_DXN dangling-label
warnings. Run `python3 tools/check_erc.py` to enforce the exact list.
Earlier sections below record historical results before pin-type normalization.

## Synchronized changes

- Six copper layers: signal / GND / signal / power / GND / signal.
- R35 and R89: independent 100 ohm, 1% MGTRREF resistors to +1V2_MGT.
- Quad 213 RX pins and unused quad 216 RX lanes connected to GND.
- U1.P12 VREFP connected to GND for the internal XADC reference.
- R90–R95: 100k regulator-enable pulldowns to GND.
- R96/R97: 10k bus-enable pull-ups to +3V3; OE_N controlled by P16/Y25.

The schematic and PCB contain 457 components. Every populated component's
reference/value and every connected pad were compared against `design.build()`.
All checks passed. All 447 retained footprint positions, orientations and
sides match the pre-sync board, including footprints updated to the current
library selection. The obsolete VREFP decoupler C1 was removed; subsequent
capacitors were renumbered while retaining their physical placement.

Eight new resistors and two previously missing SFP cages (SH1/SH2) were added
in a staging area outside the board during the electrical sync. The cage
swap below subsequently placed SH1/SH2 and J60/J61. The eight resistors
remain staged; placement and routing remain unfinished.

Standard symbol libraries are now explicitly listed in the project library
table. Silkscreen user labels use separate fields, preserving the schematic
values used for BOM and parity checks.

## Checks and remaining findings

Commands:

```sh
python3 tools/gen_project.py
kicad-cli sch export netlist --format kicadsexpr -o kicad/odin.net kicad/odin.kicad_sch
kicad-cli sch erc --format json -o /tmp/freyja-sync/erc.json kicad/odin.kicad_sch
kicad-cli pcb drc --schematic-parity --format json -o /tmp/freyja-sync/drc.json kicad/odin.kicad_pcb
```

- ERC: 1 error (`SUP_SWCLK` input has no output driver), 317 pin-type warnings
  involving imported symbols, 2 dangling FPGA temperature-diode labels.
- DRC: 783 violations, including shorts, clearances, courtyard/silkscreen
  collisions, and invalid outlines; 499 unrouted connections.
- Schematic parity: 2 warnings. J60/J61 use the standard SFP symbol containing
  a `CAGE` pin, while their electrical connector footprints have only 20 pads.
  SH1/SH2 represent the separate physical cages. This symbol/footprint mismatch
  remains to be resolved; no fictitious pad was added to suppress it.

The six requested electrical changes are synchronized. ERC/DRC are not clean,
and the board is not ready for fabrication.

## Solder-tail cage update

Replaced SH1/SH2 with Amphenol U77A11133001 / C5355132 and regenerated the
custom library, schematic, qualified-parts table and netlist. The PCB's four
SFP footprints now follow the drawing-derived placement contract. The other
453 footprints retain their previous positions, sides and orientations.
All 457 component references, values, footprint IDs and connected pad nets
match the regenerated netlist.

Actual KiCad pad-coordinate checks passed for both assemblies:

- 20 grounded cage tails: ten 1.05 mm, nine 0.95 mm, one 0.85 mm drill.
- Connector peg spacing 9.60 mm; both holes 1.55 mm NPTH.
- Peg centreline 35.40 mm behind board edge.
- Front contacts 1–10 at depth 31.30 mm, rear contacts 11–20 at 39.50 mm.
- Placement contract geometry clean; EasyEDA audit passes for 125 instances.

Latest KiCad CLI results (`/tmp/freyja-cage/erc.json` and `drc.json`):
ERC 1 error and 279 warnings (277 pin-type, 2 dangling labels); DRC 688
violations, 499 unrouted connections, 2 existing SFP-symbol parity warnings.
The only DRC violations involving the four SFP footprints are the two
intentional connector-inside-cage courtyard overlaps. These checks establish
footprint consistency, not completed routing or higher-rate port qualification.

## DONE LED buffer update

Added R98 (4.7k from +3V3 to CFG_DONE) and Q4 (BSS138LT1G low-side
LED driver). R7 now feeds D1 from +3V3; D1's cathode connects to Q4's drain.
The gate connects to CFG_DONE and source to GND. Existing SUP_DONE wiring
and all previous component designators are preserved. No DriveDone setting
is required for LED operation.

Regenerated schematic, netlist and qualified-parts table; synchronized PCB.
All 459 component values, footprint IDs and connected pad nets match the
netlist. All 457 previous footprint positions, orientations and sides are
preserved. Q4 and R98 are staged outside the board; the board still requires
physical placement and routing, including the previously staged DONE LED.

Topology checks verify R7 → D1 → Q4, the pull-up and G/S/D pin mapping, and
confirm only R7/D1 connections changed among existing parts. EasyEDA audit
passes for 126 fitted instances. KiCad ERC/DRC counts remain unchanged:
1 ERC error, 279 warnings; 688 DRC violations, 499 unrouted connections and
2 schematic-parity warnings. Latest reports: `/tmp/freyja-done/erc.json`
and `/tmp/freyja-done/drc.json`.

## SFP I2C isolation update

Added U27 (PCA9543APW,118), C231 and R99–R103. J60/J61 now use separate
SFP0/SFP1 SDA/SCL nets behind the switch; upstream supervisor/U17 wiring
is preserved. Verified the manufacturer pin map, grounded address pins,
SUP_RUN reset connection and distinct connector channels. Existing parts
retain their references; only J60/J61's management connections changed.

All 466 component values, footprint IDs and connected pad nets match the
regenerated netlist. All 459 previous placements, orientations and sides
are preserved. Seven new footprints are staged outside the board; placement
and routing remain unfinished. The placement source includes an SFP mux
group anchor. The import audit passes for 126 fitted EasyEDA instances;
U27 instead uses a generated symbol and standard KiCad TSSOP-14 footprint.

KiCad counts are unchanged: ERC 1 error/279 warnings, DRC 688 violations,
499 unrouted connections, 2 existing SFP parity warnings. Latest reports
are `/tmp/freyja-mux/erc.json` and `/tmp/freyja-mux/drc.json`. There is no
hardware enumeration test or implemented supervisor firmware yet.

## PSRAM series resistor update

Added R104–R127, 33 ohm 0402, on all 24 PSRAM signals. Each FPGA-side net
has exactly two nodes (U1 and resistor pad 1); each `_MEM` net has exactly
two nodes (resistor pad 2 and its own PSRAM). All four ports remain isolated,
and the FPGA assignments and all existing designators are preserved.

All 490 component values, footprint IDs and connected pad nets match the
exported netlist. All 466 previous positions/orientations/sides are preserved.
The new resistors sit beside U1 under the new placement rule; U1 itself is
still in the staged layout outside the board. Routing remains unfinished.
Their reference/value text uses fabrication layers to avoid silkscreen
collisions at 1 mm spacing.

ERC: 1 error / 279 warnings. DRC: 688 violations, 499 unrouted connections,
2 existing SFP parity warnings; counts unchanged after text cleanup. Reports:
`/tmp/freyja-psram/erc.json` and `/tmp/freyja-psram/drc.json`. EasyEDA audit
passes for 126 fitted instances. No electrical waveform or timing validation
has been performed on hardware.

## +12V_EXT output capacitor update

C232 is 10uF 25V / C15850 from U25 pin 6 (+12V_EXT) to GND. Generator,
schematic, netlist and PCB agree. All 491 component values, footprint IDs
and pad nets match the netlist; all 490 previous components and placements
are unchanged. C232 is staged outside the board and assigned to U25's group
for subsequent placement close to OUT.

ERC and DRC counts remain unchanged: 1 ERC error / 279 warnings;
688 DRC violations, 499 unrouted connections and 2 existing parity warnings.
Reports: `/tmp/freyja-cout/erc.json` and `/tmp/freyja-cout/drc.json`.

## Q2 gate divider and external-input TVS

R49 is now 47k, preserving its VBUS5_PULL/VBUS5_GATE connections. D8 is
SMBJ15A-13-F / C135046: cathode (pad 1) to VIN_EXT, anode (pad 2) to GND,
on the terminal side of D4. Verified nominal divider VGS (-6.122V at 9V),
1% resistor/+5% source tolerance (6.470V magnitude), and 3.197ms gate RC.

All 492 component values, footprint IDs and pad nets match the exported
netlist. All 491 previous positions/orientations/sides are unchanged. D8 is
staged for placement next to J50; its short surge-current path is not routed.
ERC/DRC counts are unchanged (1/279 ERC error/warnings; 688 DRC violations,
499 unrouted, 2 parity warnings). Reports are in
`/tmp/freyja-input-protection/`. No physical surge testing has been performed.

## Supervisor indicators and core PG input

Added D9–D11 (green LEDs) and R128–R130 (1k); U17 P0–P2 sink their
cathodes and P3 reads CORE_1V0_GOOD. The 100k PG pull-up and P7 SFP control
remain. Verified all three LED polarities/current paths and the expander
physical pin map. All 498 component values, footprint IDs and connected
pad nets match the exported netlist; all 492 earlier placements are preserved.

The new parts are staged outside the board, with visible CTRL HB/USER 1/
USER 2 labels; their final group anchor is in the placement source. The
power budget includes a 5mA allowance and passes. EasyEDA audit passes for
129 fitted instances. Firmware behavior is documented but not implemented.

KiCad ERC: 1 error, 286 warnings (284 pin-type, 2 dangling labels), adding
seven pin-type warnings from the imported expander/LED symbols. DRC:
694 violations, 499 unrouted connections and 2 existing parity warnings;
the six additional violations are silkscreen warnings on the added LEDs.
No new ERC/DRC errors. Reports: `/tmp/freyja-status/erc.json` and `drc.json`.

## ERC pin-type normalization and regression guard

`tools/gen_kicad.py` now normalizes eleven imported symbols using reviewed
pin roles. J51 pins 1/3 model bidirectional SWD debugger connections; its
ground/mechanical pins are passive. Connector/LED pins are passive and U17
PCF8574 pins use actual supply, address/clock input, bidirectional port/data,
and open-drain interrupt roles. Pin names, numbers, positions and connectivity
are unchanged. The normalization is idempotent and survives regeneration.

After library/schematic regeneration, ERC reports **0 errors, 2 warnings**:
only the FPGA_DXP/FPGA_DXN global labels. U20 produces no warning, so none
is exempted. No ERC exclusions or severity changes were introduced.
`tools/check_erc.py` runs KiCad with all severities and compares exact rule,
severity and item descriptions. Checked that extra warnings (including U20),
renamed labels, changed severities and missing expected warnings fail.

The regenerated netlist still matches all 498 PCB components and pad nets;
no board mutation was needed. EasyEDA audit passes for 129 instances.
The latest standalone ERC report is `/tmp/erc-typed.json`; the regression
command creates and checks a fresh report each run.

## Six-layer routing classes and impedance rules

`python3 tools/gen_pcb.py --rules-only` updates JLC06161H-1080B material
parameters, project net classes and custom DRC constraints. It preserves
all board content outside the stackup block byte-for-byte; a second run
produces identical PCB, project and rules files.

The JLC coated-microstrip solver predicts 99.8515 Ω for the rounded
0.099 mm width / 0.200 mm gap. Inputs and original solver responses are
recorded in [PCB impedance](pcb-impedance.md). MGT routing is constrained
to the outer layers; PSRAM minimum width is 0.1 mm, default clearance is
0.15 mm, and MGT intra-pair skew is limited to 0.1 mm.

KiCad 9.0.8 command:

```sh
kicad-cli pcb drc --format json --schematic-parity \
  -o /tmp/freyja-routing-rules/after.json kicad/odin.kicad_pcb
```

Full output (exit status 0; no rule syntax errors):

```text
Found 693 violations
Found 499 unconnected items
Found 2 schematic parity issues
Saved DRC Report to /tmp/freyja-routing-rules/after.json
```

Baseline was 694 / 499 / 2. The clearance violation count decreased from
15 to 14; all other violation-type counts are unchanged. This is a rule
parser check, not a clean fabrication DRC.

A separate temporary routed test board using the generated project and
rules verified that a 0.20 mm mismatch on MGTPTXP0/MGTPTXN0 produces
`skew_out_of_range`, while a 0.05 mm mismatch on the much longer
MGTREFCLK0P/N pair does not. Thus the limit applies within each pair,
not across all MGT lanes. A 0.09 mm PSRAM0_SCK track produces `track_width`.
KiCad recognizes all ten real-board differential pairs, including names
with trailing channel digits. Test artifacts: `/tmp/freyja-routing-rules/`.

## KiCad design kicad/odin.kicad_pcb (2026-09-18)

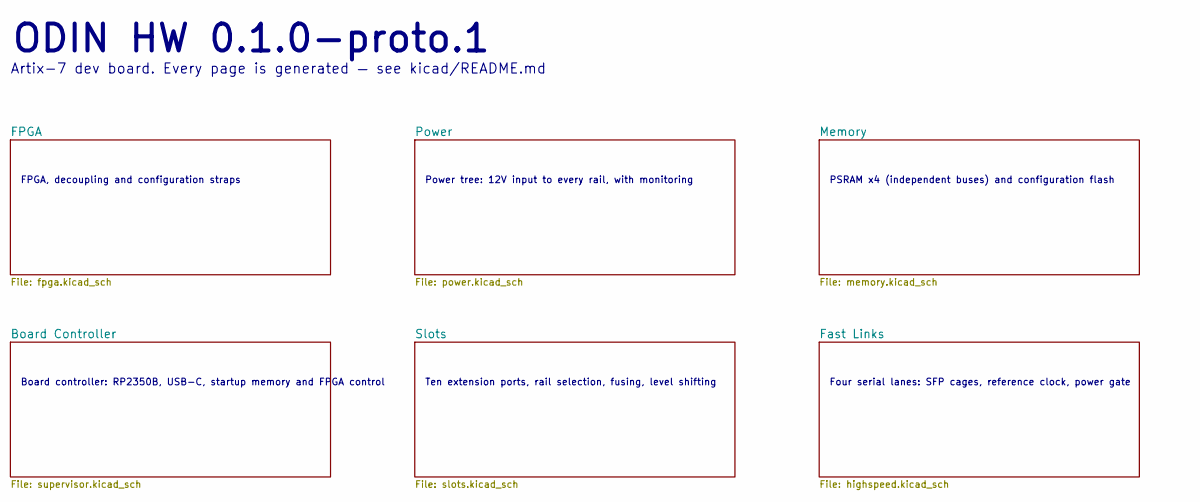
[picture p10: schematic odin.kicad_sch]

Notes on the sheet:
ODIN HW 0.1.0-proto.1
Artix-7 dev board. Every page is generated — see kicad/README.md
FPGA, decoupling and configuration straps
Power tree: 12V input to every rail, with monitoring
PSRAM x4 (independent buses) and configuration flash
Board controller: RP2350B, USB-C, startup memory and FPGA control
Ten extension ports, rail selection, fusing, level shifting
Four serial lanes: SFP cages, reference clock, power gate

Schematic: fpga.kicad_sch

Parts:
C1, C2, C3, C4, C5, C6, C7, C8, C9, C10, C11, C12, C13, C14, C15, C16, C17, C18, C19, C20, C21, C22, C23, C24, C25, C26, C27, C28, C29, C30, C31, C32, C33, C34, C35, C36, C37, C38, C39, C40, C41, C42, C43, C44, C45, C46, C47, C48, C49, C50, C51, C52, C53, C54, C55, C56, C57, C58, C59, C60, C61, C62, C63, C64, C65, C66, C67, C68, C69, C70, C71, C72, C73, C74, C75, C76, C77, C78, C79, C80, C81, C82, C83, C84, C85, C86, C87, C88, C89, C90, C91, C92, C93, C94, C95, C96: 100nF; C_0402_1005Metric; LCSC C1525
C97, C98, C99, C100, C101, C102, C103, C104, C105, C106, C107, C108, C109, C110: 4.7uF; C_0603_1608Metric; LCSC C277476
D1: F.0603.00025/P2-0603G1TS2-06T-002; LED0603-RD_GREEN; LCSC C7496818
Q4: BSS138LT1G; SOT-23-3_L2.9-W1.6-P1.90-LS2.8-BR; LCSC C82045
R1, R2, R3, R4, R5, R98: 4.7k; R_0402_1005Metric; LCSC C25900
R6: 1k; R_0402_1005Metric; LCSC C11702
R7: 330; R_0402_1005Metric
U1: XC7A100T-2FGG676I; FBGA-676_L27.0-W27.0-R26-C26-P1.00-BL; LCSC C1521803

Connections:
+1V0: C27.1, C28.1, C29.1, C30.1, C31.1, C32.1, C33.1, C34.1, C35.1, C36.1, C37.1, C38.1, C39.1, C45.1, C46.1, C47.1, C48.1, C97.1, C98.1, C99.1, C100.1, U1.J11 (VCCINT), U1.J13 (VCCINT), U1.K10 (VCCINT), U1.K12 (VCCINT), U1.L11 (VCCINT), U1.L13 (VCCINT), U1.M10 (VCCINT), U1.N13 (VCCBRAM), U1.P10 (VCCINT), U1.R13 (VCCBRAM), U1.T10 (VCCINT), U1.T12 (VCCINT), U1.U11 (VCCINT), U1.U13 (VCCBRAM), U1.V10 (VCCINT), U1.V12 (VCCINT), U1.W13 (VCCBRAM); also elsewhere on the board
+1V0_MGT: C5.1, C6.1, C7.1, C8.1, C9.1, C10.1, C11.1, C12.1, C13.1, C14.1, C109.1, U1.AA10 (MGTAVCC_G10), U1.AA12 (MGTAVCC_G10), U1.AC9 (MGTAVCC_G10), U1.AC11 (MGTAVCC_G10), U1.AC13 (MGTAVCC_G10), U1.D9 (MGTAVCC_G11), U1.D11 (MGTAVCC_G11), U1.D13 (MGTAVCC_G11), U1.F10 (MGTAVCC_G11), U1.F12 (MGTAVCC_G11); also elsewhere on the board
+1V2_MGT: C15.1, C16.1, C17.1, C18.1, C19.1, C20.1, C21.1, C22.1, C23.1, C24.1, C25.1, C26.1, C110.1, U1.AD7 (MGTAVTT_G10), U1.AD15 (MGTAVTT_G10), U1.AE8 (MGTAVTT_G10), U1.AE10 (MGTAVTT_G10), U1.AE12 (MGTAVTT_G10), U1.AE14 (MGTAVTT_G10), U1.B8 (MGTAVTT_G11), U1.B10 (MGTAVTT_G11), U1.B12 (MGTAVTT_G11), U1.B14 (MGTAVTT_G11), U1.C7 (MGTAVTT_G11), U1.C15 (MGTAVTT_G11); also elsewhere on the board
+1V8: C1.1, C40.1, C41.1, C42.1, C43.1, C44.1, C101.1, C102.1, U1.J9 (VCCAUX), U1.L9 (VCCAUX), U1.M12 (VCCADC_0), U1.N9 (VCCAUX), U1.R9 (VCCAUX), U1.U9 (VCCAUX); also elsewhere on the board
+3V3: C2.1, C3.1, C4.1, C49.1, C50.1, C51.1, C52.1, C53.1, C54.1, C55.1, C56.1, C57.1, C58.1, C59.1, C60.1, C61.1, C62.1, C63.1, C64.1, C65.1, C66.1, C73.1, C74.1, C75.1, C76.1, C77.1, C78.1, C79.1, C80.1, C81.1, C82.1, C83.1, C84.1, C91.1, C92.1, C93.1, C94.1, C95.1, C96.1, C103.1, C104.1, R1.1, R4.1, R5.1, R7.1, R98.1, U1.A1 (VCCO_35), U1.A21 (VCCO_16), U1.AA1 (VCCO_33), U1.AA21 (VCCO_12), U1.AB15 (CFGBVS_0), U1.AB18 (VCCO_12), U1.AC5 (VCCO_33), U1.AC25 (VCCO_13), U1.AD2 (VCCO_33), U1.AD22 (VCCO_12), U1.AE19 (VCCO_12), U1.AF26 (VCCO_12), U1.B18 (VCCO_16), U1.C5 (VCCO_35), U1.C25 (VCCO_16), U1.D2 (VCCO_35), U1.D22 (VCCO_16), U1.E19 (VCCO_16), U1.F6 (VCCO_35), U1.F16 (VCCO_16), U1.G3 (VCCO_35), U1.J7 (VCCO_35), U1.K24 (VCCO_14), U1.L21 (VCCO_14), U1.N15 (VCCO_14), U1.N25 (VCCO_14), U1.P22 (VCCO_14), U1.R19 (VCCO_14), U1.T16 (VCCO_13), U1.T26 (VCCO_13), U1.U3 (VCCO_33), U1.U23 (VCCO_13), U1.V20 (VCCO_13), U1.W7 (VCCO_33), U1.W11 (VCCO_0), U1.W17 (VCCO_12), U1.Y4 (VCCO_33), U1.Y14 (VCCO_0), U1.Y24 (VCCO_13); also elsewhere on the board
BUS5V0_DIR: U1.M19 (IO_0_14); also elsewhere on the board
BUS5V0_IO0: U1.N26 (IO_L20P_T3_A08_D24_14); also elsewhere on the board
BUS5V0_IO1: U1.M26 (IO_L20N_T3_A07_D23_14); also elsewhere on the board
BUS5V0_IO2: U1.T24 (IO_L21P_T3_DQS_14); also elsewhere on the board
BUS5V0_IO3: U1.T25 (IO_L21N_T3_DQS_A06_D22_14); also elsewhere on the board
BUS5V0_IO4: U1.R26 (IO_L22P_T3_A05_D21_14); also elsewhere on the board
BUS5V0_IO5: U1.P26 (IO_L22N_T3_A04_D20_14); also elsewhere on the board
BUS5V0_IO6: U1.T22 (IO_L23P_T3_A03_D19_14); also elsewhere on the board
BUS5V0_IO7: U1.R22 (IO_L23N_T3_A02_D18_14); also elsewhere on the board
BUS5V0_OE_N: U1.P16 (IO_L3N_T0_DQS_EMCCLK_14); also elsewhere on the board
BUS5V1_DIR: U1.U24 (IO_0_13); also elsewhere on the board
BUS5V1_IO0: U1.U25 (IO_L1P_T0_13); also elsewhere on the board
BUS5V1_IO1: U1.U26 (IO_L1N_T0_13); also elsewhere on the board
BUS5V1_IO2: U1.V26 (IO_L2P_T0_13); also elsewhere on the board
BUS5V1_IO3: U1.W26 (IO_L2N_T0_13); also elsewhere on the board
BUS5V1_IO4: U1.AB26 (IO_L3P_T0_DQS_13); also elsewhere on the board
BUS5V1_IO5: U1.AC26 (IO_L3N_T0_DQS_13); also elsewhere on the board
BUS5V1_IO6: U1.W25 (IO_L4P_T0_13); also elsewhere on the board
BUS5V1_IO7: U1.Y26 (IO_L4N_T0_13); also elsewhere on the board
BUS5V1_OE_N: U1.Y25 (IO_L5P_T0_13); also elsewhere on the board
CFG_CCLK: U1.H13 (CCLK_0); also elsewhere on the board
CFG_DONE: Q4.1 (G), R98.2, U1.W10 (DONE_0); also elsewhere on the board
CFG_INIT_B: R5.2, U1.V11 (INIT_B_0); also elsewhere on the board
CFG_M0: R1.2, U1.AB7 (M0_0)
CFG_M1: R2.1, U1.Y9 (M1_0)
CFG_M2: R3.1, U1.W9 (M2_0)
CFG_PROG_B: R4.2, U1.AE16 (PROGRAM_B_0); also elsewhere on the board
DBG_TCK: U1.P23 (IO_L17P_T2_A14_D30_14); also elsewhere on the board
DBG_TDI: U1.R20 (IO_L18P_T2_A12_D28_14); also elsewhere on the board
DBG_TDO: U1.R21 (IO_L18N_T2_A11_D27_14); also elsewhere on the board
DBG_TMS: U1.P24 (IO_L17N_T2_A13_D29_14); also elsewhere on the board
DONE_LED_A: D1.2 (A), R7.2
DONE_LED_K: D1.1 (C), Q4.3 (D)
FLASH_CS_B: U1.P18 (IO_L6P_T0_FCS_B_14); also elsewhere on the board
FLASH_D0_MOSI: U1.R14 (IO_L1P_T0_D00_MOSI_14); also elsewhere on the board
FLASH_D1_MISO: U1.R15 (IO_L1N_T0_D01_DIN_14); also elsewhere on the board
FLASH_D2_WP: U1.P14 (IO_L2P_T0_D02_14); also elsewhere on the board
FLASH_D3_HOLD: U1.N14 (IO_L2N_T0_D03_14); also elsewhere on the board
FPGA_DXN: U1.R11 (DXN_0)
FPGA_DXP: U1.R12 (DXP_0)
GND: C1.2, C2.2, C3.2, C4.2, C5.2, C6.2, C7.2, C8.2, C9.2, C10.2, C11.2, C12.2, C13.2, C14.2, C15.2, C16.2, C17.2, C18.2, C19.2, C20.2, C21.2, C22.2, C23.2, C24.2, C25.2, C26.2, C27.2, C28.2, C29.2, C30.2, C31.2, C32.2, C33.2, C34.2, C35.2, C36.2, C37.2, C38.2, C39.2, C40.2, C41.2, C42.2, C43.2, C44.2, C45.2, C46.2, C47.2, C48.2, C49.2, C50.2, C51.2, C52.2, C53.2, C54.2, C55.2, C56.2, C57.2, C58.2, C59.2, C60.2, C61.2, C62.2, C63.2, C64.2, C65.2, C66.2, C67.2, C68.2, C69.2, C70.2, C71.2, C72.2, C73.2, C74.2, C75.2, C76.2, C77.2, C78.2, C79.2, C80.2, C81.2, C82.2, C83.2, C84.2, C85.2, C86.2, C87.2, C88.2, C89.2, C90.2, C91.2, C92.2, C93.2, C94.2, C95.2, C96.2, C97.2, C98.2, C99.2, C100.2, C101.2, C102.2, C103.2, C104.2, C105.2, C106.2, C107.2, C108.2, C109.2, C110.2, Q4.2 (S), R2.2, R3.2, R6.2, U1.A6 (GND), U1.A8 (GND), U1.A10 (GND), U1.A12 (GND), U1.A13 (MGTPRXN2_216), U1.A14 (GND), U1.A16 (GND), U1.A26 (GND), U1.AA6 (GND), U1.AA9 (GND), U1.AA14 (GND), U1.AA16 (GND), U1.AA26 (GND), U1.AB3 (GND), U1.AB8 (GND), U1.AB9 (GND), U1.AB10 (GND), U1.AB12 (GND), U1.AB14 (GND), U1.AB23 (GND), U1.AC7 (GND), U1.AC12 (MGTPRXP0_213), U1.AC14 (MGTPRXP2_213), U1.AC15 (GND), U1.AC20 (GND), U1.AD6 (GND), U1.AD9 (GND), U1.AD11 (GND), U1.AD12 (MGTPRXN0_213), U1.AD13 (GND), U1.AD14 (MGTPRXN2_213), U1.AD16 (GND), U1.AE4 (GND), U1.AE6 (GND), U1.AE11 (MGTPRXP3_213), U1.AE13 (MGTPRXP1_213), U1.AE15 (GND), U1.AE24 (GND), U1.AF1 (GND), U1.AF6 (GND), U1.AF8 (GND), U1.AF10 (GND), U1.AF11 (MGTPRXN3_213), U1.AF12 (GND), U1.AF13 (MGTPRXN1_213), U1.AF14 (GND), U1.AF16 (GND), U1.AF21 (GND), U1.B3 (GND), U1.B6 (GND), U1.B13 (MGTPRXP2_216), U1.B15 (GND), U1.B16 (GND), U1.B23 (GND), U1.C6 (GND), U1.C9 (GND), U1.C11 (GND), U1.C12 (MGTPRXN3_216), U1.C13 (GND), U1.C16 (GND), U1.C20 (GND), U1.D7 (GND), U1.D12 (MGTPRXP3_216), U1.D15 (GND), U1.D17 (GND), U1.E4 (GND), U1.E7 (GND), U1.E8 (GND), U1.E9 (GND), U1.E10 (GND), U1.E12 (GND), U1.E14 (GND), U1.E15 (GND), U1.E24 (GND), U1.F1 (GND), U1.F9 (GND), U1.F14 (GND), U1.F21 (GND), U1.G10 (GND), U1.G11 (GND), U1.G12 (GND), U1.G13 (GND), U1.G14 (VCCBATT_0), U1.G18 (GND), U1.H5 (GND), U1.H25 (GND), U1.J2 (GND), U1.J12 (GND), U1.J22 (GND), U1.K9 (GND), U1.K11 (GND), U1.K13 (GND), U1.K19 (GND), U1.L6 (GND), U1.L10 (GND), U1.L12 (GND), U1.L16 (GND), U1.L26 (GND), U1.M3 (GND), U1.M9 (GND), U1.M11 (GNDADC_0), U1.M13 (GND), U1.M23 (GND), U1.N10 (GND), U1.N11 (VREFN_0), U1.N12 (VP_0), U1.N20 (GND), U1.P7 (GND), U1.P9 (GND), U1.P11 (VN_0), U1.P12 (VREFP_0), U1.P13 (GND), U1.P17 (GND), U1.R4 (GND), U1.R10 (GND), U1.R24 (GND), U1.T1 (GND), U1.T9 (GND), U1.T11 (GND), U1.T13 (GND), U1.T21 (GND), U1.U8 (GND), U1.U10 (GND), U1.U12 (GND), U1.U18 (GND), U1.V5 (GND), U1.V13 (GND), U1.V15 (GND), U1.V25 (GND), U1.W2 (GND), U1.W12 (GND), U1.W22 (GND), U1.Y10 (GND), U1.Y11 (GND), U1.Y12 (GND), U1.Y13 (GND), U1.Y19 (GND); also elsewhere on the board
JTAG_TCK: U1.H12 (TCK_0); also elsewhere on the board
JTAG_TDI: U1.H10 (TDI_0); also elsewhere on the board
JTAG_TDO: U1.J10 (TDO_0); also elsewhere on the board
JTAG_TMS: U1.H11 (TMS_0); also elsewhere on the board
MGTPRXN0: U1.A11 (MGTPRXN0_216); also elsewhere on the board
MGTPRXN1: U1.C14 (MGTPRXN1_216); also elsewhere on the board
MGTPRXP0: U1.B11 (MGTPRXP0_216); also elsewhere on the board
MGTPRXP1: U1.D14 (MGTPRXP1_216); also elsewhere on the board
MGTPTXN0: U1.A7 (MGTPTXN0_216); also elsewhere on the board
MGTPTXN1: U1.C8 (MGTPTXN1_216); also elsewhere on the board
MGTPTXP0: U1.B7 (MGTPTXP0_216); also elsewhere on the board
MGTPTXP1: U1.D8 (MGTPTXP1_216); also elsewhere on the board
MGTREFCLK0N: U1.E11 (MGTREFCLK0N_216); also elsewhere on the board
MGTREFCLK0P: U1.F11 (MGTREFCLK0P_216); also elsewhere on the board
MGTRREF: U1.A15 (MGTRREF_216); also elsewhere on the board
MGTRREF_213: U1.AF15 (MGTRREF_213); also elsewhere on the board
PSRAM0_CE_B: U1.N17 (IO_L4N_T0_D05_14); also elsewhere on the board
PSRAM0_IO0: U1.R16 (IO_L5P_T0_D06_14); also elsewhere on the board
PSRAM0_IO1: U1.R17 (IO_L5N_T0_D07_14); also elsewhere on the board
PSRAM0_IO2: U1.K25 (IO_L7P_T1_D09_14); also elsewhere on the board
PSRAM0_IO3: U1.K26 (IO_L7N_T1_D10_14); also elsewhere on the board
PSRAM0_SCK: U1.N16 (IO_L4P_T0_D04_14); also elsewhere on the board
PSRAM1_CE_B: U1.L20 (IO_L8N_T1_D12_14); also elsewhere on the board
PSRAM1_IO0: U1.L24 (IO_L9P_T1_DQS_14); also elsewhere on the board
PSRAM1_IO1: U1.L25 (IO_L9N_T1_DQS_D13_14); also elsewhere on the board
PSRAM1_IO2: U1.M24 (IO_L10P_T1_D14_14); also elsewhere on the board
PSRAM1_IO3: U1.M25 (IO_L10N_T1_D15_14); also elsewhere on the board
PSRAM1_SCK: U1.M20 (IO_L8P_T1_D11_14); also elsewhere on the board
PSRAM2_CE_B: U1.L23 (IO_L11N_T1_SRCC_14); also elsewhere on the board
PSRAM2_IO0: U1.M21 (IO_L12P_T1_MRCC_14); also elsewhere on the board
PSRAM2_IO1: U1.M22 (IO_L12N_T1_MRCC_14); also elsewhere on the board
PSRAM2_IO2: U1.N21 (IO_L13P_T2_MRCC_14); also elsewhere on the board
PSRAM2_IO3: U1.N22 (IO_L13N_T2_MRCC_14); also elsewhere on the board
PSRAM2_SCK: U1.L22 (IO_L11P_T1_SRCC_14); also elsewhere on the board
PSRAM3_CE_B: U1.P21 (IO_L14N_T2_SRCC_14); also elsewhere on the board
PSRAM3_IO0: U1.N23 (IO_L15P_T2_DQS_RDWR_B_14); also elsewhere on the board
PSRAM3_IO1: U1.N24 (IO_L15N_T2_DQS_DOUT_CSO_B_14); also elsewhere on the board
PSRAM3_IO2: U1.P19 (IO_L16P_T2_CSI_B_14); also elsewhere on the board
PSRAM3_IO3: U1.N19 (IO_L16N_T2_A15_D31_14); also elsewhere on the board
PSRAM3_SCK: U1.P20 (IO_L14P_T2_SRCC_14); also elsewhere on the board
PUDC_B: R6.1, U1.P15 (IO_L3P_T0_DQS_PUDC_B_14)
SB_UART_RX: U1.R25 (IO_L19P_T3_A10_D26_14); also elsewhere on the board
SB_UART_TX: U1.P25 (IO_L19N_T3_A09_D25_VREF_14); also elsewhere on the board
SLOTA_IO0: U1.K15 (IO_L1P_T0_AD0P_15); also elsewhere on the board
SLOTA_IO1: U1.J16 (IO_L1N_T0_AD0N_15); also elsewhere on the board
SLOTA_IO2: U1.J14 (IO_L2P_T0_AD8P_15); also elsewhere on the board
SLOTA_IO3: U1.J15 (IO_L2N_T0_AD8N_15); also elsewhere on the board
SLOTA_IO4: U1.K16 (IO_L3P_T0_DQS_AD1P_15); also elsewhere on the board
SLOTA_IO5: U1.K17 (IO_L3N_T0_DQS_AD1N_15); also elsewhere on the board
SLOTA_IO6: U1.M14 (IO_L4P_T0_15); also elsewhere on the board
SLOTA_IO7: U1.L14 (IO_L4N_T0_15); also elsewhere on the board
SLOTA_IO8: U1.M15 (IO_L5P_T0_AD9P_15); also elsewhere on the board
SLOTA_IO9: U1.L15 (IO_L5N_T0_AD9N_15); also elsewhere on the board
SLOTA_IO10: U1.M16 (IO_L6P_T0_15); also elsewhere on the board
SLOTA_IO11: U1.M17 (IO_L6N_T0_VREF_15); also elsewhere on the board
SLOTB_IO0: U1.J19 (IO_L7P_T1_AD2P_15); also elsewhere on the board
SLOTB_IO1: U1.H19 (IO_L7N_T1_AD2N_15); also elsewhere on the board
SLOTB_IO2: U1.L17 (IO_L8P_T1_AD10P_15); also elsewhere on the board
SLOTB_IO3: U1.L18 (IO_L8N_T1_AD10N_15); also elsewhere on the board
SLOTB_IO4: U1.K20 (IO_L9P_T1_DQS_AD3P_15); also elsewhere on the board
SLOTB_IO5: U1.J20 (IO_L9N_T1_DQS_AD3N_15); also elsewhere on the board
SLOTB_IO6: U1.J18 (IO_L10P_T1_AD11P_15); also elsewhere on the board
SLOTB_IO7: U1.H18 (IO_L10N_T1_AD11N_15); also elsewhere on the board
SLOTB_IO8: U1.G20 (IO_L11P_T1_SRCC_15); also elsewhere on the board
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

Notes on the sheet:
FPGA — FPGA, decoupling and configuration straps — HW 0.1.0-proto.1
U1 FPGA
decoupling +1V8
decoupling +3V3
decoupling +1V0_MGT
decoupling +1V2_MGT
decoupling +1V0
decoupling VCCIO_1
decoupling VCCIO_2
bulk +1V0
bulk +1V8
bulk +3V3
bulk VCCIO_1
bulk VCCIO_2
bulk +1V0_MGT
bulk +1V2_MGT
config straps (UG470)

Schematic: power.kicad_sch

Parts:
C183: 100nF 25V; C_0402_1005Metric; LCSC C1525
C184: 2.2nF 25V; C_0402_1005Metric
C185, C186: 22uF 25V; C_0805_2012Metric; LCSC C86816
C187, C192, C215, C216, C232: 10uF 25V; C_0805_2012Metric; LCSC C15850
C188, C193, C200, C203, C206, C225, C226, C227, C228, C229, C230: 100nF; C_0402_1005Metric; LCSC C1525
C189, C190, C191, C195, C196, C197, C198, C199, C201, C202, C204, C205, C207, C211, C212: 22uF; C_0805_2012Metric; LCSC C86816
C194: 56pF; C_0402_1005Metric
C208, C218, C219, C220, C221: 1uF; C_0603_1608Metric; LCSC C29936
C209: 1nF; C_0402_1005Metric
C210: 22pF; C_0402_1005Metric
C213: 2.2nF; C_0402_1005Metric
C214: 10nF; C_0402_1005Metric
C217: 10uF; C_0805_2012Metric; LCSC C15850
C222: 3.3nF 25V; C_0402_1005Metric
C223: 1uF 25V; C_0603_1608Metric; LCSC C29936
C224: 4.7uF; C_0603_1608Metric; LCSC C277476
D3, D4, D5: SS34; SMA_L4.3-W2.6-LS5.2-RD; LCSC C8678
D8: SMBJ15A-13-F; D_SMB; LCSC C135046
J50: 9-14V POWER IN; CONN-TH_P5.00_KF301-5.0-2P; LCSC C474881
L2, L8: 10uH SRN6045TA-100M; IND-SMD_L6.0-W6.0-1; LCSC C2046332
L3: 4.7uH SRN6045TA-4R7M; IND-SMD_L6.0-W6.0; LCSC C2044594
L4, L5, L6: 2.2uH SRN4018-2R2M; IND-SMD_L4.0-W4.0_SNR4018; LCSC C913207
L7: 1uH_core FTC201610S1R0MBCA; IND-SMD_L2.0-W1.6-B; LCSC C5832342
L9: 1uH VLS252010HBX-1R0M-1; IND-SMD_L2.5-W2.0-1; LCSC C88211
Q2: DMG2305UX-7; SOT-23-3_L2.9-W1.3-P1.90-LS2.4-BR; LCSC C5261054
Q3: BSS138LT1G; SOT-23-3_L2.9-W1.6-P1.90-LS2.8-BR; LCSC C82045
R46, R50, R55, R59, R61, R63, R64, R67, R69, R72, R81, R83, R90, R91, R92, R93, R94, R95: 100k; R_0603_1608Metric
R47: 10k; R_0402_1005Metric
R48, R66: 100k; R_0402_1005Metric; LCSC C25741
R49, R51, R84: 47k; R_0603_1608Metric
R52: 73.2k; R_0603_1608Metric
R53, R73: 10k; R_0603_1608Metric
R54: 1.65k; R_0603_1608Metric
R56: 13.7k; R_0603_1608Metric
R57: 93.1k; R_0603_1608Metric
R58: 30.1k; R_0603_1608Metric
R60: 31.6k; R_0603_1608Metric
R62: 49.9k; R_0603_1608Metric
R65: 10; R_0603_1608Metric
R68: 150k; R_0603_1608Metric
R70: 11.5k; R_0603_1608Metric
R71: 47k; R_0402_1005Metric
R74: 1.15k; R_0603_1608Metric
R75, R76, R77: 2.21k; R_0603_1608Metric
R78: 121k; R_0603_1608Metric
R79: 12.1k; R_0603_1608Metric
R80: 6.65k; R_0603_1608Metric
R82: 16k; R_0603_1608Metric
R85, R86, R87, R88: 1k; R_0603_1608Metric
U11: TPS54202DDCR; SOT-23-6_L2.9-W1.6-P0.95-LS2.8-BL; LCSC C191884
U12: AP63300WU-7; TSOT-23-6_L2.9-W1.6-P0.95-LS2.8-BR; LCSC C2158012
U13, U14, U16: TLV62569DRLR; SOT-563_L1.6-W1.2-P0.50-LS1.6-BL; LCSC C163217
U15: SY8047QDC; TQFN-16_L3.0-W3.0-P0.50-TL-EP1.6; LCSC C3018651
U19: TPS61085PWR; TSSOP-8_L4.4-W3.0-P0.65-LS6.4-BL; LCSC C13505
U21, U22, U23, U24: TPS22950CDDCR; SOT-23-6_L2.9-W1.6-P0.95-LS2.8-BL_3; LCSC C7587833
U25: TPS259470LRPWR; Texas_RPU0010A_VQFN-HR-10_2x2mm_P0.5mm; LCSC C3662793
U26: TPS259470ARPWR; Texas_RPU0010A_VQFN-HR-10_2x2mm_P0.5mm; LCSC C3662799

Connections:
+1V0: C210.1, C211.1, C212.1, L7.1, L9.2, R67.1, R88.1; also elsewhere on the board
+1V0_MGT: C224.1, L9.1; also elsewhere on the board
+1V2_MGT: C204.1, C205.1, L6.1, R63.1; also elsewhere on the board
+1V8: C201.1, C202.1, L5.1, R61.1, R87.1; also elsewhere on the board
+2V5: C198.1, C199.1, L4.1, R59.1, R86.1; also elsewhere on the board
+3V3: C194.1, C195.1, C196.1, C197.1, C219.1, L3.1, R57.1, R66.1, R73.1, R85.1, U22.2 (VIN); also elsewhere on the board
+3V3_EXT: U22.5 (VOUT); also elsewhere on the board
+5V: C189.1, C190.1, C191.1, C200.1, C203.1, C206.1, C207.1, C217.1, C218.1, L2.1, L8.1, Q2.3 (D), R55.1, R65.1, R83.1, U13.3 (VIN), U14.3 (VIN), U15.11 (PVIN), U15.12 (PVIN), U16.3 (VIN), U19.6 (VIN), U21.2 (VIN); also elsewhere on the board
+5V_EXT: U21.5 (VOUT); also elsewhere on the board
+12V: C215.1, C216.1, C223.1, D5.1 (K), R69.1, R78.1, U25.5 (IN)
+12V_EXT: C232.1, U25.6 (OUT); also elsewhere on the board
BOOT_3V3: C193.1, U12.6 (BST)
BOOT_5V: C188.1, U11.6 (BOOT)
COMP_12V: R71.1, U19.1 (COMP)
COMP_12V_C: C213.1, R71.2
CORE_1V0_GOOD: R66.2, U15.4 (PG); also elsewhere on the board
CORE_1V0_SS: C209.1, U15.9 (SS)
CORE_1V0_SVIN: C208.1, R65.2, U15.10 (SVIN)
EN_1V0: R94.1, U15.13 (EN); also elsewhere on the board
EN_1V2: R93.1, U16.5 (EN); also elsewhere on the board
EN_1V8: R92.1, U14.5 (EN); also elsewhere on the board
EN_2V5: R91.1, U13.5 (EN); also elsewhere on the board
EN_5V: R90.1, U11.5 (EN); also elsewhere on the board
EN_12V: R95.1, U19.3 (EN); also elsewhere on the board
EN_VBUS5: R47.1; also elsewhere on the board
EN_VBUS5_G: Q3.1 (G), R47.2, R48.1
EXT12_DVDT: C222.1, U25.7 (dVdt)
EXT12_ILM: R80.1, U25.9 (ILM)
EXT12_OVLO: R78.2, R79.1, U25.2 (OVLO)
EXT_EN: R72.1, U21.1 (ON), U22.1 (ON), U23.1 (ON), U24.1 (ON), U25.1 (EN/UVLO); also elsewhere on the board
EXT_FAULT: R73.2, U21.6 (FLT), U22.6 (FLT), U23.6 (FLT), U24.6 (FLT), U25.4 (FLT), U26.4 (FLT); also elsewhere on the board
FB+1V0: C210.2, R67.2, R68.1, U15.5 (FB)
FB+1V2_MGT: R63.2, R64.1, U16.1 (FB)
FB+1V8: R61.2, R62.1, U14.1 (FB)
FB+2V5: R59.2, R60.1, U13.1 (FB)
FB_3V3: C194.2, R57.2, R58.1, U12.1 (FB)
FB_5V: R55.2, R56.1, U11.4 (FB)
FB_12V: R69.2, R70.1, U19.2 (FB)
GND: C184.2, C185.2, C186.2, C187.2, C189.2, C190.2, C191.2, C192.2, C195.2, C196.2, C197.2, C198.2, C199.2, C200.2, C201.2, C202.2, C203.2, C204.2, C205.2, C206.2, C207.2, C208.2, C209.2, C211.2, C212.2, C213.2, C214.2, C215.2, C216.2, C217.2, C218.2, C219.2, C220.2, C221.2, C222.2, C223.2, C224.2, C225.2, C226.2, C227.2, C228.2, C229.2, C230.2, C232.2, D8.2 (A), J50.2, Q3.2 (S), R48.2, R51.2, R53.2, R54.2, R56.2, R58.2, R60.2, R62.2, R64.2, R68.2, R70.2, R72.2, R74.2, R75.2, R76.2, R77.2, R79.2, R80.2, R82.2, R84.2, R90.2, R91.2, R92.2, R93.2, R94.2, R95.2, U11.1 (GND), U12.4 (GND), U13.2 (GND), U14.2 (GND), U15.6 (AGND), U15.14 (PGND), U15.15 (PGND), U15.17 (EP), U16.2 (GND), U19.4 (GND), U19.7 (FREQ), U21.3 (GND), U22.3 (GND), U23.3 (GND), U24.3 (GND), U25.8 (GND), U26.8 (GND); also elsewhere on the board
MON_1V0: C230.1, R88.2; also elsewhere on the board
MON_1V8: C229.1, R87.2; also elsewhere on the board
MON_2V5: C228.1, R86.2; also elsewhere on the board
MON_3V3: C227.1, R85.2; also elsewhere on the board
MON_5V: C226.1, R83.2, R84.1; also elsewhere on the board
MON_VSYS: C225.1, R81.2, R82.1; also elsewhere on the board
SS_12V: C214.1, U19.8 (SS)
SW+1V0: L7.2, U15.1 (LX), U15.2 (LX)
SW+1V2_MGT: L6.2, U16.4 (SW)
SW+1V8: L5.2, U14.4 (SW)
SW+2V5: L4.2, U13.4 (SW)
SW_3V3: C193.2, L3.2, U12.5 (SW)
SW_5V: C188.2, L2.2, U11.2 (SW)
SW_12V: D5.2 (A), L8.2, U19.5 (SW)
U21_ILIM: R74.1, U21.4 (ILIM)
U22_ILIM: R75.1, U22.4 (ILIM)
U23_ILIM: R76.1, U23.4 (ILIM)
U24_ILIM: R77.1, U24.4 (ILIM)
VBUS: C183.2, C187.1, Q2.2 (S), R46.1, R50.1, R52.1, U26.5 (IN); also elsewhere on the board
VBUS5_GATE: C183.1, Q2.1 (G), R46.2, R49.2
VBUS5_PULL: Q3.3 (D), R49.1
VBUS_DVDT: C184.1, U26.7 (dVdt)
VBUS_ILM: R54.1, U26.9 (ILM)
VBUS_OVLO: R52.2, R53.1, U26.2 (OVLO)
VBUS_SS: D3.2 (A), U26.6 (OUT)
VBUS_UVLO: R50.2, R51.1, U26.1 (EN/UVLO)
VCCIO_1: C220.1, U23.2 (VIN); also elsewhere on the board
VCCIO_1_EXT: U23.5 (VOUT); also elsewhere on the board
VCCIO_2: C221.1, U24.2 (VIN); also elsewhere on the board
VCCIO_2_EXT: U24.5 (VOUT); also elsewhere on the board
VIN_EXT: D4.2 (A), D8.1 (K), J50.1
VSYS: C185.1, C186.1, C192.1, D3.1 (K), D4.1 (K), R81.1, U11.3 (VIN), U12.3 (VIN)

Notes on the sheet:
POWER — Power tree: 12V input to every rail, with monitoring — HW 0.1.0-proto.1
VBUS pass switch to +5V
input OR-ing
U11 12V to 5V
U12 VSYS to +3V3 (always-on AP63300 reference circuit)
U13 5V to +2V5
U14 5V to +1V8
U16 5V to +1V2_MGT
U15 5V to +1V0 (4A FPGA core supply)
U19 5V to 12V boost (AUX)
extension power protection control
U21 +5V to +5V_EXT
U22 +3V3 to +3V3_EXT
U23 VCCIO_1 to VCCIO_1_EXT
U24 VCCIO_2 to VCCIO_2_EXT
U25 +12V to +12V_EXT
MGTAVCC filter
rail monitors
Power flags for the rails made on this page

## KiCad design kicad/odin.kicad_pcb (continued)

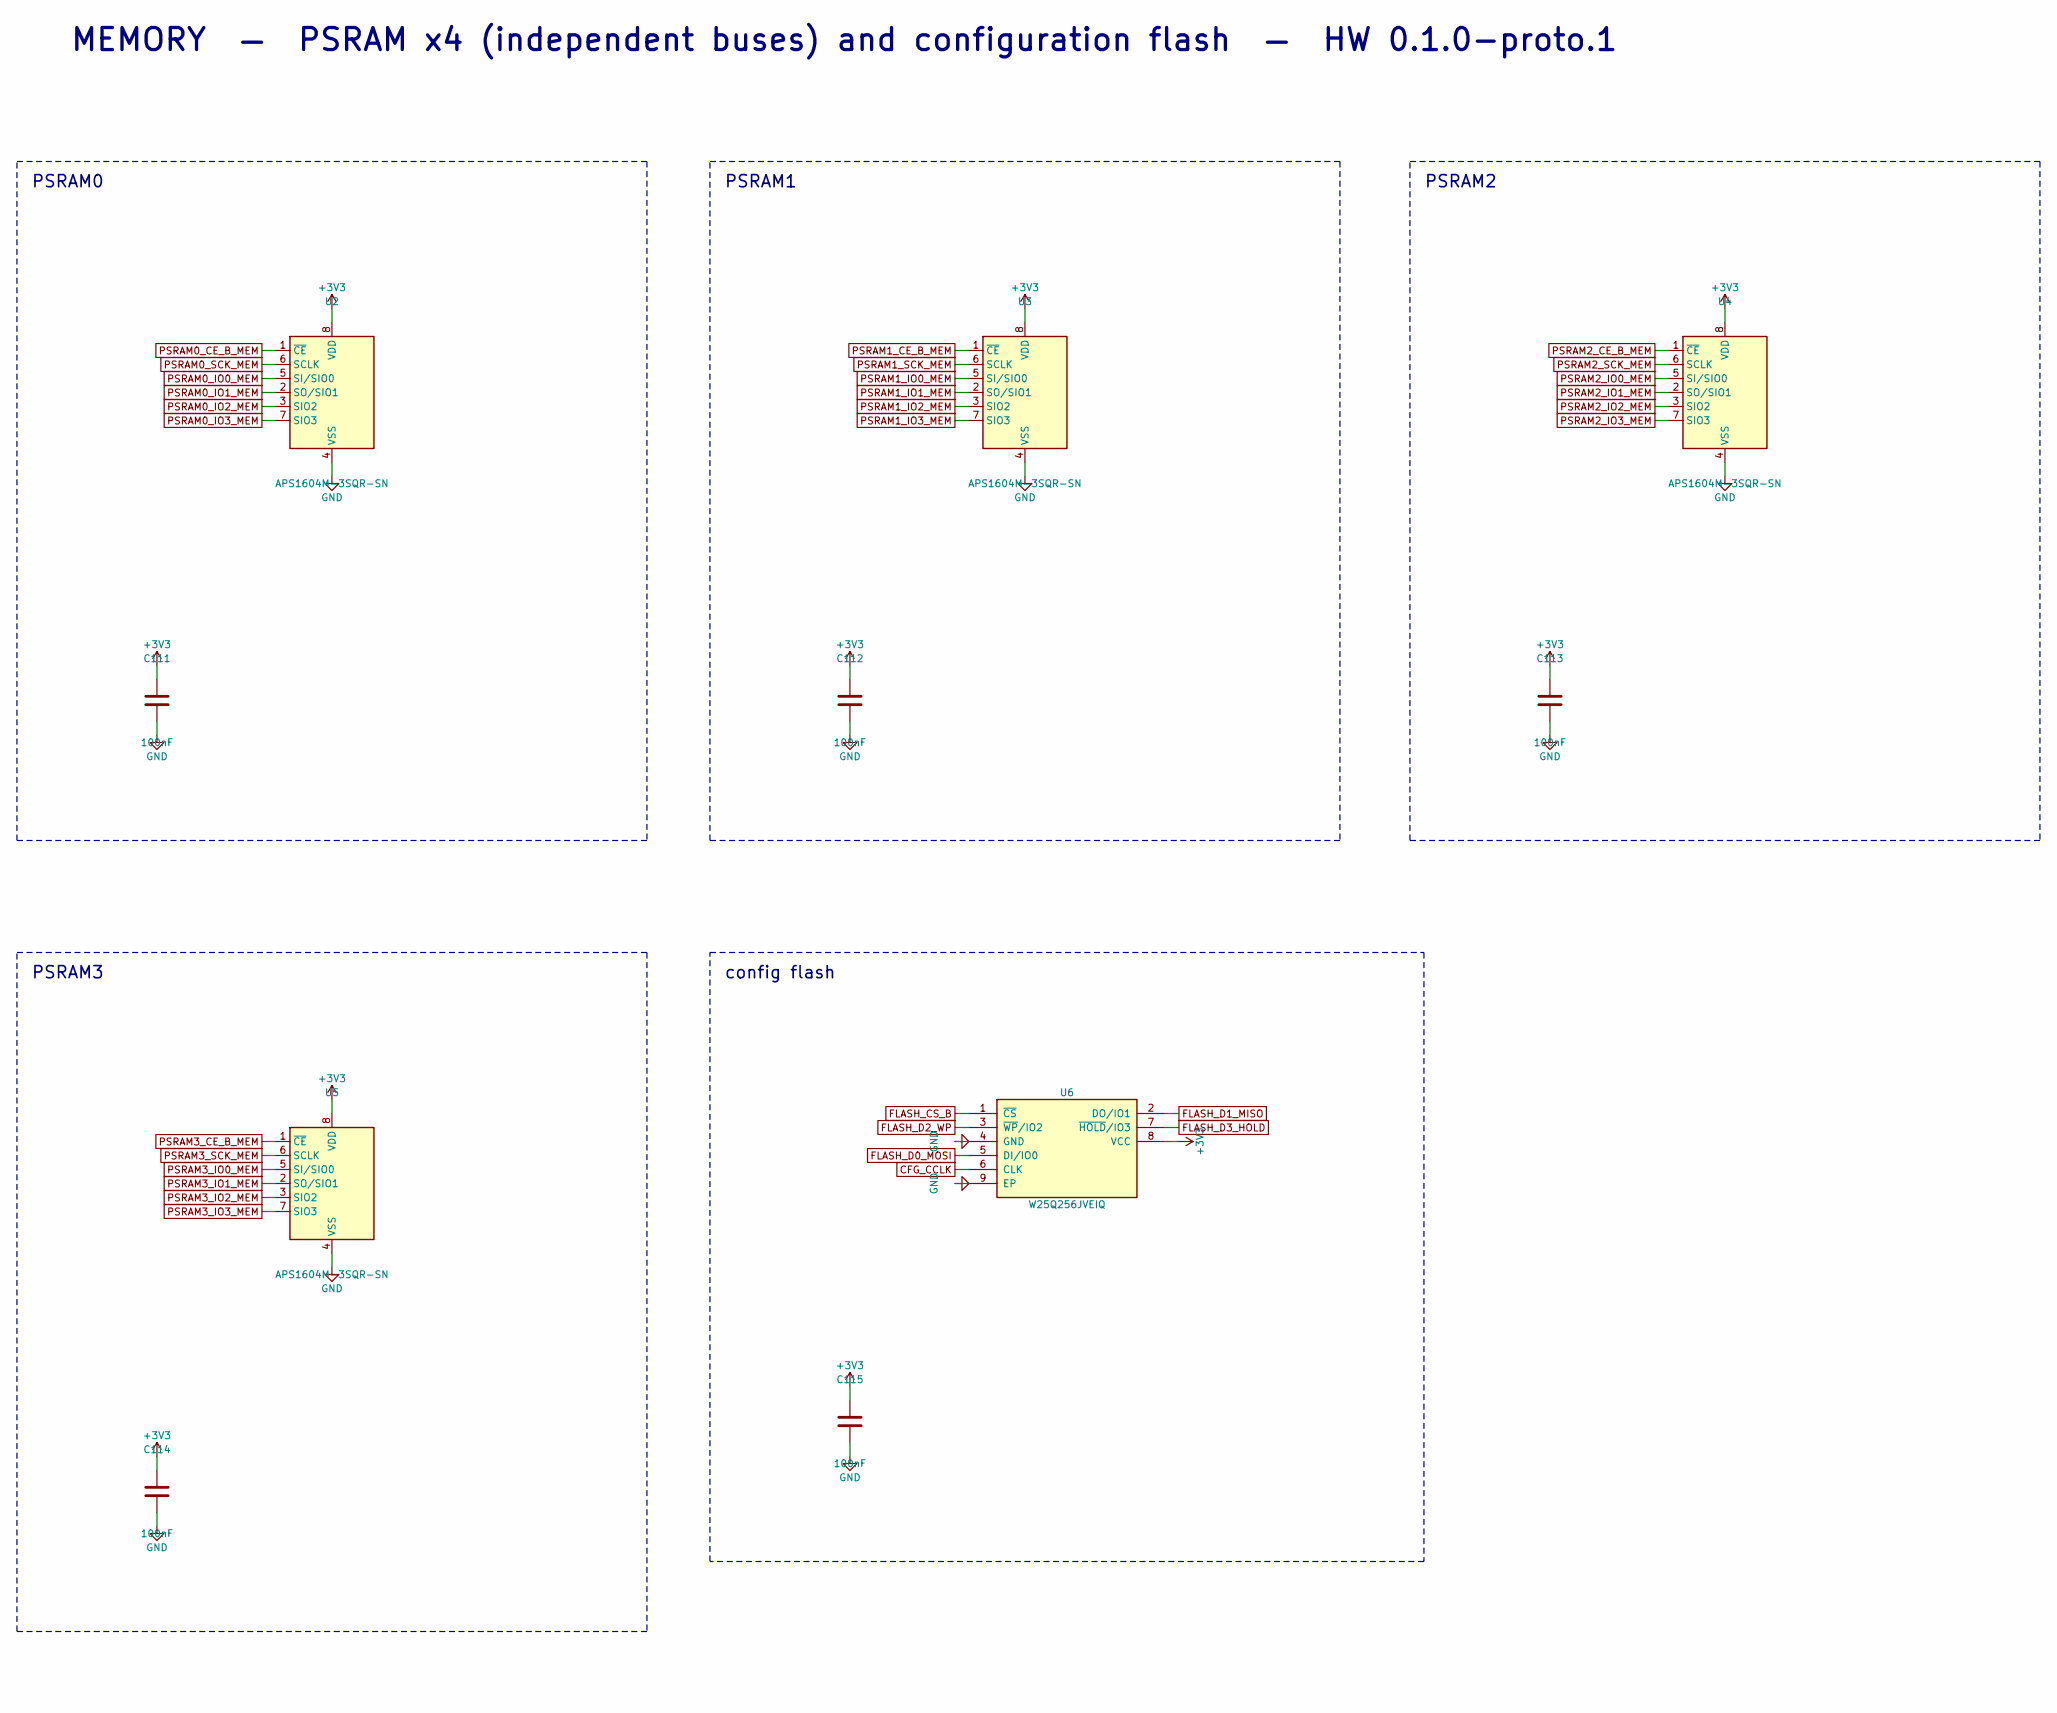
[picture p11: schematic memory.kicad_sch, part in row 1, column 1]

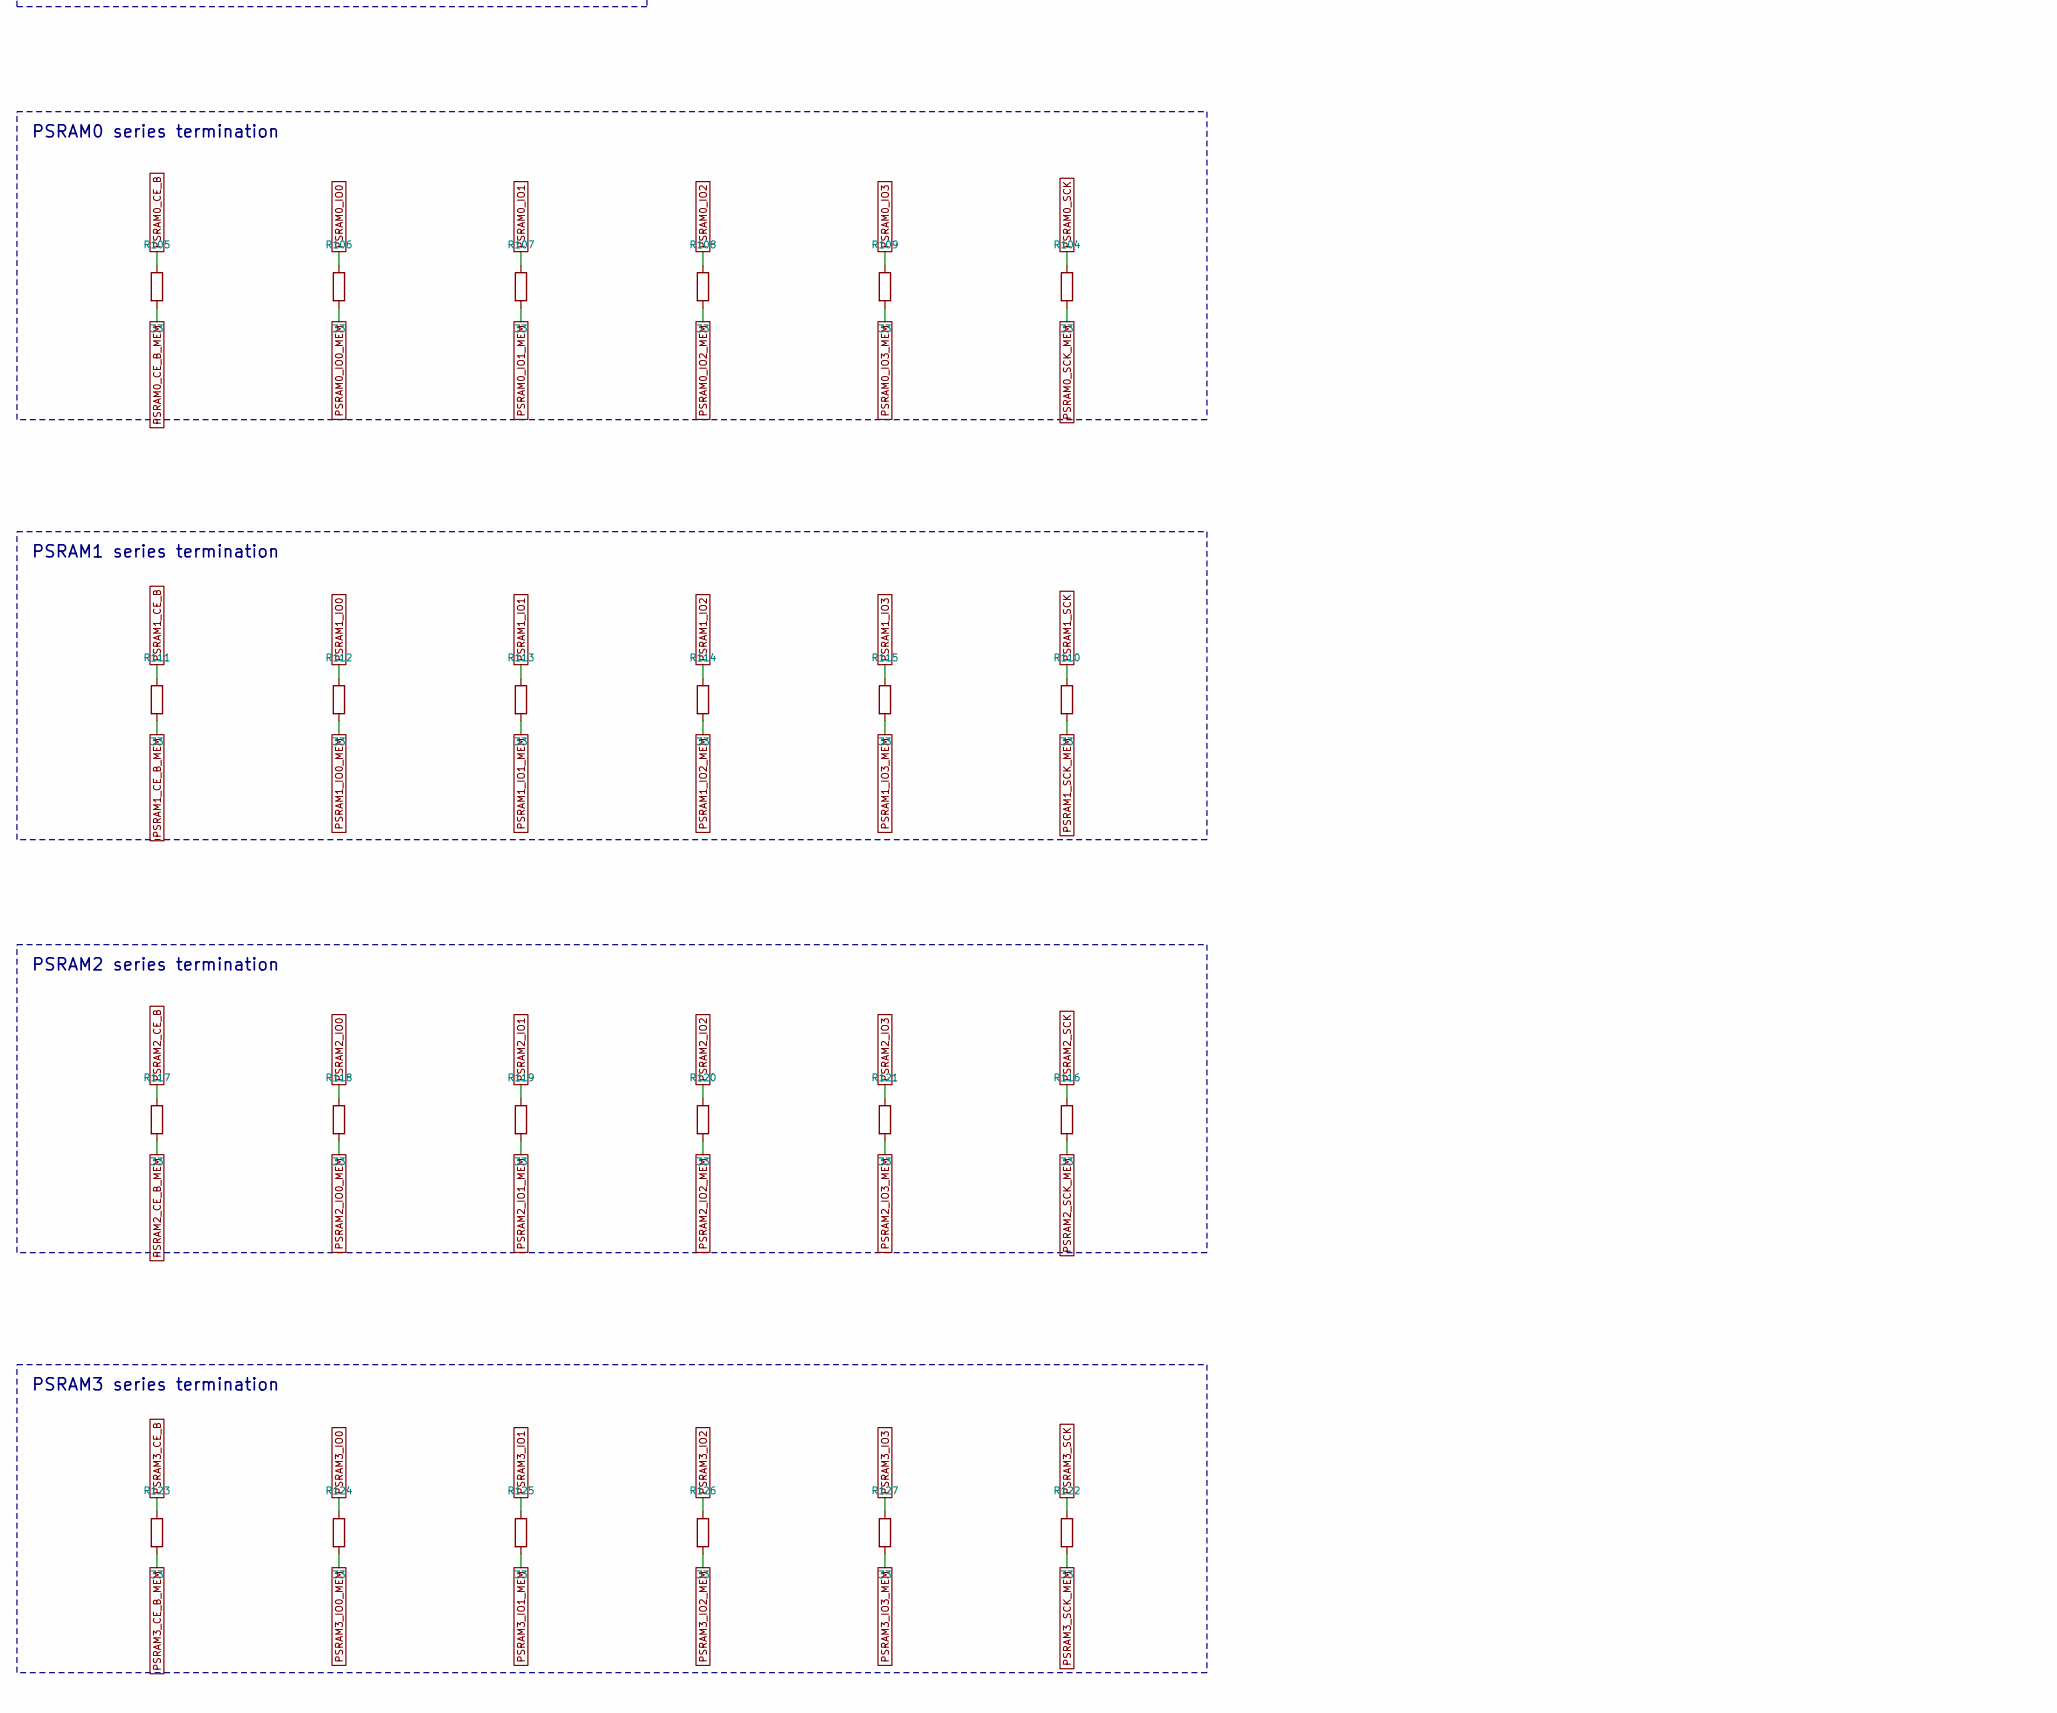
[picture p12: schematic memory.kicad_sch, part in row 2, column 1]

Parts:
C111, C112, C113, C114, C115: 100nF; C_0402_1005Metric; LCSC C1525
R104, R105, R106, R107, R108, R109, R110, R111, R112, R113, R114, R115, R116, R117, R118, R119, R120, R121, R122, R123, R124, R125, R126, R127: 33; R_0402_1005Metric; LCSC C25105
U2, U3, U4, U5: APS1604M-3SQR-SN; SOIC-8_L4.9-W3.9-P1.27-LS6.0-BL; LCSC C18214056
U6: W25Q256JVEIQ; WSON-8_L8.0-W6.10-P1.27-BL-EP; LCSC C97522

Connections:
+3V3: C111.1, C112.1, C113.1, C114.1, C115.1, U2.8 (VDD), U3.8 (VDD), U4.8 (VDD), U5.8 (VDD), U6.8 (VCC); also elsewhere on the board
CFG_CCLK: U6.6 (CLK); also elsewhere on the board
FLASH_CS_B: U6.1 (~CS); also elsewhere on the board
FLASH_D0_MOSI: U6.5 (DI/IO0); also elsewhere on the board
FLASH_D1_MISO: U6.2 (DO/IO1); also elsewhere on the board
FLASH_D2_WP: U6.3 (~WP/IO2); also elsewhere on the board
FLASH_D3_HOLD: U6.7 (~HOLD/IO3); also elsewhere on the board
GND: C111.2, C112.2, C113.2, C114.2, C115.2, U2.4 (VSS), U3.4 (VSS), U4.4 (VSS), U5.4 (VSS), U6.4 (GND), U6.9 (EP); also elsewhere on the board
PSRAM0_CE_B: R105.1; also elsewhere on the board
PSRAM0_CE_B_MEM: R105.2, U2.1 (~CE)
PSRAM0_IO0: R106.1; also elsewhere on the board
PSRAM0_IO0_MEM: R106.2, U2.5 (SI/SIO0)
PSRAM0_IO1: R107.1; also elsewhere on the board
PSRAM0_IO1_MEM: R107.2, U2.2 (SO/SIO1)
PSRAM0_IO2: R108.1; also elsewhere on the board
PSRAM0_IO2_MEM: R108.2, U2.3 (SIO2)
PSRAM0_IO3: R109.1; also elsewhere on the board
PSRAM0_IO3_MEM: R109.2, U2.7 (SIO3)
PSRAM0_SCK: R104.1; also elsewhere on the board
PSRAM0_SCK_MEM: R104.2, U2.6 (SCLK)
PSRAM1_CE_B: R111.1; also elsewhere on the board
PSRAM1_CE_B_MEM: R111.2, U3.1 (~CE)
PSRAM1_IO0: R112.1; also elsewhere on the board
PSRAM1_IO0_MEM: R112.2, U3.5 (SI/SIO0)
PSRAM1_IO1: R113.1; also elsewhere on the board
PSRAM1_IO1_MEM: R113.2, U3.2 (SO/SIO1)
PSRAM1_IO2: R114.1; also elsewhere on the board
PSRAM1_IO2_MEM: R114.2, U3.3 (SIO2)
PSRAM1_IO3: R115.1; also elsewhere on the board
PSRAM1_IO3_MEM: R115.2, U3.7 (SIO3)
PSRAM1_SCK: R110.1; also elsewhere on the board
PSRAM1_SCK_MEM: R110.2, U3.6 (SCLK)
PSRAM2_CE_B: R117.1; also elsewhere on the board
PSRAM2_CE_B_MEM: R117.2, U4.1 (~CE)
PSRAM2_IO0: R118.1; also elsewhere on the board
PSRAM2_IO0_MEM: R118.2, U4.5 (SI/SIO0)
PSRAM2_IO1: R119.1; also elsewhere on the board
PSRAM2_IO1_MEM: R119.2, U4.2 (SO/SIO1)
PSRAM2_IO2: R120.1; also elsewhere on the board
PSRAM2_IO2_MEM: R120.2, U4.3 (SIO2)
PSRAM2_IO3: R121.1; also elsewhere on the board
PSRAM2_IO3_MEM: R121.2, U4.7 (SIO3)
PSRAM2_SCK: R116.1; also elsewhere on the board
PSRAM2_SCK_MEM: R116.2, U4.6 (SCLK)
PSRAM3_CE_B: R123.1; also elsewhere on the board
PSRAM3_CE_B_MEM: R123.2, U5.1 (~CE)
PSRAM3_IO0: R124.1; also elsewhere on the board
PSRAM3_IO0_MEM: R124.2, U5.5 (SI/SIO0)
PSRAM3_IO1: R125.1; also elsewhere on the board
PSRAM3_IO1_MEM: R125.2, U5.2 (SO/SIO1)
PSRAM3_IO2: R126.1; also elsewhere on the board
PSRAM3_IO2_MEM: R126.2, U5.3 (SIO2)
PSRAM3_IO3: R127.1; also elsewhere on the board
PSRAM3_IO3_MEM: R127.2, U5.7 (SIO3)
PSRAM3_SCK: R122.1; also elsewhere on the board
PSRAM3_SCK_MEM: R122.2, U5.6 (SCLK)

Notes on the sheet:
MEMORY — PSRAM x4 (independent buses) and configuration flash — HW 0.1.0-proto.1
PSRAM0
PSRAM1
PSRAM2
PSRAM3
config flash
PSRAM0 series termination
PSRAM1 series termination
PSRAM2 series termination
PSRAM3 series termination

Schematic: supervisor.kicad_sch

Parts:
C116, C117, C118, C119, C120, C121, C122, C123, C124, C125, C126, C127, C128, C129, C135, C136, C138: 100nF; C_0402_1005Metric; LCSC C1525
C130, C131, C132: 4.7uF; C_0603_1608Metric; LCSC C277476
C133, C134: 15pF; C_0402_1005Metric
C137: 1uF; C_0402_1005Metric
D6: ESDA6V1BC6; SOT-23-6_L2.9-W1.6-P0.95-LS2.8-BR; LCSC C495220
D7: SMBJ13A-TR; SMB_L4.6-W3.6-LS5.3-RD; LCSC C133675
J1: USB-C; USB_C_Receptacle_HCTL_HC-TYPE-C-16P-01A; LCSC C2894897
J2: FPGA JTAG; IDC-TH_10P-P2.54_C5665; LCSC C5665
J51: CTRL SWD; CONN-SMD-3P-P1.00_BM03B-SRSS-TB-LF-SN; LCSC C160389
J52: PZ254V-11-02P; HDR-TH_2P-P2.54-V-M; LCSC C492401
L1: 3.3uH AOTA-B201610S3R3-101-T; IND-SMD_L2.0-W1.6_AOTA-B201610S3R3-101-T; LCSC C42411119
R8, R14, R15, R16, R17, R18, R19, R20, R21, R22, R23, R24, R25, R26, R27, R28, R29, R30, R31, R32: 33; R_0402_1005Metric; LCSC C25105
R9, R10, R12: 1k; R_0402_1005Metric; LCSC C11702
R11: 10k; R_0402_1005Metric
R13: 10k; R_0402_1005Metric; not fitted
R33: 0; R_0402_1005Metric
R34: 10k; R_0603_1608Metric
SW1: CTRL BOOT; KEY-SMD_B3U-1000PM; LCSC C231329
U7: RP2350B; QFN-80_L10.0-W10.0-P0.40-TL-EP3.4; LCSC C42415655
U8: W25Q32JVZP; WSON-8_L6.0-W5.0-P1.27-BL-EP; LCSC C571260
U18: CH224K; ESSOP-10_L4.9-W3.9-P1.0-LS6.0-TL-EP; LCSC C970725
U20: SN74CB3Q3384APWR; TSSOP-24_L7.8-W4.4-P0.65-LS6.4-BL; LCSC C469874
Y1: 12MHz ABM8-272-T3; CRYSTAL-SMD_4P-L3.2-W2.5-BL; LCSC C20625731

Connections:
+1V1: C127.1, C128.1, C129.1, C131.1, L1.1, U7.10 (DVDD), U7.32 (DVDD), U7.51 (DVDD), U7.65 (VREG_FB)
+3V3: C116.1, C117.1, C118.1, C119.1, C120.1, C121.1, C122.1, C123.1, C124.1, C125.1, C126.1, C130.1, C136.1, C138.1, J2.1, J52.1, R8.1, R10.1, R11.1, R13.1, U7.5 (IOVDD), U7.15 (IOVDD), U7.24 (IOVDD), U7.29 (IOVDD), U7.41 (IOVDD), U7.50 (IOVDD), U7.59 (ADC_AVDD), U7.60 (IOVDD), U7.64 (VREG_VIN), U7.68 (USB_OTP_VDD), U7.69 (QSPI_IOVDD), U7.76 (IOVDD), U8.8 (VCC), U20.13 (~2OE), U20.24 (VCC); also elsewhere on the board
BOOTSEL_SW: R12.2, SW1.1
CFG_CCLK: R21.2; also elsewhere on the board
CFG_DONE: R20.2; also elsewhere on the board
CFG_INIT_B: R19.2; also elsewhere on the board
CFG_PROG_B: R18.2; also elsewhere on the board
DBG_TCK: R27.2; also elsewhere on the board
DBG_TDI: R29.2; also elsewhere on the board
DBG_TDO: R30.2; also elsewhere on the board
DBG_TMS: R28.2; also elsewhere on the board
EN_1V0: U7.25 (GPIO24); also elsewhere on the board
EN_1V2: U7.26 (GPIO25); also elsewhere on the board
EN_1V8: U7.23 (GPIO23); also elsewhere on the board
EN_2V5: U7.22 (GPIO22); also elsewhere on the board
EN_5V: U7.27 (GPIO26); also elsewhere on the board
EN_12V: U7.57 (GPIO46/ADC6); also elsewhere on the board
EN_VBUS5: U7.21 (GPIO21); also elsewhere on the board
EXTERNAL_JTAG_SELECTED: J52.2, R34.1, U20.1 (~1OE)
EXT_EN: U7.6 (GPIO8); also elsewhere on the board
EXT_FAULT: U7.58 (GPIO47/ADC7); also elsewhere on the board
FLASH_CS_B: R22.2; also elsewhere on the board
FLASH_D0_MOSI: R23.2; also elsewhere on the board
FLASH_D1_MISO: R24.2; also elsewhere on the board
FLASH_D2_WP: R25.2; also elsewhere on the board
FLASH_D3_HOLD: R26.2; also elsewhere on the board
GND: C116.2, C117.2, C118.2, C119.2, C120.2, C121.2, C122.2, C123.2, C124.2, C125.2, C126.2, C127.2, C128.2, C129.2, C130.2, C131.2, C132.2, C133.2, C134.2, C135.2, C136.2, C137.2, C138.2, D6.2 (COM), D6.5 (COM), D7.2 (A), J1.A1 (GND), J1.A12 (GND), J1.B1 (GND), J1.B12 (GND), J1.S1 (SHIELD), J2.2, J2.4, J2.6, J2.8, J2.10, J51.2, R34.2, SW1.2, U7.62 (VREG_PGND), U7.81 (GND), U8.4 (GND), U8.9 (EP), U18.11 (GND), U20.12 (GND), Y1.2 (G), Y1.4 (G); also elsewhere on the board
JTAG_TCK: J2.5, U20.2 (1B1); also elsewhere on the board
JTAG_TDI: J2.9, U20.6 (1B3); also elsewhere on the board
JTAG_TDO: J2.7, R33.2; also elsewhere on the board
JTAG_TDO_SW: R33.1, U20.9 (1B4)
JTAG_TMS: J2.3, U20.5 (1B2); also elsewhere on the board
MON_1V0: U7.56 (GPIO45/ADC5); also elsewhere on the board
MON_1V8: U7.55 (GPIO44/ADC4); also elsewhere on the board
MON_2V5: U7.54 (GPIO43/ADC3); also elsewhere on the board
MON_3V3: U7.53 (GPIO42/ADC2); also elsewhere on the board
MON_5V: U7.52 (GPIO41/ADC1); also elsewhere on the board
MON_VSYS: U7.49 (GPIO40/ADC0); also elsewhere on the board
PD_CFG1: U7.28 (GPIO27), U18.9 (CFG1)
PD_CFG2: U7.36 (GPIO28), U18.2 (CFG2)
PD_CFG3: U7.37 (GPIO29), U18.3 (CFG3)
PD_PG: R11.2, U7.38 (GPIO30), U18.10 (PG)
PD_VDD: C137.1, U18.1 (VDD)
SB_UART_RX: R31.2; also elsewhere on the board
SB_UART_TX: R32.2; also elsewhere on the board
SFP0_LOS: U7.44 (GPIO35); also elsewhere on the board
SFP0_MOD_ABS: U7.40 (GPIO32); also elsewhere on the board
SFP0_TX_DIS: U7.42 (GPIO33); also elsewhere on the board
SFP0_TX_FAULT: U7.43 (GPIO34); also elsewhere on the board
SFP1_LOS: U7.48 (GPIO39); also elsewhere on the board
SFP1_MOD_ABS: U7.45 (GPIO36); also elsewhere on the board
SFP1_TX_DIS: U7.46 (GPIO37); also elsewhere on the board
SFP1_TX_FAULT: U7.47 (GPIO38); also elsewhere on the board
SFP_SCL: U7.13 (GPIO14); also elsewhere on the board
SFP_SDA: U7.39 (GPIO31); also elsewhere on the board
SUPF_CLK: U7.71 (QSPI_SCLK), U8.6 (CLK)
SUPF_CS: R12.1, R13.2, U7.75 (~QSPI_SS), U8.1 (~CS)
SUPF_D0: U7.72 (QSPI_SD0), U8.5 (DI/IO_{0})
SUPF_D1: U7.74 (QSPI_SD1), U8.2 (DO/IO_{1})
SUPF_D2: U7.73 (QSPI_SD2), U8.3 (~WP/IO_{2})
SUPF_D3: U7.70 (QSPI_SD3), U8.7 (~HOLD/~RESET/IO_{3})
SUP_CCLK: R21.1, U7.4 (GPIO7)
SUP_DBG_TCK: R27.1, U7.14 (GPIO15)
SUP_DBG_TDI: R29.1, U7.17 (GPIO17)
SUP_DBG_TDO: R30.1, U7.18 (GPIO18)
SUP_DBG_TMS: R28.1, U7.16 (GPIO16)
SUP_DONE: R20.1, U7.3 (GPIO6)
SUP_FCS_B: R22.1, U7.7 (GPIO9)
SUP_FD0: R23.1, U7.8 (GPIO10)
SUP_FD1: R24.1, U7.9 (GPIO11)
SUP_FD2: R25.1, U7.11 (GPIO12)
SUP_FD3: R26.1, U7.12 (GPIO13)
SUP_INIT_B: R19.1, U7.2 (GPIO5)
SUP_JTAG_TCK: R14.1, U7.77 (GPIO0)
SUP_JTAG_TDI: R16.1, U7.79 (GPIO2)
SUP_JTAG_TDO: R17.1, U7.80 (GPIO3)
SUP_JTAG_TMS: R15.1, U7.78 (GPIO1)
SUP_LX: L1.2, U7.63 (VREG_LX)
SUP_PROG_B: R18.1, U7.1 (GPIO4)
SUP_RUN: C135.1, R10.2, U7.35 (RUN); also elsewhere on the board
SUP_SWCLK: J51.1, U7.33 (SWCLK)
SUP_SWDIO: J51.3, U7.34 (SWDIO)
SUP_UART_RX: R32.1, U7.20 (GPIO20)
SUP_UART_TX: R31.1, U7.19 (GPIO19)
SUP_VREG_AVDD: C132.1, R8.2, U7.61 (VREG_AVDD)
SUP_XIN: C133.1, U7.30 (XIN), Y1.1
SUP_XOUT: R9.1, U7.31 (XOUT)
SUP_XTAL_OUT: C134.1, R9.2, Y1.3
SWJ_TCK: R14.2, U20.3 (1A1)
SWJ_TDI: R16.2, U20.7 (1A3)
SWJ_TDO: R17.2, U20.8 (1A4)
SWJ_TMS: R15.2, U20.4 (1A2)
USB_CC1: D6.4 (TVS3), J1.A5 (CC1), U18.7 (CC1)
USB_CC2: D6.6 (TVS4), J1.B5 (CC2), U18.6 (CC2)
USB_DM: D6.3 (TVS2), J1.A7 (D-), J1.B7 (D-), U7.66 (USB_DM)
USB_DP: D6.1 (TVS1), J1.A6 (D+), J1.B6 (D+), U7.67 (USB_DP)
VBUS: D7.1 (K), J1.A4 (VBUS), J1.A9 (VBUS), J1.B4 (VBUS), J1.B9 (VBUS), U18.8 (VBUS); also elsewhere on the board

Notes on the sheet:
SUPERVISOR — Board controller: RP2350B, USB-C, startup memory and FPGA control — HW 0.1.0-proto.1
U7 board controller
U7 core regulator (RP-008280 s2.1)
crystal (RP-008280 s4)
RUN
board controller startup memory
USB-C
USB protection
USB-PD sink
BOOTSEL
board controller SWD
series resistors to FPGA
JTAG owner selection
manual JTAG header
Power flags for the rails made on this page

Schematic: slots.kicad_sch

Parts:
C139, C140, C141, C142, C144, C146, C148, C150, C152, C154, C156, C158, C160, C162: 100nF; C_0402_1005Metric; LCSC C1525
C143, C145, C147, C149, C151, C153, C155, C157, C159, C161: 10uF; C_0805_2012Metric; LCSC C15850
C163, C164, C165, C166: 22uF; C_0805_2012Metric; LCSC C86816
F1, F2, F5, F6, F9, F10, F13, F14, F17, F18, F21, F22, F25, F26, F29, F30, F33, F34, F37, F38: 500mA; F1206; LCSC C269115
F3, F7, F11, F15, F19, F23, F27, F31, F35, F39: 300mA; F1206; LCSC C22378340
F4, F8, F12, F16, F20, F24, F28, F32, F36, F40: 200mA; F1206; LCSC C269111
J3, J4, J5, J6: PM254-2-16-S-8.5; HDR-SMD_32P-P2.54-V-F-R2-C16-LS7.1; LCSC C3975161
J7, J8: PM254-2-08-S-8.5; HDR-SMD_16P-P2.54-V-F-R2-C8-LS7.1; LCSC C3975153
J10, J11, J12, J13, J14, J15, J16, J17, J18, J19, J20, J21: 2.54-2*3P; HDR-TH_6P-P2.54-V-M-R2-C3-S2.54-1; LCSC C65114
J53, J54, J55, J56: ZX-PM2.54-1-16PY; HDR-TH_16P-P2.54-V-F-1; LCSC C7499334
J57, J58: 2.54-1*8P; HDR-TH_8P-P2.54-V-F; LCSC C27438
MK65, MK66, MK67, MK68, MK69, MK70, MK71, MK72, MK76, MK77: PH2.54-1X1P-H25; HDR-TH_1P-P2.54-V-M; LCSC C42431799
R96, R97: 10k; R_0603_1608Metric
U9, U10: SN74LXC8T245PWR; TSSOP-24_L7.8-W4.4-P0.65-LS6.4-BL_1; LCSC C4363995

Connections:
+1V8: J19.5, J20.5; also elsewhere on the board
+2V5: J19.3, J20.3; also elsewhere on the board
+3V3: C139.1, C141.1, J19.1, J20.1, R96.1, R97.1, U9.1 (VCCA), U10.1 (VCCA); also elsewhere on the board
+3V3_EXT: F1.1, F3.1, F5.1, F7.1, F11.1, F15.1, F19.1, F23.1, F27.1, F31.1, F35.1, F39.1, J10.5, J11.5, J12.5, J13.5, J14.5, J15.5, J16.5, J17.5, J18.5, J21.5; also elsewhere on the board
+5V: C140.1, C142.1, U9.23 (VCCB), U9.24 (VCCB), U10.23 (VCCB), U10.24 (VCCB); also elsewhere on the board
+5V_EXT: F2.1, F6.1, F10.1, F14.1, F18.1, F22.1, F26.1, F30.1, F34.1, F38.1, J10.3, J11.3, J12.3, J13.3, J14.3, J15.3, J16.3, J17.3, J18.3, J21.3; also elsewhere on the board
+12V_EXT: J10.1, J11.1, J12.1, J13.1, J14.1, J15.1, J16.1, J17.1, J18.1, J21.1; also elsewhere on the board
BUS5V0_DIR: U9.2 (DIR); also elsewhere on the board
BUS5V0_IO0: U9.3 (A1); also elsewhere on the board
BUS5V0_IO1: U9.4 (A2); also elsewhere on the board
BUS5V0_IO2: U9.5 (A3); also elsewhere on the board
BUS5V0_IO3: U9.6 (A4); also elsewhere on the board
BUS5V0_IO4: U9.7 (A5); also elsewhere on the board
BUS5V0_IO5: U9.8 (A6); also elsewhere on the board
BUS5V0_IO6: U9.9 (A7); also elsewhere on the board
BUS5V0_IO7: U9.10 (A8); also elsewhere on the board
BUS5V0_OE_N: R96.2, U9.22 (~OE); also elsewhere on the board
BUS5V0_PIN0: J7.1, U9.21 (B1)
BUS5V0_PIN1: J7.2, U9.20 (B2)
BUS5V0_PIN2: J7.3, U9.19 (B3)
BUS5V0_PIN3: J7.4, U9.18 (B4)
BUS5V0_PIN4: J7.5, U9.17 (B5)
BUS5V0_PIN5: J7.6, U9.16 (B6)
BUS5V0_PIN6: J7.7, U9.15 (B7)
BUS5V0_PIN7: J7.8, U9.14 (B8)
BUS5V1_DIR: U10.2 (DIR); also elsewhere on the board
BUS5V1_IO0: U10.3 (A1); also elsewhere on the board
BUS5V1_IO1: U10.4 (A2); also elsewhere on the board
BUS5V1_IO2: U10.5 (A3); also elsewhere on the board
BUS5V1_IO3: U10.6 (A4); also elsewhere on the board
BUS5V1_IO4: U10.7 (A5); also elsewhere on the board
BUS5V1_IO5: U10.8 (A6); also elsewhere on the board
BUS5V1_IO6: U10.9 (A7); also elsewhere on the board
BUS5V1_IO7: U10.10 (A8); also elsewhere on the board
BUS5V1_OE_N: R97.2, U10.22 (~OE); also elsewhere on the board
BUS5V1_PIN0: J8.1, U10.21 (B1)
BUS5V1_PIN1: J8.2, U10.20 (B2)
BUS5V1_PIN2: J8.3, U10.19 (B3)
BUS5V1_PIN3: J8.4, U10.18 (B4)
BUS5V1_PIN4: J8.5, U10.17 (B5)
BUS5V1_PIN5: J8.6, U10.16 (B6)
BUS5V1_PIN6: J8.7, U10.15 (B7)
BUS5V1_PIN7: J8.8, U10.14 (B8)
GND: C139.2, C140.2, C141.2, C142.2, C143.2, C144.2, C145.2, C146.2, C147.2, C148.2, C149.2, C150.2, C151.2, C152.2, C153.2, C154.2, C155.2, C156.2, C157.2, C158.2, C159.2, C160.2, C161.2, C162.2, C163.2, C164.2, C165.2, C166.2, J3.7, J3.8, J3.15, J3.16, J3.17, J3.18, J3.25, J3.26, J4.7, J4.8, J4.15, J4.16, J4.17, J4.18, J4.25, J4.26, J5.7, J5.8, J5.15, J5.16, J5.17, J5.18, J5.25, J5.26, J6.7, J6.8, J6.15, J6.16, J6.17, J6.18, J6.25, J6.26, J7.9, J7.10, J7.11, J7.12, J7.13, J7.14, J7.15, J7.16, J8.9, J8.10, J8.11, J8.12, J8.13, J8.14, J8.15, J8.16, J53.1, J53.3, J53.5, J53.7, J53.9, J53.11, J53.13, J53.15, J54.1, J54.3, J54.5, J54.7, J54.9, J54.11, J54.13, J54.15, J55.1, J55.3, J55.5, J55.7, J55.9, J55.11, J55.13, J55.15, J56.1, J56.3, J56.5, J56.7, J56.9, J56.11, J56.13, J56.15, J57.1, J57.3, J57.5, J57.7, J58.1, J58.3, J58.5, J58.7, MK65.1, MK66.1, MK67.1, MK68.1, MK69.1, MK70.1, MK71.1, MK72.1, MK76.1, MK77.1, U9.11 (GND), U9.12 (GND), U9.13 (GND), U10.11 (GND), U10.12 (GND), U10.13 (GND); also elsewhere on the board
SLOTA_IO0: J3.1; also elsewhere on the board
SLOTA_IO1: J3.32; also elsewhere on the board
SLOTA_IO2: J3.2; also elsewhere on the board
SLOTA_IO3: J3.31; also elsewhere on the board
SLOTA_IO4: J3.3; also elsewhere on the board
SLOTA_IO5: J3.30; also elsewhere on the board
SLOTA_IO6: J3.4; also elsewhere on the board
SLOTA_IO7: J3.29; also elsewhere on the board
SLOTA_IO8: J3.5; also elsewhere on the board
SLOTA_IO9: J3.28; also elsewhere on the board
SLOTA_IO10: J3.6; also elsewhere on the board
SLOTA_IO11: J3.27; also elsewhere on the board
SLOTB_IO0: J3.9; also elsewhere on the board
SLOTB_IO1: J3.24; also elsewhere on the board
SLOTB_IO2: J3.10; also elsewhere on the board
SLOTB_IO3: J3.23; also elsewhere on the board
SLOTB_IO4: J3.11; also elsewhere on the board
SLOTB_IO5: J3.22; also elsewhere on the board
SLOTB_IO6: J3.12; also elsewhere on the board
SLOTB_IO7: J3.21; also elsewhere on the board
SLOTB_IO8: J3.13; also elsewhere on the board
SLOTB_IO9: J3.20; also elsewhere on the board
SLOTB_IO10: J3.14; also elsewhere on the board
SLOTB_IO11: J3.19; also elsewhere on the board
SLOTC_IO0: J4.1; also elsewhere on the board
SLOTC_IO1: J4.32; also elsewhere on the board
SLOTC_IO2: J4.2; also elsewhere on the board
SLOTC_IO3: J4.31; also elsewhere on the board
SLOTC_IO4: J4.3; also elsewhere on the board
SLOTC_IO5: J4.30; also elsewhere on the board
SLOTC_IO6: J4.4; also elsewhere on the board
SLOTC_IO7: J4.29; also elsewhere on the board
SLOTC_IO8: J4.5; also elsewhere on the board
SLOTC_IO9: J4.28; also elsewhere on the board
SLOTC_IO10: J4.6; also elsewhere on the board
SLOTC_IO11: J4.27; also elsewhere on the board
SLOTD_IO0: J4.9; also elsewhere on the board
SLOTD_IO1: J4.24; also elsewhere on the board
SLOTD_IO2: J4.10; also elsewhere on the board
SLOTD_IO3: J4.23; also elsewhere on the board
SLOTD_IO4: J4.11; also elsewhere on the board
SLOTD_IO5: J4.22; also elsewhere on the board
SLOTD_IO6: J4.12; also elsewhere on the board
SLOTD_IO7: J4.21; also elsewhere on the board
SLOTD_IO8: J4.13; also elsewhere on the board
SLOTD_IO9: J4.20; also elsewhere on the board
SLOTD_IO10: J4.14; also elsewhere on the board
SLOTD_IO11: J4.19; also elsewhere on the board
SLOTE_IO0: J5.1; also elsewhere on the board
SLOTE_IO1: J5.32; also elsewhere on the board
SLOTE_IO2: J5.2; also elsewhere on the board
SLOTE_IO3: J5.31; also elsewhere on the board
SLOTE_IO4: J5.3; also elsewhere on the board
SLOTE_IO5: J5.30; also elsewhere on the board
SLOTE_IO6: J5.4; also elsewhere on the board
SLOTE_IO7: J5.29; also elsewhere on the board
SLOTE_IO8: J5.5; also elsewhere on the board
SLOTE_IO9: J5.28; also elsewhere on the board
SLOTE_IO10: J5.6; also elsewhere on the board
SLOTE_IO11: J5.27; also elsewhere on the board
SLOTF_IO0: J5.9; also elsewhere on the board
SLOTF_IO1: J5.24; also elsewhere on the board
SLOTF_IO2: J5.10; also elsewhere on the board
SLOTF_IO3: J5.23; also elsewhere on the board
SLOTF_IO4: J5.11; also elsewhere on the board
SLOTF_IO5: J5.22; also elsewhere on the board
SLOTF_IO6: J5.12; also elsewhere on the board
SLOTF_IO7: J5.21; also elsewhere on the board
SLOTF_IO8: J5.13; also elsewhere on the board
SLOTF_IO9: J5.20; also elsewhere on the board
SLOTF_IO10: J5.14; also elsewhere on the board
SLOTF_IO11: J5.19; also elsewhere on the board
SLOTG_IO0: J6.1; also elsewhere on the board
SLOTG_IO1: J6.32; also elsewhere on the board
SLOTG_IO2: J6.2; also elsewhere on the board
SLOTG_IO3: J6.31; also elsewhere on the board
SLOTG_IO4: J6.3; also elsewhere on the board
SLOTG_IO5: J6.30; also elsewhere on the board
SLOTG_IO6: J6.4; also elsewhere on the board
SLOTG_IO7: J6.29; also elsewhere on the board
SLOTG_IO8: J6.5; also elsewhere on the board
SLOTG_IO9: J6.28; also elsewhere on the board
SLOTG_IO10: J6.6; also elsewhere on the board
SLOTG_IO11: J6.27; also elsewhere on the board
SLOTH_IO0: J6.9; also elsewhere on the board
SLOTH_IO1: J6.24; also elsewhere on the board
SLOTH_IO2: J6.10; also elsewhere on the board
SLOTH_IO3: J6.23; also elsewhere on the board
SLOTH_IO4: J6.11; also elsewhere on the board
SLOTH_IO5: J6.22; also elsewhere on the board
SLOTH_IO6: J6.12; also elsewhere on the board
SLOTH_IO7: J6.21; also elsewhere on the board
SLOTH_IO8: J6.13; also elsewhere on the board
SLOTH_IO9: J6.20; also elsewhere on the board
SLOTH_IO10: J6.14; also elsewhere on the board
SLOTH_IO11: J6.19; also elsewhere on the board
SLOT_A_3V3: C148.1, F11.2, J53.4
SLOT_A_5V: F10.2, J53.6
SLOT_A_PIN_VOLTAGE: C147.1, F9.2, J53.2
SLOT_A_POWER: F12.2, J53.8
SLOT_A_POWER_SELECTED: F12.1, J11.2, J11.4, J11.6
SLOT_B_3V3: C150.1, F15.2, J53.12
SLOT_B_5V: F14.2, J53.14
SLOT_B_PIN_VOLTAGE: C149.1, F13.2, J53.10
SLOT_B_POWER: F16.2, J53.16
SLOT_B_POWER_SELECTED: F16.1, J12.2, J12.4, J12.6
SLOT_C_3V3: C152.1, F19.2, J54.4
SLOT_C_5V: F18.2, J54.6
SLOT_C_PIN_VOLTAGE: C151.1, F17.2, J54.2
SLOT_C_POWER: F20.2, J54.8
SLOT_C_POWER_SELECTED: F20.1, J13.2, J13.4, J13.6
SLOT_D_3V3: C154.1, F23.2, J54.12
SLOT_D_5V: F22.2, J54.14
SLOT_D_PIN_VOLTAGE: C153.1, F21.2, J54.10
SLOT_D_POWER: F24.2, J54.16
SLOT_D_POWER_SELECTED: F24.1, J14.2, J14.4, J14.6
SLOT_E_3V3: C156.1, F27.2, J55.4
SLOT_E_5V: F26.2, J55.6
SLOT_E_PIN_VOLTAGE: C155.1, F25.2, J55.2
SLOT_E_POWER: F28.2, J55.8
SLOT_E_POWER_SELECTED: F28.1, J15.2, J15.4, J15.6
SLOT_F_3V3: C158.1, F31.2, J55.12
SLOT_F_5V: F30.2, J55.14
SLOT_F_PIN_VOLTAGE: C157.1, F29.2, J55.10
SLOT_F_POWER: F32.2, J55.16
SLOT_F_POWER_SELECTED: F32.1, J16.2, J16.4, J16.6
SLOT_G_3V3: C160.1, F35.2, J56.4
SLOT_G_5V: F34.2, J56.6
SLOT_G_PIN_VOLTAGE: C159.1, F33.2, J56.2
SLOT_G_POWER: F36.2, J56.8
SLOT_G_POWER_SELECTED: F36.1, J17.2, J17.4, J17.6
SLOT_H_3V3: C162.1, F39.2, J56.12
SLOT_H_5V: F38.2, J56.14
SLOT_H_PIN_VOLTAGE: C161.1, F37.2, J56.10
SLOT_H_POWER: F40.2, J56.16
SLOT_H_POWER_SELECTED: F40.1, J18.2, J18.4, J18.6
SLOT_L_3V3: C144.1, F3.2, J57.4
SLOT_L_5V: F2.2, J57.6
SLOT_L_PIN_VOLTAGE: C143.1, F1.2, J57.2
SLOT_L_POWER: F4.2, J57.8
SLOT_L_POWER_SELECTED: F4.1, J10.2, J10.4, J10.6
SLOT_M_3V3: C146.1, F7.2, J58.4
SLOT_M_5V: F6.2, J58.6
SLOT_M_PIN_VOLTAGE: C145.1, F5.2, J58.2
SLOT_M_POWER: F8.2, J58.8
SLOT_M_POWER_SELECTED: F8.1, J21.2, J21.4, J21.6
VCCIO_1: C163.1, C164.1, J19.2, J19.4, J19.6; also elsewhere on the board
VCCIO_1_EXT: F9.1, F13.1, F17.1, F21.1; also elsewhere on the board
VCCIO_2: C165.1, C166.1, J20.2, J20.4, J20.6; also elsewhere on the board
VCCIO_2_EXT: F25.1, F29.1, F33.1, F37.1; also elsewhere on the board

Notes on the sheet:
SLOTS — Ten extension ports, rail selection, fusing, level shifting — HW 0.1.0-proto.1
5V BUS 0 converter
5V BUS 1 converter
SHIELD HEADER AB
SHIELD HEADER CD
SHIELD HEADER EF
SHIELD HEADER GH
SLOT L branches
SLOT M branches
SLOT A branches
SLOT B branches
SLOT C branches
SLOT D branches
SLOT E branches
SLOT F branches
SLOT G branches
SLOT H branches
VCCIO_1 selector
VCCIO_2 selector
Power flags for the rails made on this page

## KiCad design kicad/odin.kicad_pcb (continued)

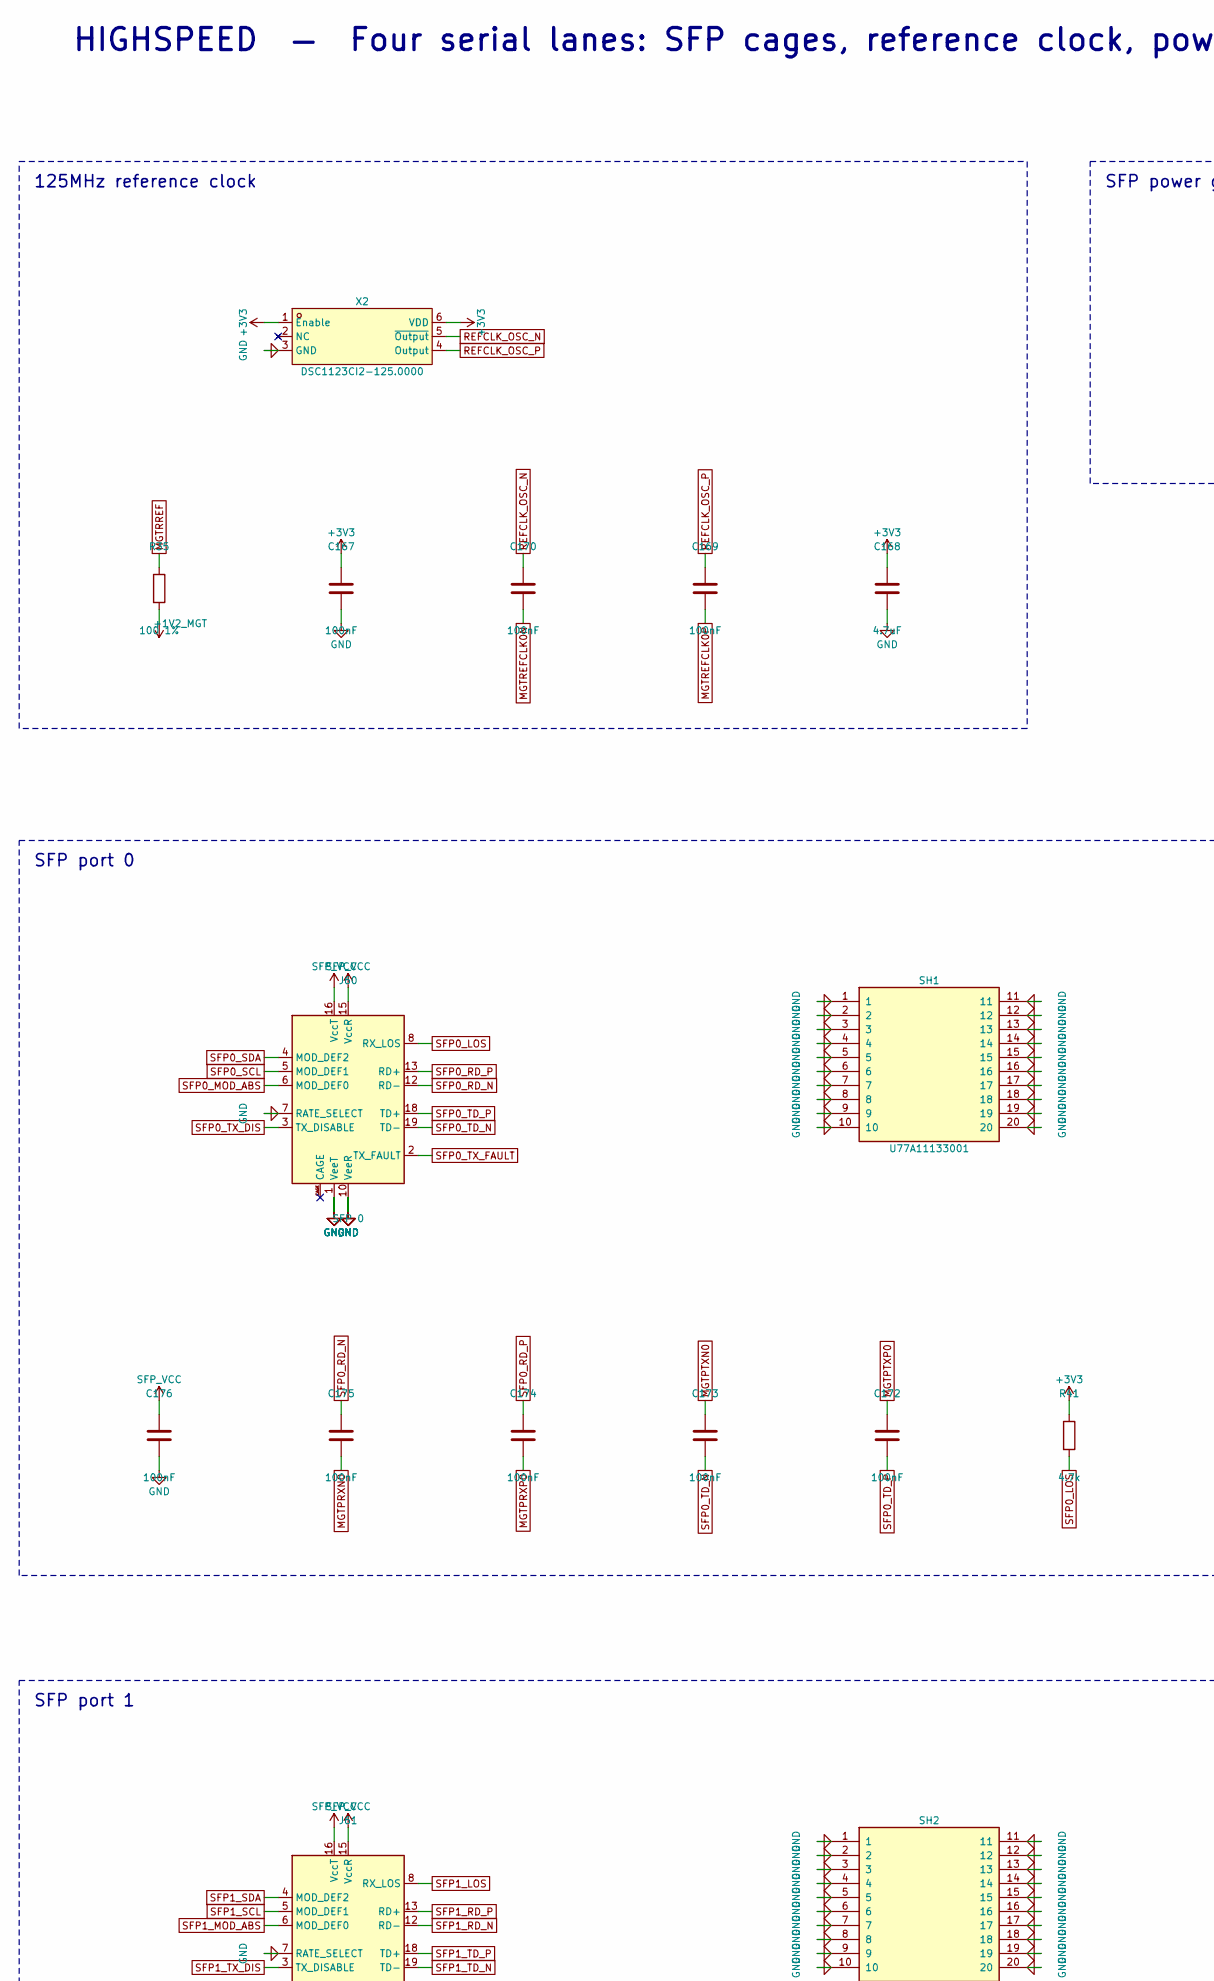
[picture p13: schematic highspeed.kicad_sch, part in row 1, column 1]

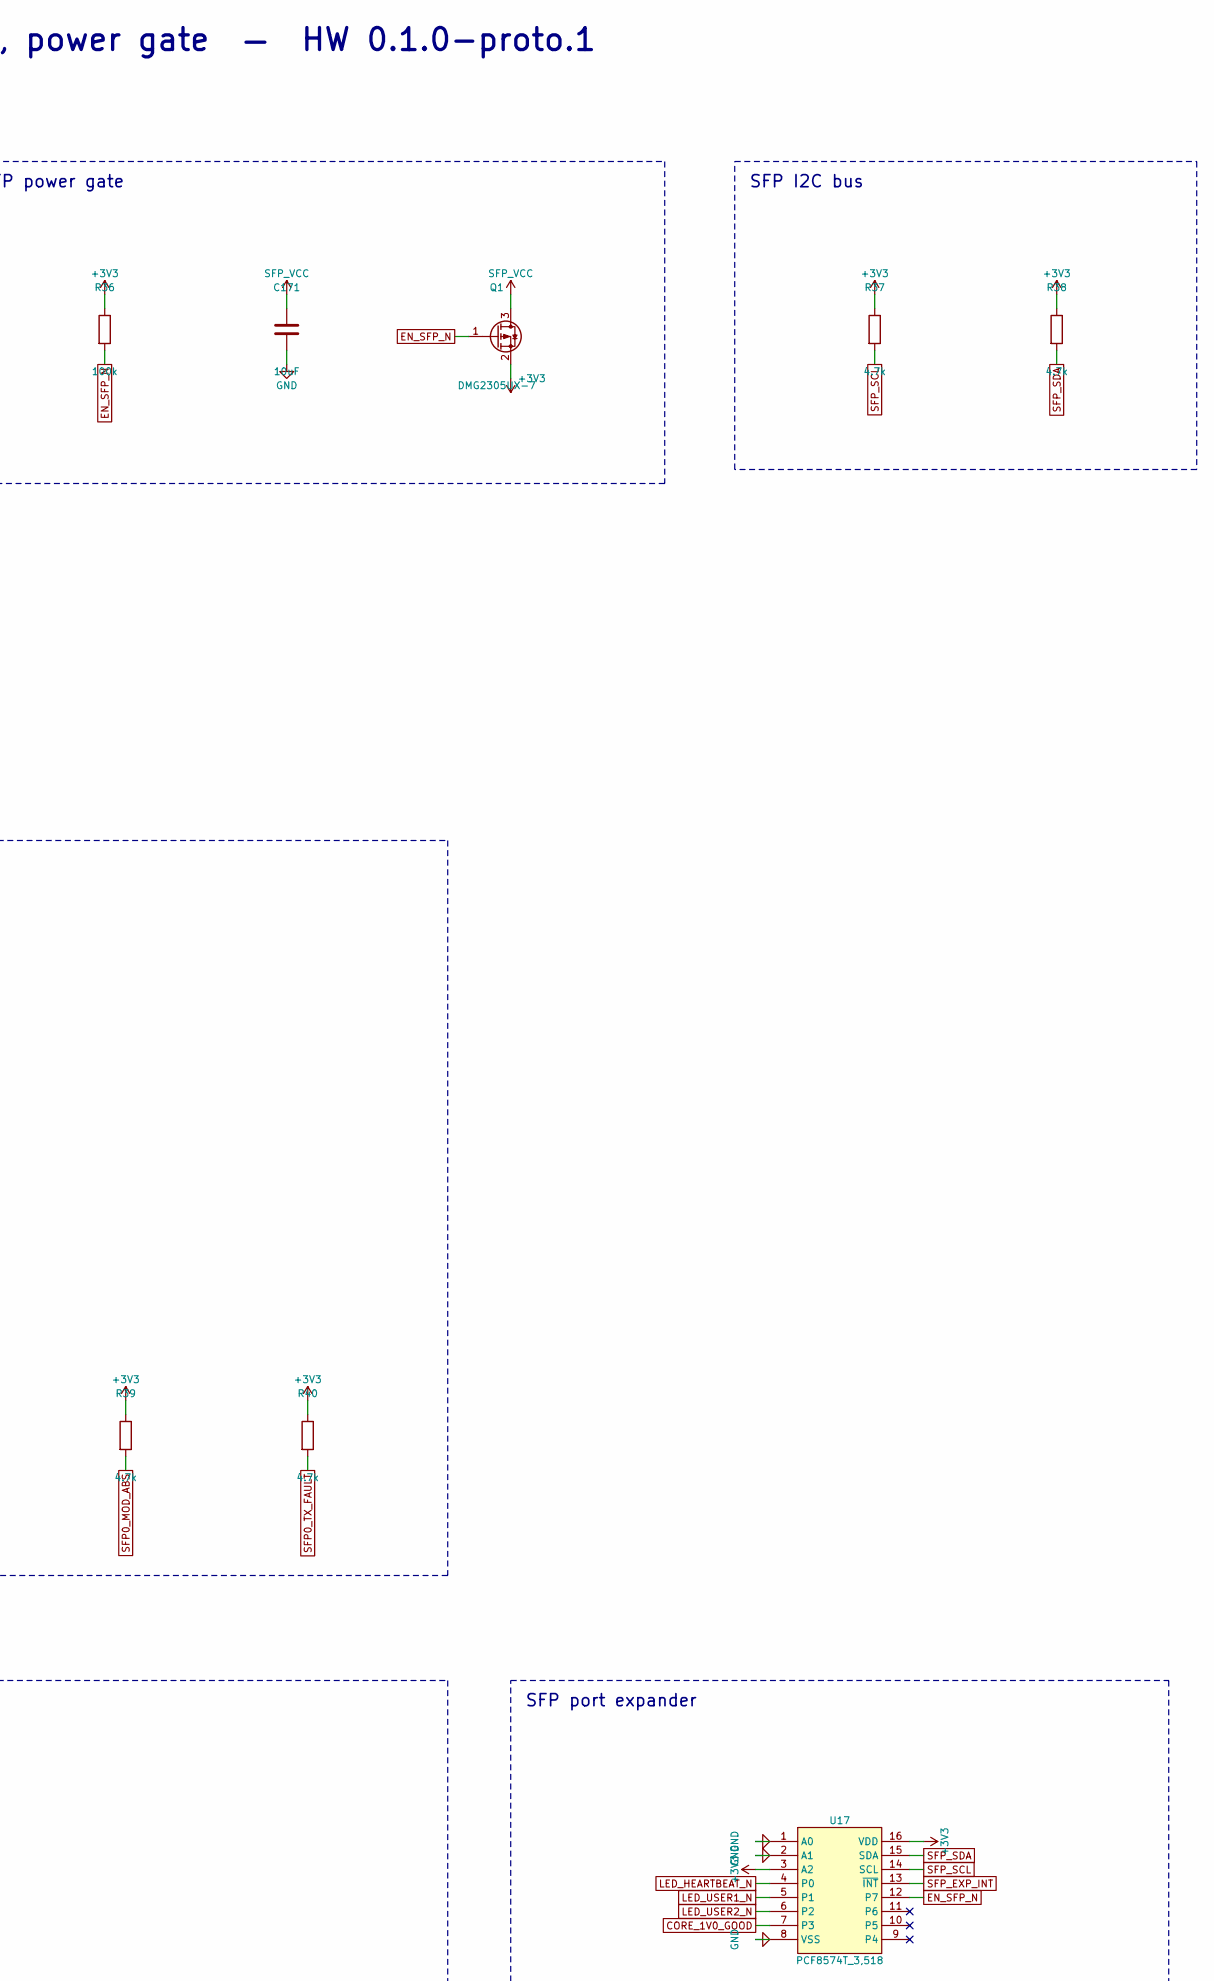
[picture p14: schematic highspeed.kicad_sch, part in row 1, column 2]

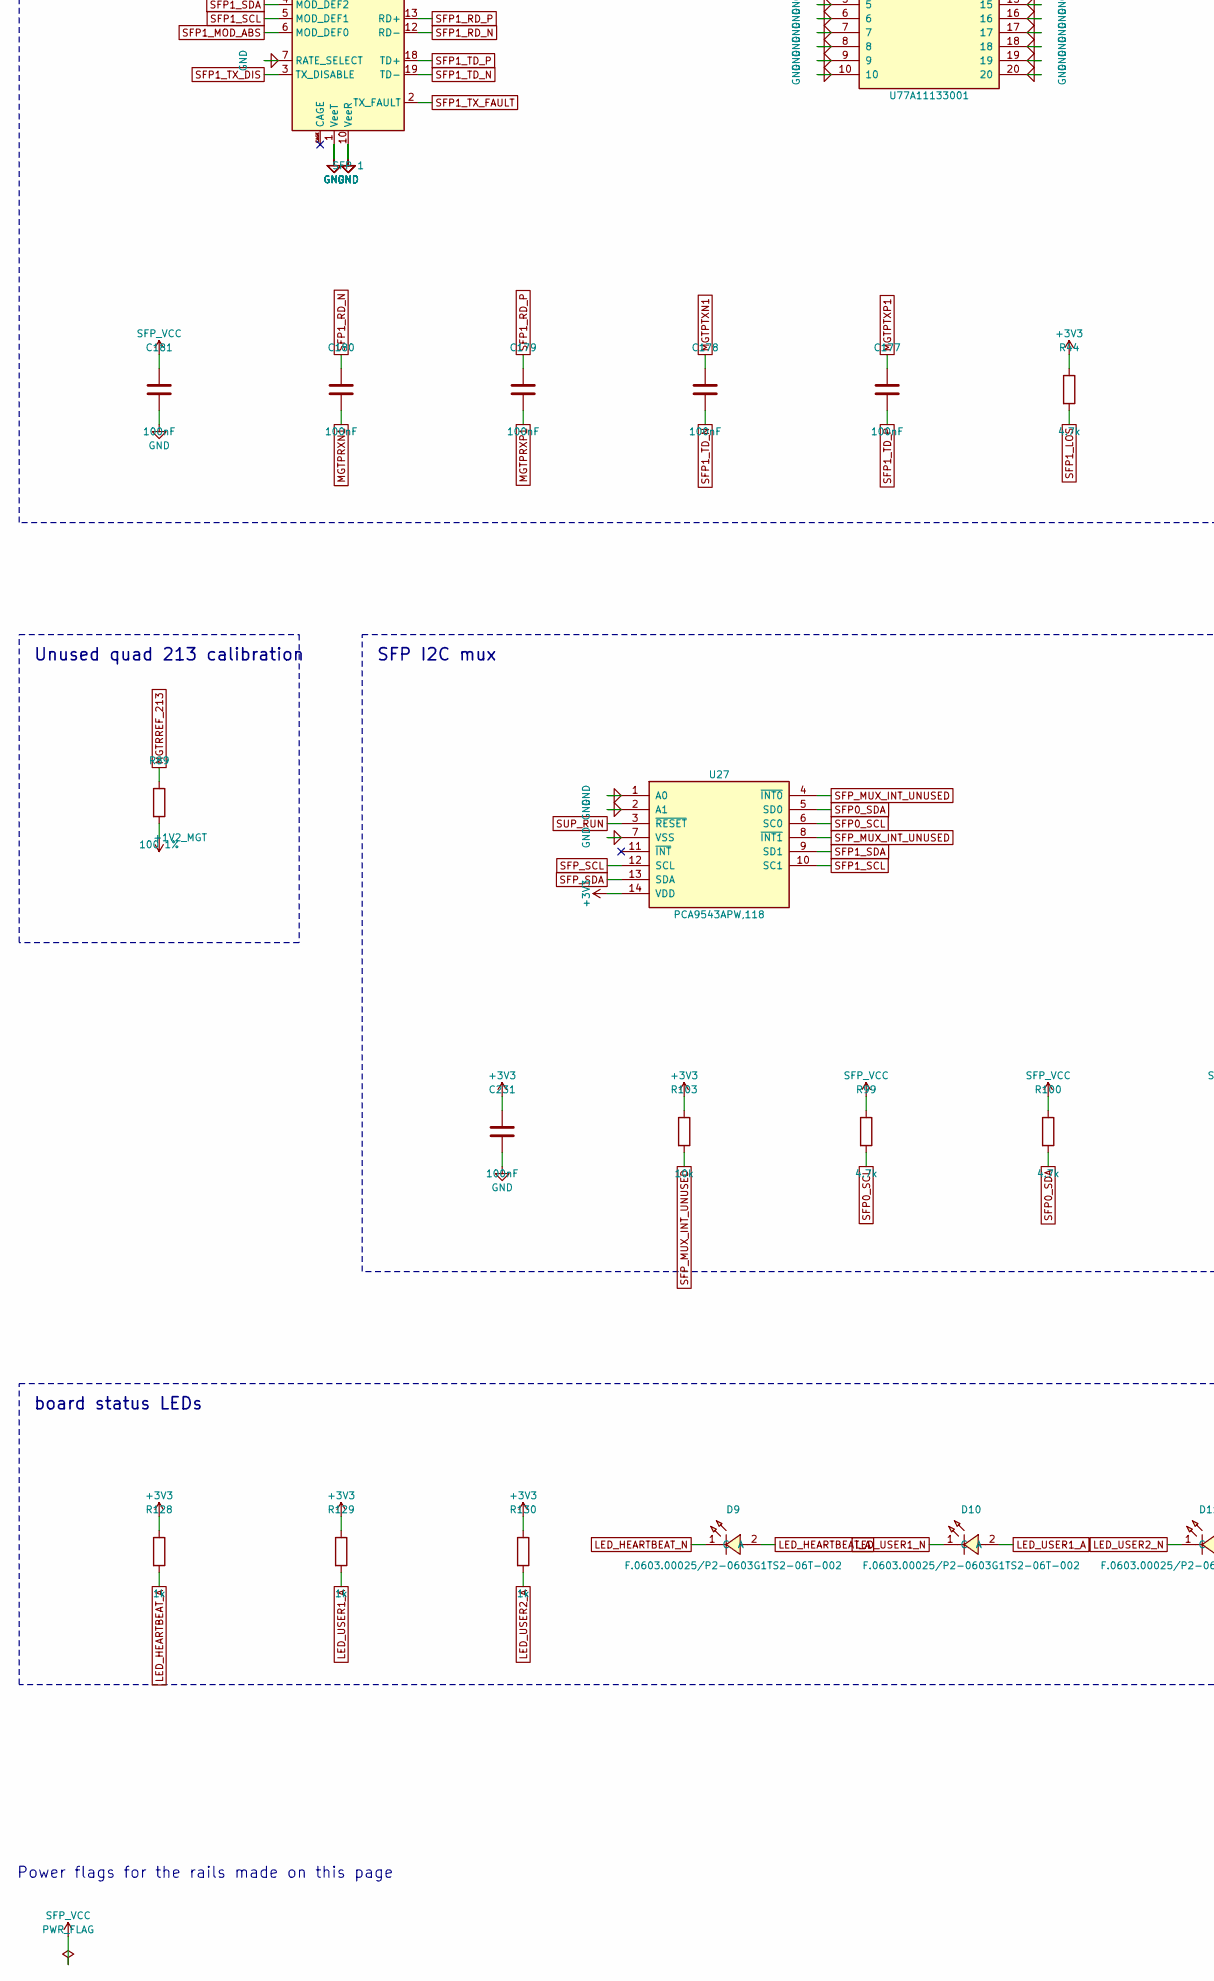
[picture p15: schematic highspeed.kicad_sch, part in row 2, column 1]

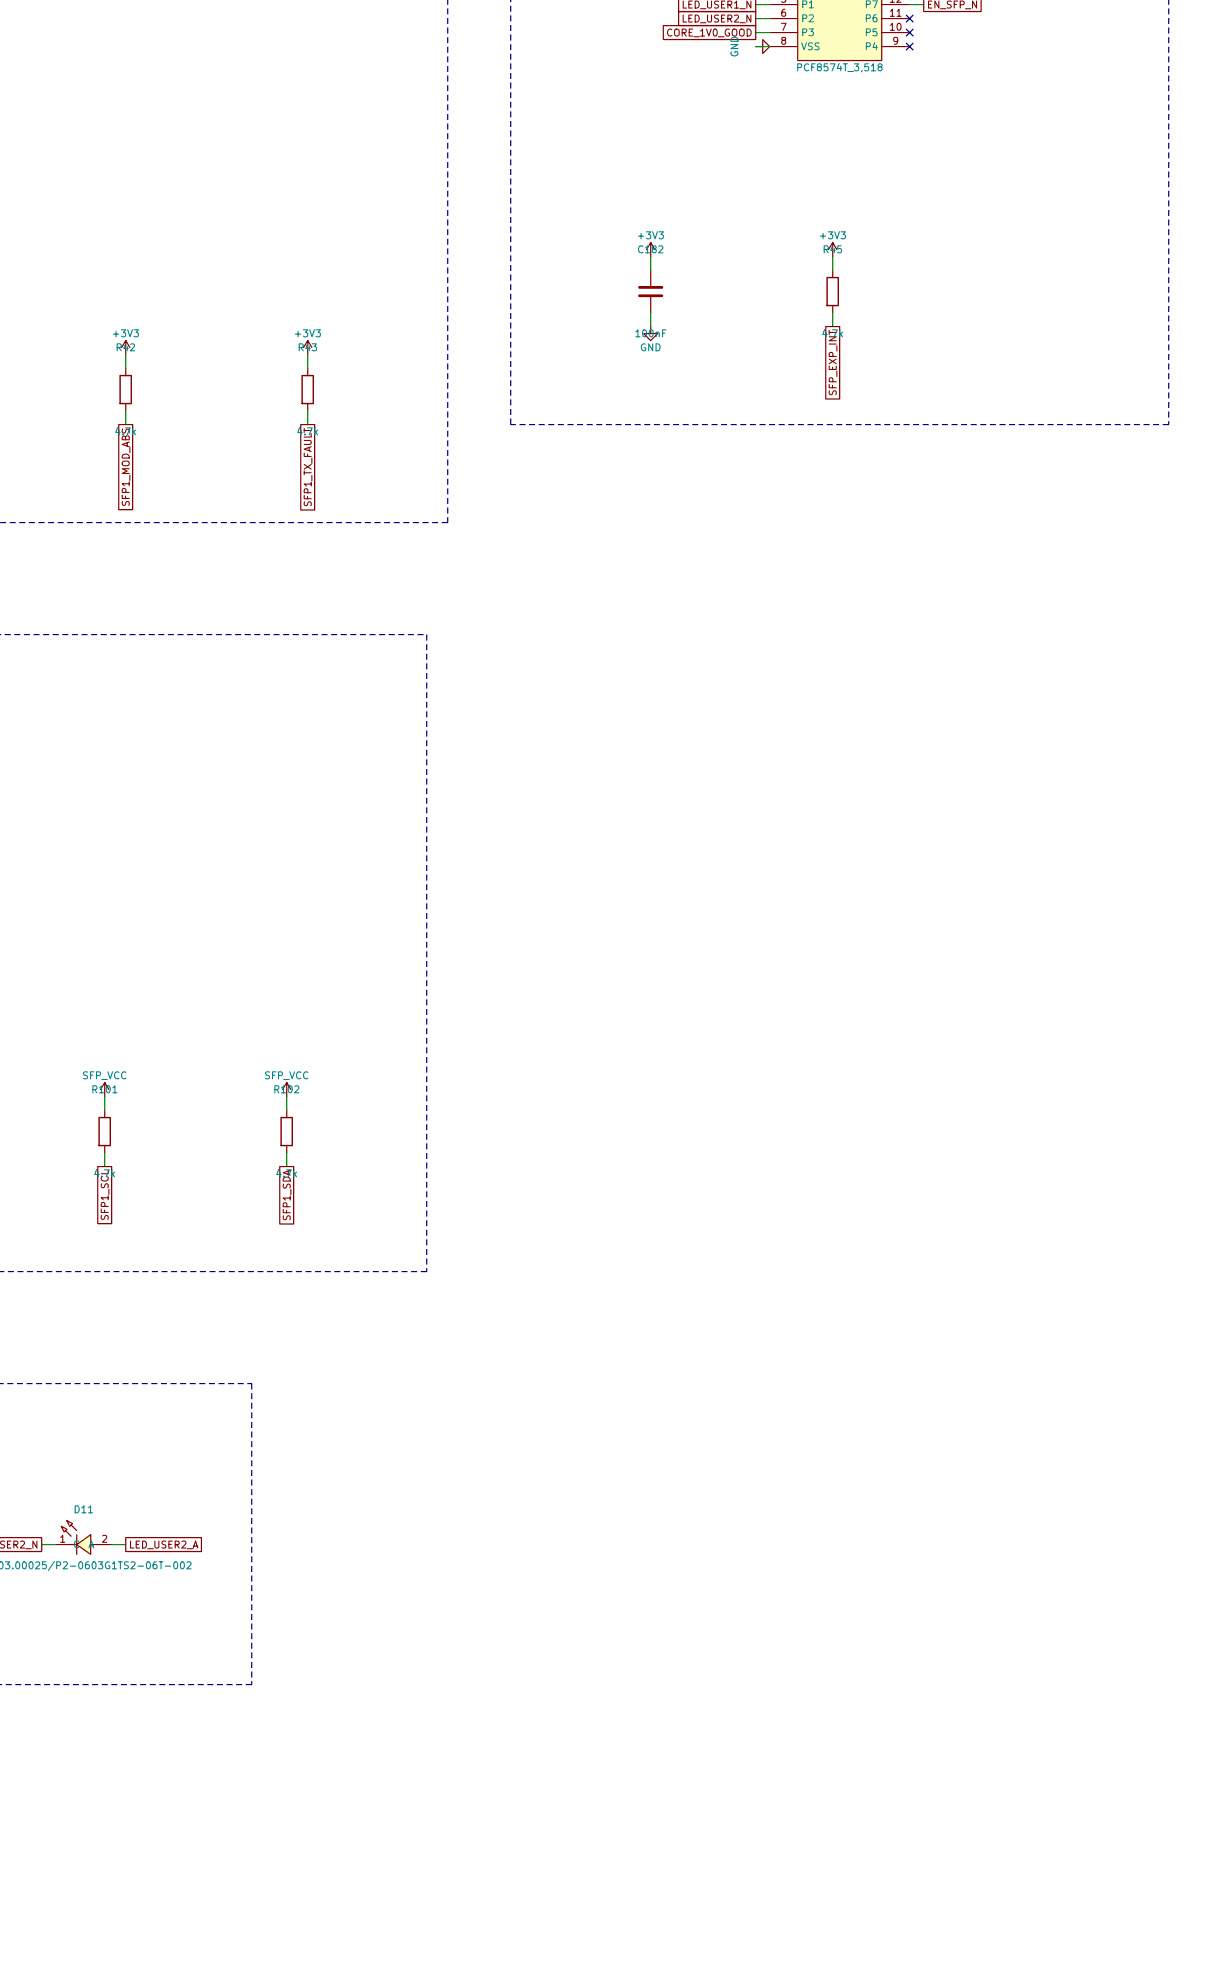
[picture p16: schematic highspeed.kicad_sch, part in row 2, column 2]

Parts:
C167, C169, C170, C172, C173, C174, C175, C176, C177, C178, C179, C180, C181, C182, C231: 100nF; C_0402_1005Metric; LCSC C1525
C168: 4.7uF; C_0603_1608Metric; LCSC C277476
C171: 10uF; C_0805_2012Metric; LCSC C15850
D9, D10, D11: F.0603.00025/P2-0603G1TS2-06T-002; LED0603-RD_GREEN; LCSC C7496818
J60: SFP 0; CONN-SMD_20P-P0.80-S8.20_1888247-1; LCSC C305914
J61: SFP 1; CONN-SMD_20P-P0.80-S8.20_1888247-1; LCSC C305914
Q1: DMG2305UX-7; SOT-23-3_L2.9-W1.3-P1.90-LS2.4-BR; LCSC C5261054
R35, R89: 100 1%; R_0603_1608Metric
R36: 100k; R_0402_1005Metric; LCSC C25741
R37, R38, R39, R40, R41, R42, R43, R44, R45, R99, R100, R101, R102: 4.7k; R_0402_1005Metric; LCSC C25900
R103: 10k; R_0402_1005Metric
R128, R129, R130: 1k; R_0402_1005Metric; LCSC C11702
SH1, SH2: U77A11133001; Amphenol_U77A11133001; LCSC C5355132
U17: PCF8574T_3,518; SOIC-16_L10.3-W7.5-P1.27-LS10.3-BL; LCSC C7605
U27: PCA9543APW,118; TSSOP-14_4.4x5mm_P0.65mm; LCSC C2652904
X2: DSC1123CI2-125.0000; OSC-SMD_6P-L3.2-W2.5-BL; LCSC C617173

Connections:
+1V2_MGT: R35.2, R89.2; also elsewhere on the board
+3V3: C167.1, C168.1, C182.1, C231.1, Q1.2 (S), R36.1, R37.1, R38.1, R39.1, R40.1, R41.1, R42.1, R43.1, R44.1, R45.1, R103.1, R128.1, R129.1, R130.1, U17.3 (A2), U17.16 (VDD), U27.14 (VDD), X2.1 (Enable), X2.6 (VDD); also elsewhere on the board
CORE_1V0_GOOD: U17.7 (P3); also elsewhere on the board
EN_SFP_N: Q1.1 (G), R36.2, U17.12 (P7)
GND: C167.2, C168.2, C171.2, C176.2, C181.2, C182.2, C231.2, J60.1 (VeeT), J60.7 (RATE_SELECT), J60.9 (VeeR), J60.10 (VeeR), J60.11 (VeeR), J60.14 (VeeR), J60.17 (VeeT), J60.20 (VeeT), J61.1 (VeeT), J61.7 (RATE_SELECT), J61.9 (VeeR), J61.10 (VeeR), J61.11 (VeeR), J61.14 (VeeR), J61.17 (VeeT), J61.20 (VeeT), SH1.1, SH1.2, SH1.3, SH1.4, SH1.5, SH1.6, SH1.7, SH1.8, SH1.9, SH1.10, SH1.11, SH1.12, SH1.13, SH1.14, SH1.15, SH1.16, SH1.17, SH1.18, SH1.19, SH1.20, SH2.1, SH2.2, SH2.3, SH2.4, SH2.5, SH2.6, SH2.7, SH2.8, SH2.9, SH2.10, SH2.11, SH2.12, SH2.13, SH2.14, SH2.15, SH2.16, SH2.17, SH2.18, SH2.19, SH2.20, U17.1 (A0), U17.2 (A1), U17.8 (VSS), U27.1 (A0), U27.2 (A1), U27.7 (VSS), X2.3 (GND); also elsewhere on the board
LED_HEARTBEAT_A: D9.2 (A), R128.2
LED_HEARTBEAT_N: D9.1 (C), U17.4 (P0)
LED_USER1_A: D10.2 (A), R129.2
LED_USER1_N: D10.1 (C), U17.5 (P1)
LED_USER2_A: D11.2 (A), R130.2
LED_USER2_N: D11.1 (C), U17.6 (P2)
MGTPRXN0: C175.2; also elsewhere on the board
MGTPRXN1: C180.2; also elsewhere on the board
MGTPRXP0: C174.2; also elsewhere on the board
MGTPRXP1: C179.2; also elsewhere on the board
MGTPTXN0: C173.1; also elsewhere on the board
MGTPTXN1: C178.1; also elsewhere on the board
MGTPTXP0: C172.1; also elsewhere on the board
MGTPTXP1: C177.1; also elsewhere on the board
MGTREFCLK0N: C170.2; also elsewhere on the board
MGTREFCLK0P: C169.2; also elsewhere on the board
MGTRREF: R35.1; also elsewhere on the board
MGTRREF_213: R89.1; also elsewhere on the board
REFCLK_OSC_N: C170.1, X2.5 (~Output)
REFCLK_OSC_P: C169.1, X2.4 (Output)
SFP0_LOS: J60.8 (RX_LOS), R41.2; also elsewhere on the board
SFP0_MOD_ABS: J60.6 (MOD_DEF0), R39.2; also elsewhere on the board
SFP0_RD_N: C175.1, J60.12 (RD-)
SFP0_RD_P: C174.1, J60.13 (RD+)
SFP0_SCL: J60.5 (MOD_DEF1), R99.2, U27.6 (SC0)
SFP0_SDA: J60.4 (MOD_DEF2), R100.2, U27.5 (SD0)
SFP0_TD_N: C173.2, J60.19 (TD-)
SFP0_TD_P: C172.2, J60.18 (TD+)
SFP0_TX_DIS: J60.3 (TX_DISABLE); also elsewhere on the board
SFP0_TX_FAULT: J60.2 (TX_FAULT), R40.2; also elsewhere on the board
SFP1_LOS: J61.8 (RX_LOS), R44.2; also elsewhere on the board
SFP1_MOD_ABS: J61.6 (MOD_DEF0), R42.2; also elsewhere on the board
SFP1_RD_N: C180.1, J61.12 (RD-)
SFP1_RD_P: C179.1, J61.13 (RD+)
SFP1_SCL: J61.5 (MOD_DEF1), R101.2, U27.10 (SC1)
SFP1_SDA: J61.4 (MOD_DEF2), R102.2, U27.9 (SD1)
SFP1_TD_N: C178.2, J61.19 (TD-)
SFP1_TD_P: C177.2, J61.18 (TD+)
SFP1_TX_DIS: J61.3 (TX_DISABLE); also elsewhere on the board
SFP1_TX_FAULT: J61.2 (TX_FAULT), R43.2; also elsewhere on the board
SFP_EXP_INT: R45.2, U17.13 (~INT)
SFP_MUX_INT_UNUSED: R103.2, U27.4 (~INT0), U27.8 (~INT1)
SFP_SCL: R37.2, U17.14 (SCL), U27.12 (SCL); also elsewhere on the board
SFP_SDA: R38.2, U17.15 (SDA), U27.13 (SDA); also elsewhere on the board
SFP_VCC: C171.1, C176.1, C181.1, J60.15 (VccR), J60.16 (VccT), J61.15 (VccR), J61.16 (VccT), Q1.3 (D), R99.1, R100.1, R101.1, R102.1
SUP_RUN: U27.3 (~RESET); also elsewhere on the board

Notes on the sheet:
HIGHSPEED — Four serial lanes: SFP cages, reference clock, power gate — HW 0.1.0-proto.1
125MHz reference clock
SFP power gate
SFP I2C bus
SFP port 0
SFP port 1
SFP port expander
Unused quad 213 calibration
SFP I2C mux
board status LEDs
Power flags for the rails made on this page

Board: 6 copper layers, 498 parts (96 on the bottom side), 422 nets, no tracks yet.

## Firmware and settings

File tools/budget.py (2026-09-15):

#!/usr/bin/env python3
"""Rail-by-rail power qualification for Odin.

Every current figure this board publishes should be derivable, and every
regulator should be checked against the thing it is actually asked to do. This
file is the single source for both: a load table with a stated basis per line,
a regulator table with datasheet citations, and the arithmetic that turns them
into "how much can a slot actually take".

    python3 tools/budget.py            # print the tables
    python3 tools/budget.py --write    # also regenerate ref/power-budget.md

Exit status is non-zero if any rail fails its own check, so a design that does
not meet its published numbers cannot be quietly committed.

Bases, in decreasing order of trust:
  datasheet  a number lifted from a manufacturer document
  computed   derived here from datasheet numbers
  estimate   engineering judgement; the honest label for most FPGA loads
  target     a design goal not yet backed by measurement
"""
import sys, os

# --------------------------------------------------------------- the source
# USB-C sources guarantee vSafe5V = 4.75 V minimum at the receptacle. The weak
# host port is the interesting case: it sets the floor for everything.
SOURCES = [
    ('USB-C, weak host port',  4.75, 0.9,  'USB-C vSafe5V min, 5V/0.9A default'),
    ('USB-C, 5V/3A port',      5.00, 3.0,  'Type-C 3A advertised over CC'),
    ('USB-PD, 9V contract',    9.00, 3.0,  'PD Power Rules: 9V mandatory >15W'),
    ('J50 external input',     9.00, 3.0,  'documented range 9-14V'),
]

# OR-ing loss between the connector and VSYS: the SS34 Schottky plus the
# input eFuse in series with it.
VF_SS34   = 0.45     # SS34 forward drop around 0.5 A, 25 C
RON_U26   = 0.05     # TPS259470A, conservative above its 28.3 mohm typical
I_VSYS_HI = 0.60     # VSYS current at which that drop is evaluated
V_OR_DROP = VF_SS34 + RON_U26 * I_VSYS_HI

# ------------------------------------------------------------- regulators
# vin_min/vin_max/iout/fsw are datasheet numbers; l is what design.py fits.
REGS = [
    dict(ref='U11', part='TPS54202DDC', topo='buck', src='VSYS', rail='+5V',
         vout=5.0, vin_min=4.5, vin_max=28.0, iout=2.0, fsw=500e3, ind='10uH',
         ripple_max=0.40, cite='SLVSD26C: 4.5-28V in, 2A out, 500kHz fixed',
         # U11 cannot make 5V from 5V and is never meant to: on a plain 5V
         # source the rail is VBUS through Q2 instead. Firmware enables exactly
         # one of the two, so U11's input floor is the 9V case, not the 5V one.
         enabled_above=9.0 - V_OR_DROP),
    dict(ref='U12', part='AP63300WU-7', topo='buck', src='VSYS', rail='+3V3',
         vout=3.3, vin_min=3.8, vin_max=32.0, iout=3.0, fsw=500e3, ind='4.7uH',
         ripple_max=0.50, cite='Diodes DS42002: 3.8-32V in, 3A, 500kHz; '
         '3.3V reference circuit uses 4.7uH'),
    dict(ref='U13', part='TLV62569DRL', topo='buck', src='+5V', rail='+2V5',
         vout=2.5, vin_min=2.5, vin_max=5.5, iout=2.0, fsw=1.5e6, ind='2.2uH',
         ripple_max=0.35, cite='SLVSDG1C: 2.5-5.5V in, 2A out, 1.5MHz'),
    dict(ref='U14', part='TLV62569DRL', topo='buck', src='+5V', rail='+1V8',
         vout=1.8, vin_min=2.5, vin_max=5.5, iout=2.0, fsw=1.5e6, ind='2.2uH',
         ripple_max=0.35, cite='SLVSDG1C: recommends 2.2uH for 5V->1.8V/2A'),
    dict(ref='U15', part='SY8047QDC', topo='buck', src='+5V', rail='+1V0',
         vout=1.0, vin_min=2.5, vin_max=5.5, iout=4.0, fsw=1.25e6,
         ind='1uH_core', ripple_max=0.35,
         cite='Silergy SY8047 Rev 0.9: 2.5-5.5V in, 4A out, 1.25MHz; '
              'reference circuit uses 1.0uH and 2x22uF output'),
    dict(ref='U16', part='TLV62569DRL', topo='buck', src='+5V', rail='+1V2_MGT',
         vout=1.2, vin_min=2.5, vin_max=5.5, iout=2.0, fsw=1.5e6, ind='2.2uH',
         ripple_max=0.35, cite='SLVSDG1C: 2.5-5.5V in, 2A out, 1.5MHz'),
    dict(ref='U19', part='TPS61085PW', topo='boost', src='+5V', rail='+12V',
         vout=12.0, vin_min=2.3, vin_max=6.0, ilim=2.0, fsw=650e3, ind='10uH',
         ripple_max=0.35,
         cite='SLVS859B: 2.3-6V in, 18.5V max out, ILIM 2.0A min, '
              '650kHz with FREQ=GND, 6-13uH recommended at 650kHz'),
    # Not ours to size: Raspberry Pi specify the inductor, the three 4.7uF
    # caps and the layout, and say plainly that deviating is at your own risk.
    # So the ripple check is skipped rather than applied to someone else's
    # qualified design with a switching frequency we would have to invent.
    dict(ref='U7',  part='RP2350B VREG', topo='buck', src='+3V3', rail='+1V1',
         vout=1.1, vin_min=2.7, vin_max=3.6, iout=0.20, fsw=None, ind='3.3uH',
         ripple_max=None, mandated=True,
         cite='RP-008280 s2.1: 200mA, L1 = AOTA-B201610S3R3-101-T'),
]

# ------------------------------------------------------------------ loads
# (rail, what, amps, basis, citation). Worst case, all at once -- which is the
# only version of a budget that is any use.
LOADS = [
    # ---- +1V0, FPGA core
    ('+1V0', 'XC7A100T VCCINT, busy design', 1.50, 'estimate',
     'pre-bitstream planning allowance; replace with an AMD XPE result'),
    ('+1V0', 'VCCBRAM', 0.05, 'estimate', 'share of the 0.25 W AUX/BRAM line'),
    ('+1V0', '+1V0_MGT (MGTAVCC, filtered off +1V0)', 0.10, 'estimate',
     '2 lanes, share of the 0.4 W transceiver line'),
    # ---- +1V8, FPGA VCCAUX
    ('+1V8', 'XC7A100T VCCAUX', 0.18, 'estimate',
     'pre-bitstream planning allowance; replace with an AMD XPE result'),
    # ---- +1V2_MGT
    ('+1V2_MGT', 'MGTAVTT, 2 lanes', 0.15, 'estimate',
     'share of the 0.4 W transceiver line'),
    # ---- +3V3, the crowded one
    ('+3V3', 'RP2350B supervisor + boot flash', 0.07, 'estimate',
     'ref/power-input.md: 0.2 W'),
    ('+3V3', 'FPGA bank 14 VCCO and its I/O', 0.10, 'estimate',
     'one third of the 1.0 W VCCO/IO line'),
    ('+3V3', 'PSRAM x4, all active', 0.20, 'estimate',
     'ref/power-input.md: 0.66 W across four chips'),
    ('+3V3', 'config flash W25Q256, program', 0.03, 'datasheet',
     'W25Q256JV: 25 mA page-program peak'),
    ('+3V3', 'SFP modules x2 (SFP_VCC, gated by Q1)', 0.61, 'estimate',
     'ref/power-input.md: 2.0 W for two modules'),
    ('+3V3', 'Heartbeat and user LEDs x3, all on', 0.005, 'estimate',
     'D9-D11 via 1k each; 5 mA budget allowance'),
    ('+3V3', '125MHz LVDS oscillator', 0.04, 'estimate',
     'typical 6-pin LVDS oscillator'),
    ('+3V3', 'U9/U10 VCCA, U20, pull-ups, LED', 0.03, 'estimate',
     'quiescent logic'),
    ('+3V3', 'FPGA bank 15 VCCO, worst case jumpered to 3.3V', 0.10, 'estimate',
     'bank load only; connector export is checked from switch maximum below'),
    ('+3V3', 'FPGA bank 34 VCCO, worst case jumpered to 3.3V', 0.10, 'estimate',
     'bank load only; connector export is checked from switch maximum below'),
    ('+3V3', 'FPGA unused banks 13/16/35 VCCO', 0.06, 'estimate',
     'powered at 3.3V so every VCCO ball has a defined supply'),
    # ---- +1V1, the supervisor's core, off the RP2350's own regulator
    ('+1V1', 'RP2350B core (DVDD)', 0.06, 'estimate',
     'RP2350 at 150 MHz; the on-chip regulator is rated 200 mA'),
    # ---- +5V
    ('+5V', 'U9/U10 VCCB', 0.02, 'estimate', 'quiescent translator supply'),
    # ---- +12V AUX has no board-side load at all; it exists for the slots.
]

RAIL_ORDER = ['VSYS', '+5V', '+3V3', '+1V1', '+2V5', '+1V8', '+1V0',
              '+1V2_MGT', '+12V']
# Rails that leave the board on a connector have to be sized for their rating,
# because a slot is allowed to ask for the spare. The rest are sized for their
# actual load plus transient headroom -- +1V0 and +1V2_MGT never reach a pin.
EXPORTED = {'+5V', '+3V3', '+12V', '+2V5', '+1V8'}
TRANSIENT = 1.5
# The rails a slot can draw from, and the per-slot fuse fitted on each.
SLOT_RAILS = {'+5V': '500mA', '+3V3': '300mA', '+12V': '200mA',
              'VCCIO': '500mA'}
ETA = 0.90      # conversion efficiency assumption, per TI's own guidance

# ---------------------------------------------------------------- inductors
# L value comes out of the arithmetic below; Isat/DCR are datasheet numbers for
# the part named. design.py imports INDUCTOR so the schematic and this file
# cannot disagree about what is fitted. Two part numbers cover seven positions.
INDUCTOR = {
    '1uH_core': dict(mpn='FTC201610S1R0MBCA', l=1.0e-6, isat=4.60,
                     dcr=0.035, size='2.0 x 1.6 mm',
                     fp='EasyEDA:IND-SMD_L2.0-W1.6-B', lcsc='C5832342',
                     cite='cjiang FTC201610S1R0MBCA: 1.0uH +/-20%, '
                          'DCR 35 mohm, Irms 4.50 A, Isat 4.60 A'),
    '4.7uH': dict(mpn='SRN6045TA-4R7M', l=4.7e-6, isat=6.80, dcr=0.026,
                  size='6.0 x 6.0 x 4.5 mm',
                  fp='EasyEDA:IND-SMD_L6.0-W6.0', lcsc='C2044594',
                  cite='Bourns SRN6045TA: 4.7uH +/-20%, DCR 26 mohm, '
                       'Irms 4.50 A, Isat 6.80 A'),
    '10uH':  dict(mpn='SRN6045TA-100M', l=10.0e-6, isat=4.60, dcr=0.052,
                  size='6.0 x 6.0 x 4.5 mm',
                  fp='EasyEDA:IND-SMD_L6.0-W6.0-1', lcsc='C2046332',
                  cite='Bourns SRN6045TA: 10uH +/-20%, DCR 52 mohm, '
                       'Irms 3.20 A, Isat 4.60 A'),
    '2.2uH': dict(mpn='SRN4018-2R2M', l=2.2e-6, isat=3.00, dcr=0.044,
                  size='4.0 x 4.0 x 1.8 mm',
                  fp='EasyEDA:IND-SMD_L4.0-W4.0_SNR4018',
                  cite='Bourns SRN4018: 2.2uH +/-20%, DCR 44 mohm, '
                       'Irms 2.90 A, Isat 3.00 A', lcsc='C913207'),
    '1uH':   dict(mpn='VLS252010HBX-1R0M-1', l=1.0e-6, isat=3.57, dcr=0.054,
                  size='2.5 x 2.0 x 1.0 mm',
                  fp='EasyEDA:IND-SMD_L2.5-W2.0-1',
                  cite='TDK VLS252010HBX: 1.0uH +/-20%, DCR 54 mohm, '
                       'rated current 3.00 A, saturation current 3.57 A',
                  lcsc='C88211'),
    '3.3uH': dict(mpn='AOTA-B201610S3R3-101-T', l=3.3e-6, isat=2.40, dcr=0.140,
                  size='2.0 x 1.6 x 1.0 mm',
                  fp='EasyEDA:IND-SMD_L2.0-W1.6_AOTA-B201610S3R3-101-T',
                  lcsc='C42411119',
                  cite='Abracon: 3.3uH +/-20%, DCR 140 mohm max, Irms 2.10 A '
                       'min, Isat 2.40 A min; mandated by RP-008280 s2.1'),
}


def buck_ripple(vout, vin, l, fsw):
    """Peak-to-peak inductor ripple current of a CCM buck."""
    return vout * (1.0 - vout / vin) / (l * fsw)


def boost_capability(vin, vout, ilim, fsw, l, eta=ETA):
    """TPS61085 datasheet equations 1-4. Returns (D, dIL, Iout_max, Isw_peak)."""
    d = 1.0 - vin * eta / vout
    dil = vin * d / (fsw * l)
    iout = (ilim - dil / 2.0) * (1.0 - d)
    ipk = dil / 2.0 + iout / (1.0 - d)
    return d, dil, iout, ipk


def rail_load(rail):
    return sum(a for r, _, a, _, _ in LOADS if r == rail)


def analyse():
    reg = {r['rail']: r for r in REGS}
    rows, problems, notes = [], [], []

    vsys_min = min(v for _, v, _, _ in SOURCES) - V_OR_DROP
    vsys_max = 14.0                                 # J50 documented maximum
    railv = {'VSYS': (vsys_min, vsys_max)}
    for r in REGS:
        railv[r['rail']] = (r['vout'], r['vout'])
    # In 5V-only mode the +5V rail is VBUS through Q2, not U11's output.
    railv['+5V'] = (min(v for _, v, _, _ in SOURCES) - 0.05, 5.5)

    # ---- the boost, which is what AUX actually is
    b = reg['+12V']
    d12, dil12, iout12, ipk12 = boost_capability(
        railv['+5V'][0], b['vout'], b['ilim'], b['fsw'],
        INDUCTOR[b['ind']]['l'])
    aux_from_boost = iout12
    aux_input_i = iout12 * b['vout'] / (railv['+5V'][0] * ETA)

    # ---- own loads, then cascade child input currents onto parents
    load = {r: rail_load(r) for r in RAIL_ORDER}
    # children of +5V: the four TLV62569 and the boost
    for r in REGS:
        if r['src'] == '+5V' and r['rail'] != '+12V':
            iin = load[r['rail']] * r['vout'] / (railv['+5V'][0] * ETA)
            load['+5V'] += iin
    # children of +3V3: the RP2350's own core regulator
    load['+3V3'] += load['+1V1'] * 1.1 / (3.3 * ETA)
    # VSYS carries U11 and U12
    load['VSYS'] = 0.0

    # ---- per-regulator checks
    for r in REGS:
        rail = r['rail']
        vin_lo, vin_hi = railv[r['src']]
        used = load[rail]
        cap = r.get('iout', aux_from_boost if r['topo'] == 'boost' else 0.0)
        ind = INDUCTOR[r['ind']]
        design_i = (r['iout'] if rail in EXPORTED and 'iout' in r
                    else used * TRANSIENT)
        if r['topo'] == 'boost':
            cap, dil, ipk = aux_from_boost, dil12, ipk12
            ripple = dil / (aux_from_boost / (1 - d12)) if aux_from_boost else 0
        elif r.get('mandated'):
            dil, ipk, ripple = 0.0, used, 0.0
        else:
            dil = buck_ripple(r['vout'], vin_hi, ind['l'], r['fsw'])
            ipk = design_i + dil / 2.0
            ripple = dil / r['iout']
        # 30% over the peak, which is what the TLV62569 datasheet asks for.
        isat_req = 1.3 * max(ipk, dil / 2.0)
        if not r.get('mandated') and ind['isat'] < isat_req:
            problems.append(
                f"{r['ref']}: {ind['mpn']} saturates at {ind['isat']:.2f}A but "
                f"the rail needs {isat_req:.2f}A ({ipk:.2f}A peak +30%)")
        vin_lo_eff = max(vin_lo, r.get('enabled_above', 0.0))
        if vin_lo_eff < r['vin_min']:
            problems.append(
                f"{r['ref']} ({r['part']}) needs Vin >= {r['vin_min']}V but its "
                f"source {r['src']} falls to {vin_lo_eff:.2f}V on the weakest "
                f"input it is enabled on")
        if vin_hi > r['vin_max']:
            problems.append(f"{r['ref']} sees {vin_hi:.2f}V, over its "
                            f"{r['vin_max']}V maximum")
        if r['ripple_max'] is not None and ripple > r['ripple_max']:
            problems.append(
                f"{r['ref']} inductor ripple is {ripple*100:.0f}% of full load "
                f"with L={r['l']*1e6:g}uH, over the {r['ripple_max']*100:.0f}% "
                f"guideline")
        rows.append(dict(ref=r['ref'], part=r['part'], rail=rail,
                         vout=r['vout'], src=r['src'], vin_lo=vin_lo,
                         vin_hi=vin_hi, vin_lo_eff=vin_lo_eff,
                         cap=cap, used=used, l=ind['l'], mpn=ind['mpn'],
                         isat_have=ind['isat'], lsize=ind['size'],
                         design_i=design_i,
                         dil=dil, ipk=ipk, isat=isat_req, cite=r['cite'],
                         spare=cap - used))
    # ---- what a slot can have.
    # AUX is not simply the boost's capability: every milliamp out of the boost
    # costs Vout/(Vin*eta) milliamps of the +5V rail, and the +5V rail is also
    # what the slots' own +5V pins come from. Report the binding limit.
    spare = {row['rail']: row['spare'] for row in rows}
    aux_from_5v = spare['+5V'] * railv['+5V'][0] * ETA / b['vout']
    aux_cost = b['vout'] / (railv['+5V'][0] * ETA)     # mA of +5V per mA of AUX
    spare['+12V'] = min(aux_from_boost, aux_from_5v)
    for rail in ('+5V', '+3V3', '+12V'):
        if spare[rail] < 0:
            problems.append(f"{rail} is oversubscribed by "
                            f"{-spare[rail]*1000:.0f} mA before any slot draws")
    # Both VCCIO domains can select the same source. Use the load switch's
    # maximum specified limit, not its typical label, and add both FPGA banks.
    ext_sw_max = 0.620
    bank_pair = 0.200
    selector_cases = {
        '+3V3': load['+3V3'] + 2 * ext_sw_max,
        '+2V5': load['+2V5'] + bank_pair + 2 * ext_sw_max,
        '+1V8': load['+1V8'] + bank_pair + 2 * ext_sw_max,
    }
    for rail, worst in selector_cases.items():
        cap = reg[rail]['iout']
        if worst > cap:
            problems.append(f"{rail}: both VCCIO domains at 620mA max plus "
                            f"bank/base loads need {worst:.3f}A, over {cap:.3f}A")
    return rows, spare, problems, dict(
        vsys_min=vsys_min, vsys_max=vsys_max, v5_min=railv['+5V'][0],
        d12=d12, dil12=dil12, iout12=iout12, ipk12=ipk12,
        aux_input_i=aux_input_i, load=load, aux_from_5v=aux_from_5v,
        aux_cost=aux_cost, aux_limit=spare['+12V'], selector_cases=selector_cases)


def fmt(rows):
    o = []
    o.append('| Ref | Part | Rail | Source | Vin seen | Capability | '
             'Board load | Spare |')
    o.append('|---|---|---|---|---|---|---|---|')
    for r in rows:
        o.append(f"| `{r['ref']}` | `{r['part']}` | {r['rail']} | {r['src']} | "
                 f"{r['vin_lo_eff']:.2f}–{r['vin_hi']:.2f} V | {r['cap']*1000:.0f} mA "
                 f"| {r['used']*1000:.0f} mA | {r['spare']*1000:.0f} mA |")
    return '\n'.join(o)


HEAD = """# Odin power budget

**Generated by `tools/budget.py`. Do not hand-edit.** Every number below is
either a datasheet figure, or arithmetic on datasheet figures, or an estimate
that says so. Nothing here is a round number chosen because it looked right.

The load table is worst case *simultaneous*: both VCCIO domains jumpered to
3.3 V, two SFP modules fitted and powered, all four PSRAMs active, the FPGA
core busy. That is a case you can build, so it is the case the rails have to
survive.
"""


def main():
    rows, spare, problems, x = analyse()
    print(f"OR-ing drop VBUS->VSYS: {V_OR_DROP:.2f} V "
          f"(SS34 {VF_SS34} V + {RON_U26} ohm x {I_VSYS_HI} A)")
    print(f"VSYS: {x['vsys_min']:.2f} V worst case .. {x['vsys_max']:.2f} V "
          f"(J50 documented maximum)\n")
    print(f"{'ref':5s} {'rail':9s} {'src':6s} {'Vin':13s} {'cap':>8s} "
          f"{'load':>8s} {'spare':>8s} {'L':>7s} {'dIL':>8s} {'Ipk':>7s} "
          f"{'Isat>=':>7s}")
    for r in rows:
        print(f"{r['ref']:5s} {r['rail']:9s} {r['src']:6s} "
              f"{r['vin_lo_eff']:5.2f}-{r['vin_hi']:5.2f}V "
              f"{r['cap']*1e3:7.0f}m {r['used']*1e3:7.0f}m "
              f"{r['spare']*1e3:7.0f}m {r['l']*1e6:6.1f}u "
              f"{r['dil']*1e3:7.0f}m {r['ipk']:6.2f}A {r['isat']:6.2f}A")
    print(f"\nAUX 12V boost, worst-case input {x['v5_min']:.2f} V:")
    print(f"  duty {x['d12']*100:.1f}%  ripple {x['dil12']*1000:.0f} mA  "
          f"Iout(max) {x['iout12']*1000:.0f} mA  Ipk(switch) {x['ipk12']:.2f} A")
    print(f"  which draws {x['aux_input_i']*1000:.0f} mA from +5V at full load"
          f"  ({x['aux_cost']:.2f} mA of +5V per mA of AUX)")
    print(f"  +5V can only spare {x['aux_from_5v']*1000:.0f} mA of AUX, so the "
          f"binding AUX limit is {x['aux_limit']*1000:.0f} mA")
    if problems:
        print("\nPROBLEMS")
        for p in problems:
            print(f"  - {p}")
    if '--write' in sys.argv:
        out = [HEAD, '\n## Regulators, loads and what is left over\n',
               fmt(rows), '']
        out.append(f"""
`Vin seen` is the range that rail's *source* covers across every documented
input, including the {V_OR_DROP:.2f} V OR-ing drop from `VBUS` to `VSYS`
(SS34 forward drop plus the input eFuse). `Capability` is the
datasheet output rating, except for `+12V`, where it is computed below.
`Spare` is what remains for the extension slots after the board's own worst
case.

Two caveats on the +5 V row. It is `U11`'s 2 A rating, which only applies once
a 9 V contract or `J50` is present; **on a plain 5 V source the rail is `VBUS`
through `Q2`, so its ceiling is whatever the USB source gives** — 0.9 A on a
weak host port, against a board that already wants more than that. And the AUX
boost draws from this same rail, as the next section works out.

## The AUX 12 V rail, computed rather than asserted

`U19` is a `TPS61085` boost from +5 V. Its capability is not "5 V x 2 A / 12 V";
it is TI's design procedure (SLVS859B equations 1-4) at the worst-case input:

| | |
|---|---|
| Input, worst case | {x['v5_min']:.2f} V |
| Duty cycle | {x['d12']*100:.1f}% |
| Inductor | {[r for r in rows if r['rail']=='+12V'][0]['l']*1e6:g} µH at 650 kHz |
| Inductor ripple | {x['dil12']*1000:.0f} mA p-p |
| Switch current limit | 2.0 A **minimum** |
| **Iout(max)** | **{x['iout12']*1000:.0f} mA** |
| Peak switch current | {x['ipk12']:.2f} A |
| Draw on +5 V at full load | {x['aux_input_i']*1000:.0f} mA |

Two things follow. First, the honest boost figure is around
{x['iout12']*1000:.0f} mA, not 700 mA — and even that assumes 90% efficiency
and ignores thermals, so treat it as a **provisional design target** until a
board is measured. Second, AUX at full output would pull
{x['aux_input_i']*1000:.0f} mA out of the +5 V rail, which only has
{spare['+5V']*1000:.0f} mA spare, so the boost is not the binding constraint
— the 5 V rail is. **AUX is therefore {x['aux_limit']*1000:.0f} mA**, and
every milliamp of it costs {x['aux_cost']:.2f} mA of +5 V, so AUX and the
slots' own +5 V pins are drawing from the same pot.

## Active extension-bus limits

These switches sit before the per-slot PTCs. The resistor calculations use
the equations in TI SLVSFJ2B and SLVSFC9C.

| Protected bus | Part | Programming | Typical trip/limit | Datasheet range |
|---|---|---|---:|---:|
| `+5V_EXT` | TPS22950CDDCR | `RILIM=1.15 kohm`; `1.18 x 1.15^-1.072` | 1.000 A | 0.75-1.25 A; below 1.615 A source headroom |
| `+3V3_EXT` | TPS22950CDDCR | `RILIM=2.21 kohm`; `1.18 x 2.21^-1.072` | 0.500 A | 0.38-0.62 A |
| `VCCIO_1_EXT` | TPS22950CDDCR | same 2.21 kohm | 0.500 A | 0.38-0.62 A |
| `VCCIO_2_EXT` | TPS22950CDDCR | same 2.21 kohm | 0.500 A | 0.38-0.62 A |
| `+12V_EXT` | TPS259470LRPWR | `RILM=6.65 kohm`; `3334/6650` | 0.501 A | 0.425-0.575 A |
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

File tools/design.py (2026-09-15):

#!/usr/bin/env python3
"""Declarative netlist for Odin. Parts connect by PIN NAME; numbers are resolved
from the KiCad symbol libraries so nothing is hand-typed and nothing is guessed."""
import sys, os
sys.path.insert(0, os.path.dirname(__file__))
import symlib
from alloc import assign, load
from budget import INDUCTOR
from identity import FPGA_PART, CONTROLLER_PART
from collections import OrderedDict

FP_FPGA = 'EasyEDA:FBGA-676_L27.0-W27.0-R26-C26-P1.00-BL'
C0402   = 'Capacitor_SMD:C_0402_1005Metric'
C0603   = 'Capacitor_SMD:C_0603_1608Metric'
C0805   = 'Capacitor_SMD:C_0805_2012Metric'
R0402   = 'Resistor_SMD:R_0402_1005Metric'
R0603   = 'Resistor_SMD:R_0603_1608Metric'
# Inductors are not chosen here. tools/budget.py computes what each rail needs
# and names the part that meets it; this module only fits it.
SOT236  = 'Package_TO_SOT_SMD:SOT-23-6'
SOIC8N  = 'EasyEDA:SOIC-8_L4.9-W3.9-P1.27-LS6.0-BL'
WSON8_6 = 'EasyEDA:WSON-8_L6.0-W5.0-P1.27-BL-EP'   # Winbond ZP
WSON8_8 = 'EasyEDA:WSON-8_L8.0-W6.10-P1.27-BL-EP'
PTC1206 = 'Fuse:Fuse_1206_3216Metric'
PTC1206_EASYEDA = 'EasyEDA:F1206'
SOT563  = 'EasyEDA:SOT-563_L1.6-W1.2-P0.50-LS1.6-BL'
SOT236_ESD = 'EasyEDA:SOT-23-6_L2.9-W1.6-P0.95-LS2.8-BR'
SOT236_BUCK = 'EasyEDA:SOT-23-6_L2.9-W1.6-P0.95-LS2.8-BL'
SOT236_LOAD = 'EasyEDA:SOT-23-6_L2.9-W1.6-P0.95-LS2.8-BL_3'
SOT236_AP = 'EasyEDA:TSOT-23-6_L2.9-W1.6-P0.95-LS2.8-BR'
SSOP10  = 'EasyEDA:ESSOP-10_L4.9-W3.9-P1.0-LS6.0-TL-EP'
SOIC16W = 'Package_SO:SOIC-16W_7.5x10.3mm_P1.27mm'
TSSOP8  = 'EasyEDA:TSSOP-8_L4.4-W3.0-P0.65-LS6.4-BL'
QFN80   = 'EasyEDA:QFN-80_L10.0-W10.0-P0.40-TL-EP3.4'
TSSOP24_SWITCH = 'EasyEDA:TSSOP-24_L7.8-W4.4-P0.65-LS6.4-BL'
TSSOP24_XLATE = 'EasyEDA:TSSOP-24_L7.8-W4.4-P0.65-LS6.4-BL_1'
VSSOP8_LVC2T45 = 'EasyEDA:VSSOP-8_L2.1-W2.4-P0.50-LS3.2-BL'
QFN16_SY8047 = 'EasyEDA:TQFN-16_L3.0-W3.0-P0.50-TL-EP1.6'
VQFN10RPU = 'Package_DFN_QFN:Texas_RPU0010A_VQFN-HR-10_2x2mm_P0.5mm'
EXT2x8  = 'EasyEDA:HDR-SMD_16P-P2.54-V-F-R2-C8-LS7.1'
EXT2x16 = 'EasyEDA:HDR-SMD_32P-P2.54-V-F-R2-C16-LS7.1'
EXT1x16 = 'EasyEDA:HDR-TH_16P-P2.54-V-F-1'
EXT1x8  = 'EasyEDA:HDR-TH_8P-P2.54-V-F'
HDR2x3  = 'EasyEDA:HDR-TH_6P-P2.54-V-M-R2-C3-S2.54-1'
HDR2x5  = 'Connector_PinHeader_2.54mm:PinHeader_2x05_P2.54mm_Vertical'
HDR1x2  = 'Connector_PinHeader_2.54mm:PinHeader_1x02_P2.54mm_Vertical'
HDR1x3  = 'Connector_PinHeader_2.54mm:PinHeader_1x03_P2.54mm_Vertical'
XTAL    = 'EasyEDA:CRYSTAL-SMD_4P-L3.2-W2.5-BL'
USBC    = 'Connector_USB:USB_C_Receptacle_HCTL_HC-TYPE-C-16P-01A'
LED0603 = 'LED_SMD:LED_0603_1608Metric'

LCSC = {'APS1604M-3SQRx-SN':'C18214056',
        'TLV62569DRL':'C163217', 'TPS54202DDC':'C191884'}

class Design:
    def __init__(self):
        self.parts = []
        self._n = {}
        self.cur = 'misc'
        self.grp = ''
    def sheet(self, name):
        self.cur = name; self.grp = name
    def group(self, name):
        self.grp = name
    def add(self, ref, lib_id, value, fp, conn, lcsc='', dnp=False, fp_ok=''):
        if any(q['ref'] == ref for q in self.parts):
            raise ValueError(f"duplicate designator {ref}")
        if not fp_ok: self._check_package(ref, lib_id, fp)
        sym = symlib.get(lib_id)
        pins = {}
        conn = {k: v for k, v in conn.items() if v}
        for k, net in conn.items():
            if k in sym['pins']:
                for num, unit in sym['pins'][k]: pins[num] = net
            else:                                   # already a pin number
                pins[k] = net
        missing = [k for k in conn if k not in sym['pins'] and k not in
                   {n for v in sym['pins'].values() for n, _ in v}]
        if missing: raise KeyError(f"{ref} {lib_id}: no such pin {missing}; "
                                   f"have {sorted(sym['pins'])[:14]}")
        self.parts.append(dict(ref=ref, lib_id=lib_id, value=value, fp=fp,
                               pins=pins, lcsc=lcsc, dnp=dnp, sym=sym,
                               sheet=self.cur, group=self.grp))
        return ref
    @staticmethod
    def _check_package(ref, lib_id, fp):
        """A wrong footprint is invisible to ERC and to schematic parity, and it
        is only discovered when the board will not assemble. KiCad symbols carry
        ki_fp_filters for exactly this; hold the design to them."""
        import fnmatch
        if fp.startswith('EasyEDA:'):
            path = 'easyeda/EasyEDA.pretty/' + fp.split(':', 1)[1] + '.kicad_mod'
            if not os.path.isfile(path):
                raise FileNotFoundError(f'{ref}: imported footprint missing: {path}')
            return
        pats = symlib.get(lib_id).get('fp_filters') or []
        if not pats: return
        name = fp.split(':', 1)[-1]
        if not any(fnmatch.fnmatch(fp if ':' in p else name, p) for p in pats):
            raise ValueError(
                f"{ref} ({lib_id}): footprint {name!r} does not match the "
                f"symbol's permitted packages {pats}")

    def seq(self, pre):
        self._n[pre] = self._n.get(pre, 0) + 1
        return f'{pre}{self._n[pre]}'
    # Rails that can sit above 3.3 V, and the rating a capacitor on them needs.
    # A 22uF 6.3V part on the 12 V AUX rail fails on first power-up, and the
    # value string is the only place a schematic reader will see the
    # difference, so it is put there automatically rather than typed.
    # Everything unmarked is 16 V minimum, X5R or better -- see
    # ref/qualified-parts.md.
    HV = {'VSYS': '25V', 'VBUS': '25V', '+12V': '25V', '+12V_EXT': '25V'}
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

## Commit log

2026-09-02 baseline: EasyEDA exports, BOM, extract.py and derived IR, untouched
    [BOM_Odin_V1.0.0_Odin_0_2026-09-02.xlsx, Cap.schdoc, Odin_0.pcbdoc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]
2026-09-02 extension UX spec: VCCIO=bank VCCO, fixed 3V3, buffered vs direct slots
2026-09-02 ballmap from AMD package file; extension spec corrected to 3 banks / 2 voltage domains / 5 pairs per slot
    [ballmap.py]
2026-09-02 kicad: generated Artix-7 symbol (7 units) + CSG325 footprint + skeleton schematic, ERC clean of generation defects
    [odin.kicad_sch]
2026-09-02 kicad: full 289-part project - PSRAM x4, RP2350B supervisor, 9 slots, power tree, 4-layer board
    [odin.kicad_pcb, odin.kicad_sch]
2026-09-02 fix: all six feedback dividers were wrong; now computed from E96 and verified against Vref
    [odin.kicad_sch]
2026-09-02 wire the four fast lanes: 2 populated SFP cages + 2 reserved, 125MHz refclk, supervisor-gated power, self-describing over I2C
    [odin.kicad_sch]
2026-09-03 schematic is now six grouped pages with power symbols, not a cloud of parts
    [fpga.kicad_sch, highspeed.kicad_sch, memory.kicad_sch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]
2026-09-03 power input: single USB-C with CH224K PD sink at 9V, Schottky OR-ing, degraded 5V mode; record missing board-ID pins
    [highspeed.kicad_sch, memory.kicad_sch, power.kicad_sch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]
2026-09-03 assume 5V for function, PD only for headroom: boost 12V AUX from the 5V rail
    [highspeed.kicad_sch, memory.kicad_sch, power.kicad_sch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]
2026-09-03 supervisor flash: document the role, add BOOTSEL series resistor
    [highspeed.kicad_sch, power.kicad_sch, supervisor.kicad_sch]
2026-09-03 fix boot deadlock (+3V3 now always-on off VSYS) and VBUS overvoltage hazard (switch, not diode)
    [highspeed.kicad_sch, memory.kicad_sch, power.kicad_sch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]
2026-09-03 audit response: fix 5V-overstressed translators, add USB ESD protection and keying posts, load the PCB, reconcile every stale doc
    [highspeed.kicad_sch, odin.kicad_pcb, power.kicad_sch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]
2026-09-03 regenerate after audit fixes
    [odin.kicad_pcb]
2026-09-03 fix 14 package mismatches, assert footprints against ki_fp_filters, rebalance fuses, correct JTAG and PD-voltage claims
    [highspeed.kicad_sch, memory.kicad_sch, odin.kicad_pcb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]
2026-09-15 Update Odin hardware design, imported parts, and documentation
    Include EasyEDA symbols, footprints and 3D models; revise FPGA allocation, power and extension buses; add qualification audits and user documentation.
    Validation: EasyEDA audit, qualified parts, power budget and Python syntax pass. KiCad ERC reports 1 error and 319 warnings; DRC reports 90 violations, 499 unconnected items and 209 schematic parity issues. This is a work-in-progress design snapshot. Imported vendor assets retain their original formatting.
    [fpga.kicad_sch, highspeed.kicad_sch, memory.kicad_sch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]
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2026-10-23 Through-hole extension headers, AUX supply rework, and board state before rev A cleanup
    J3/J5 become single 2x32 through-hole bodies with IO IO GND rows and a long
    grounded key post per zone. Power sheet reworked around the AUX rail.
    Decoupling moved off B.Cu. New footprints, 3D models and check scripts.
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2026-10-23 Mode straps to 1 k, drop the bottom-side decoupling rule, add depth and gate tools
    UG470 Table 2-4 wants the M[2:0] straps at 1 k or less. The board is
    assembled on one side, so place.py no longer flips the FPGA decoupling to
    B.Cu. tools/depth.py reports the escape depth of every assigned U1 ball and
    tools/gate.py runs the per-phase checks and prints the report numbers.
2026-10-23 Remove the AUX lab rail: J68 feeds AUX_RAIL straight into the ten branch PTCs
    Decision D1 of the rev A plan. The LM5157 SEPIC (U28, L10, D12), the
    cap-selected 9/12/15/24 V feedback ladder (J67, U29, Q5-Q8, D13-D16) and
    the REG/AUX/RAW source selector J66 are gone, 43 parts in all. The AUX
    pin of every power row is now fed only from the AUX IN screw terminal
    through its slot's 33 V PTC. The SMBJ22A clamp plus a charged 24 V
    output could exceed the LM5157 SW pin's 50 V absolute maximum, and the
    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
2026-10-23 FPGA decoupling per UG483 Table 2-2, and stage new footprints below the staged ones
    The XC7A100T-FGG676 decoupling network is now the one UG483 v1.14
    prescribes for this device and package, in the Table 2-5 bodies: a 330 uF
    D-case tantalum, 1210 and 0805 ceramics and 0.47 uF 0603s per supply and
    per I/O bank, with one 47 uF per voltage group of up to four VCCO banks.
    MGTAVCC/MGTAVTT (UG482's) and VCCADC keep their 100 nF per ball. 92
    parts replace the 110 of the one-100nF-per-ball scheme. The new parts take
    refs C301..C392 so they do not inherit the script-made 0402 positions
    around U1; reserve() keeps every later C ref where it was placed.
    ref/decoupling.md records the tables and the placem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
2026-10-23 Fast Links out, Network in: RTL8211FD-CG on RGMII, ETH jack, LINK P and LINK Q
    The two SFP ports, their cages, the 125 MHz oscillator, the power gate and
    the I2C switch leave the design, and with them the SFP nets on the board
    controller (GPIO32-39 and 46 are spare, GPIO14/31 carry the status expander's
    I2C). Both GTP quads stay powered per UG482 with grounded RX and one RCAL
    each.
    A Network sheet replaces them: an RTL8211FD-CG gigabit PHY on RGMII at 2.5 V
    with its straps, reset, interrupt, MDIO pull-up, crystal and jack LEDs wired
    from the datasheet rev 1.7 tables, a HanRun HR911130A 1000Base-T magjack,
    and two plain shielded 8P8C jacks that carry eight DC-coupled LVDS_25 pairs
    from bank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
2026-10-23 Give the fabric a clock: 50 MHz oscillator on a bank 14 MRCC ball
    Preparing the constraints file showed that nothing clocked the FPGA fabric:
    X2 only ever fed the GTP reference input, Y1 belongs to the RP2350 and the
    PHY's receive clock exists only with a link up. X4, a YXC OT322550MJBA4SL
    50 MHz CMOS oscillator, now drives SYS_CLK into bank 14 on an MRCC P ball,
    allocated before the PSRAM pairs so it reaches the bank's MMCMs; the
    allocator check verifies the placement. Tri-state pin tied high, 100 nF
    bypass, 33 ohm at the source.
    floorplan.md is rewritten for the rev A board: three jacks on the top
    edge, the network strip, the oscillator next to U1 and the UG483
    decoupling placement rule.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
2026-10-23 Board constraints from the allocator, and a Vivado gate that builds a bitstream
    tools/gen_xdc.py renders ref/freya.xdc from tools/alloc.py: one PACKAGE_PIN
    and IOSTANDARD per allocated ball (LVCMOS33 on banks 13/14/15/34 at the
    3.3 V jumper position, LVCMOS25 for RGMII and LVDS_25 with DIFF_TERM for the
    link pairs in bank 16), the four input clocks and the SPIx4 configuration
    properties. The same run writes gateware/gate/top.v, a throwaway design that
    uses every constrained port; gateware/gate/run.tcl takes it through Vivado
    2026.1 to a bitstream on xc7a100tfgg676-2. The run passes: no DRC checks,
    no critical warnings, timing met. gate.py now fails on XDC drift as it does
    on netlist drift, a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
2026-10-23 Eight layers: JLC08161H-1080A stackup, 100 ohm and RGMII classes replace MGT
    gen_pcb.py --rules-only now writes an 8-layer board: F.Cu, In1 GND, In2
    signal, In3 power, In4 GND, In5 signal, In6 GND, B.Cu, with JLC's
    JLC08161H-1080A dielectrics (template saved in ref/). The outer prepreg is
    the same 1080 as before, so the saved 100 ohm solver geometry carries over
    to the LVDS link pairs and the PHY's MDI pairs; the twelve RGMII lines get
    their own class at an estimated 50 ohm width. The MGT class is gone with
    the transceivers, the island classes no longer name SFP nets, and the 100
    ohm clearance rule applies to tracks only so QFN pads do not trip it.
    Placement untouched; the gate passes with t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
2026-10-27 Explain every part: role text in the schematic, the PCB and a parts guide
    tools/roles.py says what each part is for: a paragraph per schematic group,
    a line per active part, notes on nets such as straps, and derived lines for
    resistors and capacitors (bypass, pull-up, series, and the part they serve).
    gen_project.py puts the text in each symbol's Description and a paragraph
    inside every group box; load_pcb.py copies it into each footprint's
    Description field; tools/roles.py --write renders ref/parts-guide.md.
    gate.py fails on an unexplained part on a covered sheet or a stale guide.
    The FPGA and Network sheets are written; the other four follow.
2026-10-27 Explain the remaining four sheets: power, memory, board controller, slots
    Every part and group on the board now has its plain-words purpose, and the
    gate enforces it on all six sheets. Net notes can cover a family of nets
    by prefix, so regulator feedback, enables and the PSRAM series resistors
    read correctly; passives credit their group's IC or connector rather than
    a key post; monitor nets are no longer mistaken for supplies; parts that
    are not fitted say so. PCB synced with no footprint moved.
2026-10-27 Show each part's purpose on a single click in the PCB editor
    load_pcb.py now also writes the role text as the footprint's library
    description, which KiCad shows in the bottom message bar when a part is
    clicked and as Library Description in the Properties panel. The
    Description field stays as well. No footprint moved.
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2026-10-29 Step 2: bank 13 to 1.8V and the PSRAM move
    SN74LXC8T245 datasheet SCES916A (rev. March 2023), section 6.3
    Recommended Operating Conditions, page 5: VCCA 1.08 V to 5.5 V, so the
    A side runs from +1V8_IO. Table 5-1 (page 3) states the same range on
    the VCCA pin. Copy in ref/datasheets/sn74lxc8t245.pdf.
    APS6404L-SQN-SN: datasheet rev 4.0, Table 9 page 26 (VDD 1.62 to 1.98 V,
    ICC 7 mA), section 4.1 page 5 (SOP-8L(150): D 4.90, E1 3.90, E 6.00 BSC,
    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
2026-10-29 Decoupling numbering: a new rail's 47uF appends; the sync keeps group membership
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2026-10-29 Notes: the VCCAUX filter sits at U1; islands and city in the report
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2026-10-29 Power path: U34 mux replaces the Q2 bypass, U11/U14 always on, PD defaults to 5 V, USB series resistors, native controller pins
2026-10-29 PSRAM power-up states with PUDC_B high; TPS22953 for the jumpered PIN V exports
2026-10-29 Tools: honest gate verdicts, source-side island ownership, key posts at their rows, J1 pads clear of the holes, budget checks for capacitance, inductors and sources
2026-10-29 City plan applied: the G and H key posts stand at their own power rows
2026-10-29 Island X4: the 50 MHz oscillator with its bypass and source resistor
2026-10-29 Island U34: the +5V source mux with its dividers, soft start and bulk
2026-10-29 Island Q3: the 9 V request switch with the CFG1 pull-up and its gate pull-down
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2026-10-29 Island U7 extended: USB series resistors and the two PIN V monitors
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2026-10-29 Island U1 extended: the PSRAM and SDRAM source resistors at the FPGA escape
2026-10-29 Island U8: the controller flash with its bypass and the BOOTSEL resistor
2026-10-29 Island Y1: the controller crystal with its load capacitors and damping resistor
2026-10-29 City re-applied with the key posts placed: G/H on the board at their rows, L/M with the top bus rows
2026-10-29 Re-audit corrections, part 1: U34 selects by intent (Q6 hold, Q7 screw input), FCS_B pull-up, TPS22953 PG grounded, IN2 bypass, budget per path with recovery accounting, source policy
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2026-10-29 Island U34 re-applied: the IN2 bypass at its pin; the hold transistors now in their own islands
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2026-10-29 Island J57 re-applied: PIN V fuse and bulk capacitor inboard, clear of the key post
2026-10-29 Island J58 re-applied: PIN V fuse and bulk capacitor inboard, clear of the key post
2026-10-29 Island U23 re-applied: CT and BIAS capacitors at their pins (profile TPS22953)
2026-10-29 Island U24 re-applied: CT and BIAS capacitors at their pins (profile TPS22953)
2026-10-29 City re-planned and applied: U11 and U34 open the regulator door, X4 reseated at the SYS_CLK ball on U1's left, L/M rows on the bus headers' lattice, key posts back at position 1
2026-10-29 City re-planned and applied: U34 closes the regulator door with U11 against it, Q6/Q7 as its satellites on PR1, the PSRAMs kept on the bank-13 side
2026-10-29 City re-planned as districts: the owner's seven points encoded as rules (LED dashboard with silkscreen labels, PSRAM 2x2 block, PIN V control corners, USB story, serial memory shelf, regulator rows, 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
2026-10-30 Slot A-D strip mirrored across its centre line: power headers, fuses, caps and posts between the edge and J3, J3 inboard (islands.py --mirror, new)
2026-10-30 Slot A-D strip on the keyed lattice: header pins on columns 1..7, key post on column 8 one pitch outside the header line, AUX fuse above the post, cap/fuse stack centred (islands.py --strip, new); E-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
2026-10-30 PHY island relaid in place on the turned U30 (islands.py --anchor U30 --stay): 26 passives re-ringed on the new orientation, the XO series resistor and one load capacitor at the crystal side; the oth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
2026-10-30 RP2350 island relaid in place (islands.py --anchor U7 --stay): L1, CIN, COUT, the AVDD RC filter at pins 61-65 on the top edge per RP2350 datasheet 6.3.8 Figure 26, the decoupling ring re-formed arou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
2026-10-30 E-H slot strip snapped onto the A-D strip's column line: J5 and its 32 strip parts shifted +1.176 mm in y as one body (islands.py --shift), rotations and the owner's AUX fuse positions kept; the two 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
2026-10-30 U9/U10: SN74LXC8T245PWR replaced by SN74LVC8T245PWR (LCSC C27643), the JLCPCB-library part with the same TSSOP-24 pinout; KiCad's SN74LVC8T245 symbol instead of the renamed AVC8T245 copy, VCCA/VCCB 1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
2026-10-30 U30: RTL8211FD-CG replaced by RTL8211FDI-CG (LCSC C692886), the industrial-grade twin that is in the JLCPCB library; identical QFN-40 pinout and LDO core mode, same land pattern, symbol and pin-type 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
2026-10-30 U13/U14/U16: TLV62569DRLR replaced by TLV62569PDRLR (LCSC C398364), the power-good variant the JLCPCB library still stocks; same SOT-563 pinout, pin 6 is PG and stays unconnected as SLVSDG1C allows f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
2026-10-30 L2/L3: Bourns SRN6045TA-4R7M replaced by Sunlord SWPA6045S4R7MT (LCSC C78804) in the budget's inductor table, Isat 4.97 A guaranteed and Irms 3.30 A from the SWPA6045S catalog; the 3 A rails keep the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
2026-10-30 J1: HCTL HC-TYPE-C-16P-01A mid-mount replaced by Korean Hroparts TYPE-C-31-M-12 (LCSC C165948), top mount; KiCad's footprint for this exact part, checked against the HRO drawing (the EasyEDA import's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
2026-10-30 J71/J72: Kinghelm KH-RJ45-58-8P8C replaced by Ckmtw R-RJ45R08P-B000 (LCSC C386756), the plain shielded 8P8C in the JLCPCB library; land from the import checked against the Ckmtw drawing, its two 3.25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
2026-10-30 J7/J8: HCTL PM254-2-08-Z-8.5 replaced by the 2.54-2*8P female socket (LCSC C30734) the JLCPCB library stocks; same 2x8 odd/even pad numbering, land pattern kept under the new number, symbol imported;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
2026-10-30 Slot power rows J53-J58, J62-J65: XFCN PM254V-11-07-H85 replaced by Boom B254N02-0B7P51-H85C32 (LCSC C41426870), 1x7 female 8.5 mm rated 3 A per contact as the fused slot rails need; same land kept u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
2026-10-30 J73: Amphenol 10029449-001RLF replaced by 10029449-111RLF (LCSC C427307); sheet 4 of the Amphenol drawing shows the same contact pattern and 1.30 mm shell holes as the -x01x sheets KiCad's footprint 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
2026-10-30 U23/U24: TPS22953DSQR replaced by TPS22975DSGR (LCSC C524777), WSON-8 from the import; VIN, VBIAS from +3V3, ON from EXT_EN, CT 1 nF, VOUT, GND; EXT_FAULT stays U21/U22/U26 only, and the documents no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
2026-10-30 U26: TPS259470ARPWR replaced by TPS25942ARVCR (LCSC C181295), WQFN-20 from the import; UVLO 3.74 V and OVP 10.07 V from one 110k/24.9k/14.7k string, ILIM 44.2k (2.01 A), dVdT 10 nF (1.2 V/ms), IMON 1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
2026-10-30 U18: WCH CH224K replaced by Hynetek HUSB238_002DD (LCSC C7471904), DFN-10 from the import, on I2C1 (GPIO14 SDA, GPIO31 SCL, 4.7k pull-ups); straps ask 5 V at 1.5 A on their own, firmware asks 9 V ove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
2026-10-30 U11/U12: Diodes AP63300WU-7 replaced by TI LMR33630ADDAR (LCSC C841384), HSOIC-8 from the import; EN tied to VIN so both still start by themselves, PG open, 1 uF VCC and 220 nF 50 V input bypass adde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
2026-10-30 U15: Silergy SY8047QDC replaced by TI TPS564201DDCR (LCSC C464812), SOT-23-6; divider 3.09k/10k for the 0.760 V reference (0.995 V, SLVSDJ7B Table 2), 4.7 uH within the table's range with L7 now the 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
2026-11-03 Board outline 100 x 140 mm with 2 mm chamfers and four M3 holes; rails on one 2.54 mm lattice, edge connectors flush, J50/J68 wire entry outward; missing parts into their groups, frames refitted, isl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
2026-11-03 PSRAM0/1 routed: R104-R115, C337, C341, C394 moved, both ports complete through their resistors to U2/U3 with pull branches; 12 LINK and HDMI differential escapes with GND stitching, onward routing u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
